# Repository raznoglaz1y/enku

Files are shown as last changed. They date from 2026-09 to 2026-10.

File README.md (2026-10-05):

<p align="center">
  ENKU animated e-paper logo
</p>

<h1 align="center">ENKU</h1>

<p align="center">
  <strong>A pocketable e-reader you can actually own — repairable, local-first, distraction-free.</strong>
</p>

<p align="center">
  A focused, low-power 3.97″ reader with physical controls, local file management, no account or cloud requirement, and a documented, extensible hardware/software stack.
</p>

<p align="center">
  <strong>Project website:</strong> <a href="https://enkureader.com">enkureader.com</a>
</p>

<p align="center">
  <strong>UI languages:</strong> EN · PL · DE · FR · ES · IT · RU
</p>

---

## What is ENKU?

ENKU is a compact e-reader project currently validated around the **Waveshare ESP32-S3-ePaper-3.97** platform with an **800 × 480** e-paper display, while a dedicated portrait-first ENKU mainboard is being developed in parallel. The 3.97″ target is intentional: R0.1 remains a genuinely pocketable reader rather than growing into a small conventional e-reader.

The goal is not to reproduce a full tablet or build a feature-heavy general-purpose device. ENKU is intended to be a **small, calm and purpose-built reader**: fast enough for books, simple to operate, comfortable to use offline, and understandable from both the software and hardware side.

The project is being developed as a complete product system rather than only a firmware demo. It includes:

- firmware and device architecture;
- a complete non-touch UI for physical controls;
- library and reading workflows;
- typography and per-book settings;
- Wi-Fi and local browser-based file management;
- storage and import flows;
- sleep and power-management behavior;
- enclosure development and mechanical iterations;
- reproducible documentation for the hardware, firmware and enclosure;
- a custom ENKU mainboard and costed path toward small-batch community / kit builds.

> **Current status:** firmware architecture and reader runtime are actively implemented, while the custom ENKU R0.1 mainboard is in late routing / pre-production verification. Power routing and the USB-C connector/ESD/CC area have clean native KiCad checkpoints; USB data completion, dock/unrouted closure, final mechanical/electrical audit and the manufacturing package remain before fabrication. Features are only treated as complete when their repository checks or physical validation support that claim.

### Looking for hardware partners and component suppliers

ENKU is currently looking for **hardware partners, distributors and component suppliers** interested in supporting the development of the project.

The most useful forms of support at this stage are:

- Waveshare ESP32-S3-ePaper-3.97 development units;
- Li-Po batteries suitable for a compact e-reader enclosure;
- buttons, switches, fasteners and other enclosure hardware;
- prototype and replacement components for hardware testing;
- project discounts or sample units;
- technical information about supplied components;
- support for future hardware revisions and enclosure prototypes.

Partners can be credited in the project documentation and repository as hardware partners or component suppliers where appropriate.

The goal is to build ENKU around readily available, reproducible parts rather than one-off or inaccessible hardware.

For partnership or supply discussions, please open an issue or contact the project owner through GitHub.

## Custom mainboard and future kits

The reference Waveshare platform is useful for firmware bring-up, but ENKU is also being engineered as its own compact hardware platform.

The custom mainboard roadmap targets:
- ESP32-S3 + 3.97″ e-paper in a portrait-first PCB;
- physical page controls, hard power-off, BMI270 motion/orientation sensing and magnetic-cover support;
- USB-C as the primary charge/data connector;
- optional magnetic pogo/dock charging;
- a warm adjustable frontlight path promoted to production-candidate research after repeated community feedback;
- Pro-ready frontlight and wireless-charging population options;
- one core PCB that can support Base / Cover / Pro variants through DNP/population choices.

After validation, the project may offer small-batch **electronics kits, Base kits, magnetic-cover kits and Pro/frontlight kits**. These are planned possibilities rather than products currently for sale; final contents and pricing depend on tested hardware, sourcing, compliance and fulfillment.

The intent is to keep DIY builds fully documented even if assembled kits become available.

### Product decisions after the first community review

The first broad r/ereader review sharpened the product direction rather than changing the Pocket target. ENKU R0.1 stays at **3.97″**. The strongest recurring feedback was that open source alone is not enough differentiation, so the project is prioritizing the parts that must be better at the hardware/product level: **repairability, physical controls, battery life, screen-to-body ratio, direct USB storage access and a credible warm-frontlight path**.

The firmware roadmap now includes **USB Mass Storage / direct microSD access**, **Markdown reading**, and logical control remapping for left/right-handed use in portrait and landscape. CrossPoint compatibility will be investigated rather than treating community firmware as something ENKU should exclude.

A separate **compact 4.7–5.2″, preferably 4:3** hardware direction is being researched for later; it is not a replacement for the pocket 3.97″ device.

### R0.1 engineering checkpoint — October 2026

The dedicated ENKU mainboard has progressed beyond placement into detailed routing and verification. The current working baseline is intentionally kept **green in native KiCad CI** while remaining USB and dock routing is iterated.

Fabrication is gated on:

- complete USB D+/D− routing through connector-side ESD and series tuning resistors to ESP32-S3;
- dock detect/power closure and an explicit **zero-unrouted-connections** check;
- final power, EPD high-voltage, return-path, antenna keepout, connector-edge and repairability review;
- final footprint/orientation and mechanical-access audit;
- reproducible Gerber, NC drill, BOM and pick-and-place outputs plus a final PCBWay viewer review.

A green DRC alone is not considered a fabrication release: R0.1 must also pass the explicit connectivity and manufacturing gates above.

## Support ENKU

ENKU is developed publicly, while production-sensitive engineering may remain private until it is mature enough to release. You can help the project without spending money:

- **Star the repository** to make the project easier to discover.
- **Test and report issues** when firmware and hardware builds are available.
- **Contribute** code, documentation, translations, UI feedback, hardware notes or enclosure work — see [CONTRIBUTING.md](CONTRIBUTING.md).
- **Share ENKU** with people interested in open hardware, e-paper and compact readers.

GitHub Sponsors is the project's primary funding channel. Sponsorships help cover development hardware, prototype boards, batteries, enclosure iterations and other direct project costs.

**Sponsor ENKU:** https://github.com/sponsors/raznoglaz1y

Project contact and support page: **https://enkureader.com/contact**

## Follow the project

ENKU is entering its first public community-feedback stage. The immediate goal is to validate the reader, the custom R0.1 hardware and the mechanical design with e-reader, maker and repairability communities before any manufacturing commitment is made.

A **small production run / crowdfunding campaign is being considered after hardware validation**, but no campaign, launch date, price or production quantity is being promised yet. Development remains public and technical feedback is welcome now.

- Project site: https://enkureader.com
- GitHub: https://github.com/raznoglaz1y/enku
- Reddit launch draft: [docs/outreach/reddit-r-ereader.md](docs/outreach/reddit-r-ereader.md)
- Hackaday project draft: [docs/outreach/hackaday-project-draft.md](docs/outreach/hackaday-project-draft.md)

## Project goals

ENKU is being designed around a deliberately narrow set of product goals:

- provide a **comfortable, distraction-free reading experience** on a compact e-paper device;
- remain useful **fully offline**;
- use **physical controls** instead of depending on a touchscreen;
- keep book storage, reading progress and settings under the user's control;
- support a clean local workflow for importing and managing books;
- make the firmware, interfaces, hardware assumptions and repair path understandable, with source/design releases tied to product maturity;
- stay small enough to be a practical everyday reader rather than a general-purpose tablet.

## Non-goals

ENKU is **not** intended to become:

- an Android-like general-purpose device;
- a multimedia tablet;
- a cloud-dependent reading service;
- a storefront or DRM ecosystem;
- a notification-heavy connected gadget;
- a platform that hides core reading features behind an account.

The project favors a smaller, coherent feature set over adding functionality that does not improve reading.

## Why ENKU?

### Reading first

The interface is built around one job: **reading**. The reader screen stays visually quiet, controls appear only when needed, and common actions are reachable without navigating through deep menus.

### E-paper from the beginning

ENKU is designed specifically for e-paper constraints rather than adapting a conventional LCD interface afterward. Refresh behavior, focus states, progress updates, sleep screens and interaction density are all treated as part of the product architecture.

### Physical controls, no touchscreen dependency

The UI is designed for buttons and deterministic focus navigation. Focus, selected values and active states are separate concepts, which keeps the interface predictable and accessible without touch.

### Offline by default

Books remain usable without Wi-Fi. Connectivity is an optional management layer, not a requirement for reading.

### Open, understandable and user-owned

The project aims to document not only the final code, but also **why** design and implementation decisions were made. UI rules, navigation behavior and product decisions are documented publicly. Production-sensitive PCB, manufacturing and sourcing work may remain private during active development and be released selectively after the design stabilizes.

### Compact hardware target

A 3.97″ panel keeps the device small enough to carry easily while still providing a practical 800 × 480 reading canvas. Both portrait and landscape orientations are part of the design system.

## Design preview

The interface is being designed in English first and then localized. The boards below are current **EN design previews** from the active UI revision work; they are not yet firmware screenshots.

<table>
<tr>
<td width="50%">ENKU Library grid design preview</td>
<td width="50%">ENKU first-start language design preview</td>
</tr>
<tr>
<td align="center"><strong>Library</strong></td>
<td align="center"><strong>First start / Language</strong></td>
</tr>
<tr>
<td width="50%">ENKU Book details design preview</td>
<td width="50%">ENKU Library list design preview</td>
</tr>
<tr>
<td align="center"><strong>Book details</strong></td>
<td align="center"><strong>Library / List</strong></td>
</tr>
</table>

The production visual source of truth remains the Figma design system and approved review boards.

---

## Target hardware

The current reference platform is:

| Component | Target |
| --- | --- |
| Main board | Waveshare ESP32-S3-ePaper-3.97 |
| MCU | ESP32-S3 |
| Display | 3.97″ e-paper, 800 × 480 |
| Input | Up / Function / Down control + BOOT; PWR handled separately |
| Storage | microSD / local storage workflow |
| Connectivity | Wi-Fi, BLE available at platform level |
| Power | Li-Po battery; final pack and runtime profile to be validated on hardware |
| Enclosure | Custom 3D-printable case, developed after mechanical verification |

The current official Waveshare source maps the active-low navigation inputs to GPIO4 (Up), GPIO5 (Function), GPIO6 (Down) and GPIO0 (BOOT). ENKU keeps raw GPIO details inside the platform layer and maps them to stable logical actions. PWR is treated separately through the PMU. Physical behavior will still be verified on the received board.

### Parts status

| Part | Current status |
| --- | --- |
| Waveshare ESP32-S3-ePaper-3.97 | **Selected / ordered** |
| 3.97″ 800 × 480 e-paper panel | **Part of reference platform** |
| microSD storage | **Platform feature — hardware verification pending** |
| Li-Po battery | **TBD — ~2000 mAh target, final size/connector pending** |
| Physical controls | **Platform controls to be mapped and tested** |
| Power switch / enclosure hardware | **TBD** |
| Fasteners | **TBD after mechanical measurements** |
| 3D-printed enclosure | **Planned after hardware measurement** |

See the detailed [Hardware baseline](docs/hardware.md) and [BOM status](docs/bom.md).

## Planned reader experience

### Library

- grid and list views;
- persistent sort and filter state;
- All / New / Reading / Finished filters;
- Title / Author / Recently opened / Recently added sorting;
- global title/author search independent from the active browse filter;
- bounded/paged result queries for large libraries;
- book details and cover handling;
- reading-state indicators;
- progress persistence;
- empty/error states designed as first-class screens.

### Reading

**Reader v1 formats:** EPUB, FB2 and TXT. PDF is deferred to a later revision.

- distraction-free reading view;
- portrait and landscape;
- semantic position preservation after layout changes;
- table of contents;
- bookmarks;
- in-book search;
- finished-book state;
- restore to the previous reading position.

### Typography

Five built-in presets are planned:

**Spacious · Comfortable · Standard · Compact · Dense**

Each preset controls font size, line spacing and margins. Manual adjustment switches the book to **Custom**. Settings can be global or overridden per book.

The current reading typeface target is **Noto Sans**.

### Local file management

The first management workflow is intentionally local:

- upload one or many books from a browser on the same network;
- drag-and-drop transfer;
- view storage usage and free space;
- inspect and correct metadata;
- replace or remove covers;
- safely delete or replace book files;
- show import progress and errors;
- reset progress or per-book settings.

Reading itself does not depend on this web interface.

### Wi-Fi

Planned Wi-Fi behavior includes:

- saved networks;
- explicit trusted/preferred networks;
- deterministic reconnect behavior;
- password entry using the shared on-device keyboard;
- session-scoped local web management;
- no cloud account requirement.

### Sleep and power

ENKU separates **panel sleep**, **device suspend** and **full PMU power-off**.

- user-facing Sleep means a measured system-level low-power state, not only `EPD_Sleep()`;
- static sleep screens suitable for e-paper;
- optional book-cover sleep screen;
- Wi-Fi off during Sleep;
- no live clock or animation while sleeping;
- auto-sleep suspended during writes/imports;
- full Power Off uses the board PMU shutdown path;
- exact suspend mechanism, wake sources and battery thresholds are validated on real hardware.

---

## Current limitations

ENKU is still in the pre-firmware stage, so several important decisions remain intentionally open:

- there is no production reader firmware yet, but the first framework-neutral TXT parser, forward-pagination, Reader Engine and ReaderSession MVPs are now implemented and host-testable;
- a framework-neutral C++ firmware scaffold now exists under `firmware/`;
- the firmware architecture, Library/storage model, parser abstraction, pagination model and runtime state machine are specified, while hardware integration and reader implementation remain pending;
- Reader v1 is scoped to EPUB, FB2 and TXT; PDF support is deferred and not yet designed;
- the exact CBOR codec library, localization table generator, diagnostics backend and parser/rendering stack are not selected;
- the final system suspend mechanism and wake-source mapping have not yet been measured on the real board;
- partial/region refresh behavior and ghosting thresholds have not yet been measured on the real panel;
- battery model and real-world runtime are not finalized;
- physical button mapping and wake behavior still require hardware testing;
- the enclosure has not been dimensioned from the production board yet;
- current EN design boards are design previews, not screenshots from running firmware.

These are active development items, not hidden assumptions.

## Firmware direction

Firmware has not yet been published as a working reader. The planned implementation is split into clear subsystems so the project can evolve without coupling the UI directly to storage or parser internals.

### Core layers

1. **Hardware abstraction**
   - display driver and refresh policy;
   - buttons and input events;
   - storage;
   - Wi-Fi;
   - battery/power state.

2. **Application state / Library**
   - stable `book_id`-based Library records;
   - bounded Browse/Search query model;
   - library index;
   - current book;
   - reading position;
   - bookmarks;
   - settings;
   - network state.

3. **Reader engine**
   - shared normalized parser/document interfaces;
   - first TXT parser MVP implemented in C++;
   - first forward text-pagination MVP implemented in C++;
   - first concrete DocumentReaderEngine implemented over the paginator;
   - ReaderSession with deterministic visited-page Previous and previous/current/next working-set cache;
   - Reader runtime integration updates AppState/progress and emits PageTurn refresh requests;
   - Open → Reading, Back → Library checkpoint and Finished transitions are now modeled in runtime;
   - concrete TXT book-loader/document-provider owns BookDocument → ReaderEngine → ReaderSession lifetime;
   - EPUB and FB2 parser adapters still pending;
   - normalized metadata/document model;
   - on-demand pagination using a font/text measurement abstraction;
   - typography presets;
   - semantic position mapping;
   - search and table of contents.

4. **Runtime and startup**
   - staged boot with boot-loop detection;
   - Normal / First Start / Recovery boot modes;
   - deterministic book open / page navigation;
   - Reader Menu and Search context;
   - debounced progress persistence;
   - sleep/wake restoration;
   - recoverable error handling.

5. **UI system**
   - reusable status bar, headers, rows, buttons and dialogs;
   - focus navigation;
   - portrait/landscape layout;
   - localization through stable semantic string keys;
   - English fallback with generated compact locale tables;
   - render plans describing only visible changes.

6. **Refresh Manager**
   - Region / Full / Deferred / None update classes;
   - bounded serialized refresh queue;
   - dirty-region coalescing and stale-plan removal;
   - measured ghosting/full-refresh escalation;
   - panel-refresh diagnostics.

7. **Persistence layer**
   - versioned CBOR records;
   - separate Library / settings / per-book state;
   - A/B generation recovery;
   - debounced progress checkpoints;
   - schema migration and integrity validation.

8. **Diagnostics and recovery**
   - stable structured error codes;
   - localized user-facing error mapping;
   - bounded in-memory logs;
   - compact critical/reboot diagnostics;
   - boot-loop detection and Recovery/Safe Mode.

9. **Local management service**
   - upload/import;
   - metadata operations;
   - storage status;
   - safe replace/delete transactions.

A framework-neutral C++ interface scaffold now exists under [firmware/](firmware/). The exact framework, build system, display library and parser stack will be chosen after display bring-up, memory profiling and real-device tests.

---

## Enclosure development

The enclosure is a separate project track, not an afterthought.

The plan is to develop the case in stages:

1. **Mechanical verification**
   - measure the production board;
   - verify display stack height, connectors, controls and battery space;
   - establish safe internal clearances.

2. **Functional prototype**
   - simple printable shell;
   - reliable access to controls and charging;
   - battery retention;
   - serviceable assembly.

3. **Ergonomic iteration**
   - comfortable grip;
   - practical button placement;
   - reduced thickness where mechanically safe;
   - portrait and landscape handling.

4. **Production-ready open model**
   - printable case files;
   - screw/assembly specification;
   - tolerances and print notes;
   - alternative battery/case variants where useful.

No final mechanical dimensions will be published as authoritative until the actual hardware is measured.

---

## Project roadmap

**At a glance:**  
**Design system → Hardware bring-up → Reader MVP → Connectivity → Enclosure → Open release**

### Phase 1 — Product and UI foundation

- [x] Define ENKU product direction
- [x] Select Waveshare ESP32-S3-ePaper-3.97 as reference platform
- [x] Define non-touch interaction model
- [x] Build reusable UI foundations and component rules
- [x] Audit the initial screen set
- [x] Define EN as the canonical UI language
- [ ] Finish canonical EN review boards
- [ ] Complete storage/import and Wi-Fi screen revisions

### Phase 2 — Hardware bring-up

- [ ] Verify board revision and physical controls
- [ ] Bring up the e-paper panel
- [ ] Characterize full/partial refresh behavior and ghosting
- [ ] Verify microSD and persistent storage
- [ ] Measure Active / DisplayIdle / Suspended / PoweredOff current
- [ ] Validate wake/power-off behavior
- [ ] Confirm typography rendering and memory use

### Phase 3 — Reader MVP

- [x] Select Reader v1 formats: EPUB, FB2 and TXT; PDF deferred
- [ ] Implement staged boot coordinator and first-usable-screen checkpoint
- [ ] Implement Refresh Manager queue and render-plan pipeline
- [x] Connect PageNext/PagePrevious runtime events to ReaderSession/AppState
- [x] Implement Reader open/back/finished runtime transitions
- [ ] Connect the firmware scaffold to verified platform drivers
- [x] Add ReaderSession page history/cache and deterministic Previous
- [ ] Expand pagination beyond TXT paragraphs and add real font metrics
- [ ] Implement EPUB/FB2 parsers and complete text layout
- [ ] Implement LibraryService/index and grid/list navigation
- [ ] Implement CBOR persistence and reading-position checkpoints
- [ ] Implement typography presets and Custom mode
- [ ] Add bookmarks and table of contents
- [ ] Add in-book search
- [ ] Add sleep/restore flow

### Phase 4 — Import and connectivity

- [ ] microSD import
- [ ] validation and duplicate handling
- [ ] local Wi-Fi upload
- [ ] browser-based library management
- [ ] metadata and cover editing
- [ ] transactional replace/delete behavior
- [ ] interruption and recovery handling

### Phase 5 — Enclosure

- [ ] Measure final hardware
- [ ] Build first functional case prototype
- [ ] Test battery placement and assembly
- [ ] Refine ergonomics
- [ ] Publish printable enclosure files and assembly notes

### Phase 6 — Release quality

- [ ] Finalize canonical EN string catalog
- [ ] Add RU/PL/DE/FR/ES/IT UI translations
- [ ] Validate missing-key fallback and long translated strings
- [ ] Run portrait/landscape layout validation
- [ ] Test malformed books, missing storage and interrupted transfers
- [ ] Validate reboot and power-loss recovery
- [ ] Validate boot-loop detection, Recovery Mode and diagnostic export
- [ ] Publish reproducible build instructions
- [x] Define software/documentation/hardware licensing model
- [ ] Tag the first public reader release

A more detailed implementation roadmap lives in [ROADMAP.md](ROADMAP.md).

---

## UI and design system

The UI source of truth is being developed in Figma and documented in this repository.

Key rules:

- non-touch interaction;
- focus is not the same as selection;
- both **800 × 480 landscape** and **480 × 800 portrait** are supported;
- 24 px standard screen inset;
- 48 px baseline button/input height;
- safe default focus for destructive dialogs;
- English is the canonical source language;
- e-paper refresh limitations are treated as product constraints.

Useful documents:

- [Project status](docs/status.md)
- [Architecture](docs/architecture.md)
- [Firmware project structure](docs/firmware-structure.md)
- [Input & physical controls](docs/input-model.md)
- [Power, sleep & wake model](docs/power-model.md)
- [Reader runtime & state machine](docs/runtime-state-machine.md)
- [Pagination & rendering model](docs/pagination-model.md)
- [Pagination MVP](docs/pagination-mvp.md)
- [Reader Engine MVP](docs/reader-engine-mvp.md)
- [Reader Session MVP](docs/reader-session-mvp.md)
- [Reader Runtime Integration MVP](docs/reader-runtime-mvp.md)
- [Book Loader / Document Provider MVP](docs/book-loader-mvp.md)
- [Metadata & parser model](docs/parser-model.md)
- [Licensing model](LICENSES.md)
- [Library & storage model](docs/storage-model.md)
- [Library data model & service interface](docs/library-model.md)
- [Persistence backend](docs/persistence-model.md)
- [Localization architecture](docs/localization-model.md)
- [Errors, logging & diagnostics](docs/diagnostics-model.md)
- [Boot & startup architecture](docs/boot-model.md)
- [Refresh Manager & e-paper update policy](docs/refresh-model.md)
- [Hardware baseline](docs/hardware.md)
- [BOM status](docs/bom.md)
- [UI specification](docs/ui-spec.md)
- [UI audit](docs/ui-audit.md)
- [UI revision plan](docs/ui-revision-plan.md)
- [Screen inventory](docs/screens.md)
- [Navigation model](docs/navigation.md)

## Repository structure

```text
assets/
  branding/         ENKU identity assets

design/
  screens/          historical and current UI boards
  renders/          project diagrams and visual references

firmware/
  README.md                firmware scaffold status and entry point
  include/enku/            framework-neutral core/input/reader/service interfaces

docs/
  architecture.md          system architecture
  firmware-structure.md    source layout and module boundaries
  input-model.md            physical controls and logical input mapping
  power-model.md            panel sleep, system suspend and PMU power-off
  runtime-state-machine.md  reader runtime and recovery behavior
  pagination-model.md       text layout and pagination rules
  pagination-mvp.md         first TXT → BookDocument → page implementation
  reader-engine-mvp.md      first BookDocument → Reader PageResult bridge
  reader-session-mvp.md     deterministic Next/Previous session navigation
  reader-runtime-mvp.md     page events → AppState → refresh integration
  book-loader-mvp.md        Library/source → parser → ReaderSession lifecycle
  parser-model.md           metadata normalization and parser abstraction
  storage-model.md          Library identity, state and transactional storage
  library-model.md          book records, browse/search queries and LibraryService
  persistence-model.md      CBOR records, schema versioning and crash recovery
  localization-model.md     string keys, fallback, plurals and locale packaging
  diagnostics-model.md      structured errors, bounded logs and Recovery Mode
  boot-model.md             staged startup, restore and boot-loop handling
  refresh-model.md          render plans, refresh queue and ghosting policy
  hardware.md              verified/planned hardware baseline
  bom.md                   parts/BOM status and sourcing priorities
  status.md                current project status
  UI and interaction specifications

locales/
  README.md          localization source-catalog rules

README.md           project overview
ROADMAP.md          implementation roadmap
NOTICE.md           third-party asset and release notes
```

The `firmware/` directory now contains the framework-neutral interface scaffold. Hardware-specific implementations and build files will be added after verified board bring-up. Hardware and enclosure source directories will be added when those workstreams contain verified material.

## Localization

**English is the canonical/source UI language.**

Planned first localization wave:

- English
- Russian
- Polish
- German
- French
- Spanish
- Italian

The interface language is independent from book content and keyboard input mode.

ENKU uses English as the canonical/fallback string set, stable semantic keys, named placeholders and a lightweight centralized plural system. Human-readable locale sources are intended to be converted into compact runtime lookup tables rather than parsed as JSON on the device.

## Licensing and source-release policy

ENKU uses a scoped multi-license model for material that is published:

- **Firmware/software:** Apache License 2.0
- **Project documentation:** Creative Commons Attribution 4.0 International (CC BY 4.0)
- **Future project-owned hardware/mechanical source:** CERN Open Hardware Licence Version 2 — Permissive (CERN-OHL-P-2.0)

The ENKU name/logo, historical design boards and third-party assets are not automatically covered by those blanket grants. Their scope and release requirements are documented in [LICENSES.md](LICENSES.md) and [NOTICE.md](NOTICE.md).

GitHub language detection is configured through `.gitattributes` so implementation source is represented by its actual code language instead of documentation/design assets dominating repository statistics.

---

<p align="center">
  <strong>ENKU is being built as a real reading device: small, focused, open and understandable.</strong>
</p>

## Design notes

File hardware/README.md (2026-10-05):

# ENKU hardware — public snapshot

**Public hardware development freeze:** October 2026  
**Snapshot head at policy transition:** `6f9cc8b7d036d55ea0e3e6687e241f3453178391`

ENKU has moved to a **delayed-open / selective-open** development model.

The hardware already present in this public repository remains part of the public project history. It is not rewritten or hidden retroactively.

From this point forward, production-sensitive Reader hardware work continues privately until the appropriate release gate.

Private by default:
- active PCB routing / placement;
- production schematic changes;
- Gerbers / drill / pick-and-place;
- factory-ready BOM and sourcing data;
- DFM / assembly optimization;
- test fixtures and production tooling.

This public tree may still receive selected stable hardware documentation and release snapshots later.

See: [Release & openness policy](../docs/release-policy.md).

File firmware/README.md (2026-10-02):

# ENKU Firmware

This directory contains the ENKU firmware architecture scaffold.

**Status:** the framework-neutral core is host-buildable and tested. The first board-specific target now exists under `platform/esp_idf/` for Waveshare ESP32-S3-ePaper-3.97 storage bring-up. It is not yet a complete reader UI firmware.

## Current scaffold

```text
include/enku/
  core/
    types.hpp
    input.hpp
    power.hpp
    persistence.hpp
    localization.hpp
    settings.hpp
    diagnostics.hpp
    boot.hpp
    refresh.hpp
    library.hpp
    events.hpp
    app_state.hpp
  reader/
    document.hpp
    parser.hpp
    txt_parser.hpp
    pagination.hpp
    reader_types.hpp
    reader_engine.hpp
    document_reader_engine.hpp
    reader_session.hpp
    book_loader.hpp
  runtime/
    reader_runtime.hpp
    library_runtime.hpp
    settings_runtime.hpp
    storage_startup.hpp
    boot_restore.hpp
    sleep_wake.hpp
    power_off.hpp
  services/
    services.hpp
  storage/
    state_file_store.hpp
    cbor_reader_checkpoint.hpp
    cbor_library_service.hpp
    cbor_app_context_service.hpp
    cbor_boot_loop_service.hpp
    cbor_settings_service.hpp
    book_import_service.hpp
    staged_book_import_service.hpp
    book_delete_service.hpp
    book_file_store.hpp
    posix_book_file_store.hpp
    stored_book_source_service.hpp
    posix_state_file_store.hpp
```

The first framework-neutral implementations now include the TXT parser, paginator, DocumentReaderEngine, ReaderSession, reader runtime lifecycle (open/page/back/finished), and the first concrete A/B CBOR per-book checkpoint backend with CRC32 recovery, plus a POSIX filesystem adapter and host-side disk integration tests under `tests/`. A first ESP-IDF SDMMC/FAT filesystem adapter now exists under `platform/esp_idf/`, together with a minimal `app_main` storage smoke test. Display/input/power integration remains the next board bring-up work.

Architecture references:

- [System architecture](../docs/architecture.md)
- [Input & physical controls](../docs/input-model.md)
- [Power, sleep & wake model](../docs/power-model.md)
- [Persistence backend](../docs/persistence-model.md)
- [Global settings model](../docs/settings-model.md)
- [Localization architecture](../docs/localization-model.md)
- [Errors, logging & diagnostics](../docs/diagnostics-model.md)
- [Boot & startup architecture](../docs/boot-model.md)
- [Refresh Manager & e-paper update policy](../docs/refresh-model.md)
- [Firmware structure](../docs/firmware-structure.md)
- [Reader runtime](../docs/runtime-state-machine.md)
- [Pagination model](../docs/pagination-model.md)
- [Pagination MVP](../docs/pagination-mvp.md)
- [Reader Engine MVP](../docs/reader-engine-mvp.md)
- [Reader Session MVP](../docs/reader-session-mvp.md)
- [Reader Runtime Integration MVP](../docs/reader-runtime-mvp.md)
- [Book Loader / Document Provider MVP](../docs/book-loader-mvp.md)
- [Parser model](../docs/parser-model.md)
- [Storage model](../docs/storage-model.md)
- [Library data model & service interface](../docs/library-model.md)

The public source language and code/documentation language for firmware is English.

## Host build and tests

The framework-neutral firmware modules can be compiled and tested on a desktop host with CMake:

```bash
cmake -S firmware -B build -DCMAKE_BUILD_TYPE=Release
cmake --build build --parallel
ctest --test-dir build --output-on-failure
```

The host suite currently covers:

- TXT parsing;
- text pagination;
- Reader Engine;
- ReaderSession navigation;
- Book Loader;
- Reader runtime open/page/back/restore lifecycle;
- Library runtime filtering, sorting, search, focus navigation, focused-book open, staged-import flow and transactional delete;
- CBOR A/B checkpoint generation and corruption recovery;
- persistent CBOR Library index, queries, sorting, paging and summary updates;
- A/B global settings persistence with safe-default recovery and cold-boot application;
- TXT import pipeline with format detection, parse validation, content fingerprinting and duplicate rejection;
- transactional staged-file import from `/system/tmp` into canonical `/books/book-<id>.<ext>`;
- storage startup recovery that loads the Library, cleans stale committed tmp artifacts, and preserves ambiguous uploads;
- persisted last-safe app context and automatic cold-boot restore into Reading at the saved semantic checkpoint;
- Sleep checkpointing plus fast context-only Wake restore without repeating the full storage recovery path;
- graceful Power Off persistence before the platform PMU shutdown request;
- persistent boot-loop protection that enters Recovery before a third consecutive incomplete cold boot can auto-restore again;
- rollback of the final book file when Library commit fails;
- transactional book deletion with Library/source/checkpoint/context cleanup and rollback;
- POSIX filesystem persistence for book files and checkpoints.

GitHub Actions runs the same host suite on pushes to `main` and on pull requests.

## ESP-IDF board target

The first Waveshare ESP32-S3-ePaper-3.97 target lives at:

```text
firmware/platform/esp_idf/
```

It currently provides:

- board pin constants for TF, e-paper and navigation controls;
- 4-bit SDMMC FAT32 mount at `/sdcard`;
- creation of ENKU `/books` and `/system/*` directories;
- `EspIdfFileStore` implementing both `StateFileStore` and `BookFileStore`;
- path-traversal rejection;
- a serial storage smoke test in `app_main`;
- a build-verified SSD1677 800×480 monochrome display driver with full, fast and partial refresh modes;
- a PSRAM-backed ENKU display smoke sequence exercising all three refresh paths;
- active-low GPIO button polling with debounce, long-press/repeat generation, screen-aware logical action mapping and runtime dispatch into Library/Reader/power flows;
- AXP2101 power telemetry and shutdown/light-sleep platform service;
- mono framebuffer boundary and concrete e-paper RefreshService with full/fast/partial routing;
- unified ESP-IDF platform composition root owning storage, display, refresh, power and buttons;
- application storage runtime composition for settings, Library, import/delete, checkpoints, boot-loop state and startup recovery;
- FreeType-backed Noto Sans text measurement and monochrome glyph rendering for the Reader pipeline.

See [ESP-IDF platform bring-up](platform/esp_idf/README.md).

The board target is compiled separately in GitHub Actions against ESP-IDF v5.5.5. The first successful platform build covers both SDMMC storage and SSD1677 full-refresh code.

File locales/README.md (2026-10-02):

# ENKU Locales

English is the canonical source language for the ENKU on-device UI.

Planned Reader v1 locale source files:

```text
en.json
pl.json
de.json
fr.json
es.json
it.json
ru.json
```

The actual string catalog will be added once the canonical EN screen copy is finalized.

Rules:

- English defines the complete key set.
- Translation files may not introduce independent UI semantics.
- Named placeholders must match the English source.
- Runtime firmware should consume generated compact lookup data rather than parse these JSON files on every device boot.
- Missing translations fall back to English.

See [Localization Architecture](../docs/localization-model.md).

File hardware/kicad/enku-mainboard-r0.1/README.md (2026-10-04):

# ENKU Mainboard R0.1 — KiCad worktree

This directory contains the CAD worktree for the custom ENKU mainboard.

Current state:
- portrait 54 × 94 mm four-layer PCB;
- mounting-hole baseline;
- ESP32 antenna, Qi, buttons, microSD, USB-C, Dock and hard-power zones;
- first mechanically sensitive component placement has started;
- J_EPD uses the R0.1 dual-contact 24-pin connector baseline;
- J_FL uses the R0.1 dual-contact 6-pin connector baseline;
- EPD 47 µH inductor and boost MOSFET are now represented in the placement;
- Pro frontlight driver zone and remap field are represented;
- no routing yet.

Important:
- schematic capture remains authoritative for nets and final footprint synchronization;
- several footprints in the PCB are marked as R0.1 placement placeholders and must be replaced/verified against manufacturer land patterns before fabrication;
- no KiCad ERC/DRC has been run in the current environment;
- this is **not fabrication-ready**.

Companion:
- [Placement baseline A](PLACEMENT_R01.md)
- `../../../docs/schematic-netlist-r01.md`
- `../../../docs/r01-blocker-closure.md`

Next:
1. capture the complete schematic;
2. assign/verify exact manufacturer footprints;
3. update the PCB from schematic;
4. reconcile the first placement with actual courtyard/keepout data;
5. route;
6. run ERC/DRC in KiCad;
7. generate PCBWay files only from the checked KiCad project.

## Schematic hierarchy

R0.1 now has a real KiCad hierarchical capture baseline:

- `enku-mainboard-r0.1.kicad_sch` — root sheet
- `power.kicad_sch` — USB/Dock arbitration, charger, hard-off 3.3 V path
- `mcu_io.kicad_sch` — ESP32-S3-WROOM-1-N16R8, shared SPI, I2C, buttons, Hall/IMU/ADC assignments
- `epd_hv.kicad_sch` — 24-pin EPD FPC and SSD1677 external-HV interface boundary
- `frontlight.kicad_sch` — TPS923610 path, 6-pin raw FPC and 0R/DNP remap boundary
- `connectors.kicad_sch` — USB-C, dock, debug and DNP Qi interface

These files are schematic-capture baselines, not a fabrication release. The next gate is to expand the remaining block-level circuits into exact discrete symbols, review every footprint, and run KiCad ERC before routing is treated as electrically authoritative.

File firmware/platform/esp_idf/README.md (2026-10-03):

# ENKU ESP-IDF Platform Bring-up

This directory is the first board-specific ENKU target for the Waveshare ESP32-S3-ePaper-3.97.

It now hosts the reference-board composition root used by the persistent ENKU device runtime: SD-backed storage, SSD1677 refresh, physical input, power, Wi-Fi, FreeType rendering and recovery behavior. Hardware-dependent behavior still requires physical validation on the delivered board.

## Verified board assumptions

Current board constants come from the official Waveshare ESP32-S3-ePaper-3.97 documentation/examples.

### TF / SDMMC

```text
CLK  GPIO16
CMD  GPIO17
D0   GPIO15
D1   GPIO7
D2   GPIO8
D3   GPIO18
```

ENKU mounts the FAT filesystem at:

```text
/sdcard
```

and ensures:

```text
/sdcard/books
/sdcard/system
/sdcard/system/state
/sdcard/system/covers
/sdcard/system/tmp
```

### E-paper full-refresh bring-up

```text
BUSY GPIO3
DC   GPIO9
CS   GPIO10
SCLK GPIO11
MOSI GPIO12
RST  GPIO46
```

The current target now drives the SSD1677 panel over SPI3 at 20 MHz using the vendor-confirmed full-refresh sequence.

## Build

Install and activate a current ESP-IDF environment, then:

```bash
cd firmware/platform/esp_idf
idf.py set-target esp32s3
idf.py build
```

## Flash and monitor

```bash
idf.py -p <PORT> flash monitor
```

Exit the monitor with the normal ESP-IDF monitor shortcut.

## Expected first boot

With a FAT32 TF card inserted, serial output should show:

1. ENKU ESP-IDF platform bring-up;
2. free heap at boot;
3. SD/MMC card information;
4. successful mount at `/sdcard`;
5. `Storage smoke test passed`;
6. SSD1677 initialization;
7. `Sending ENKU framebuffer`;
8. `Full refresh complete`;
9. `E-paper smoke test passed`;
10. `ENKU storage + display bring-up complete`.

The storage smoke test creates:

```text
/system/tmp/platform-smoke.txt
```

reads it back, verifies it appears in directory enumeration, and deletes it.

## Platform storage adapter

`EspIdfFileStore` implements both framework-neutral interfaces:

- `StateFileStore`;
- `BookFileStore`.

Logical ENKU paths such as:

```text
/system/settings.a.cbor
/books/book-123.txt
```

are resolved beneath `/sdcard`.

The adapter rejects path traversal containing `..`.

The existing CBOR Library/settings/checkpoint/import code is connected through these filesystem-facing APIs.

## Storage recovery

Removable storage failure is user-visible rather than a silent platform abort.

- display, power, network and controls initialize before the SD mount attempt;
- a mount/init failure shows `SD FAIL / INSERT SD`;
- a mounted volume that cannot create the required ENKU directories is rolled back completely and shows `SD SETUP FAIL / REPAIR SD`;
- recovery retries the SD mount every two seconds;
- once storage becomes usable, the device performs a clean restart and enters the normal boot path.

The reference board does not expose a dedicated card-detect signal to this firmware path, so a failed SDMMC mount is deliberately reported as “not ready” rather than claiming that the card is definitely absent.

## Current limitations

This first target deliberately does not yet:

- instantiate the complete ENKU runtime graph;
- render the e-paper display;
- scan buttons;
- initialize PMU/battery state;
- configure Wi-Fi;
- verify fsync/power-loss durability on the physical TF card.

Those are separate bring-up steps.

## Display smoke screen

The first display test uses a 1-bit 800×480 framebuffer:

```text
48000 bytes
```

Allocation prefers PSRAM and falls back to ordinary 8-bit-capable heap.

The framebuffer is generated by ENKU code and contains:

- a border;
- large `ENKU` text;
- `DISPLAY BRING-UP`;
- `FULL REFRESH`.

The current driver implements:

- SPI3 initialization;
- manual CS/DC control;
- hardware reset;
- BUSY polling with timeout;
- SSD1677 full-mode initialization;
- monochrome RAM write;
- full refresh;
- panel deep sleep.

Fast refresh and partial refresh are deliberately not yet exposed through the ENKU display API. They will be added and tested as separate modes after the baseline full refresh is validated on the physical panel.

## CI

`.github/workflows/esp-idf-build.yml` builds this target independently from the desktop host tests.

Current CI baseline:

```text
ESP-IDF v5.5.5
target: esp32s3
```

This compile check validates the board target and ESP-IDF APIs even before flashing physical hardware.

## Fast and partial refresh smoke path

The SSD1677 adapter now also exposes:

- fast full-screen initialization;
- fast full-screen refresh;
- fast base refresh;
- partial region refresh.

The vendor reference refresh control values are preserved:

```text
full    0x22 = 0xF7
fast    0x22 = 0xD7
partial 0x22 = 0xFF
```

Current bring-up sequence on one boot:

```text
full ENKU screen
→ fast ENKU screen with FAST REFRESH label
→ partial counter 0
→ partial counter 1
→ partial counter 2
→ panel deep sleep
```

The partial test region is 96×96 pixels and byte-aligned. The API validates bounds and region byte count before touching panel RAM.

Physical validation still needs the real board so we can compare actual refresh time, ghosting and whether the vendor partial window behavior matches the panel revision shipped with the unit.

## Input bring-up

The first ESP-IDF input adapter is `EspIdfButtons`.

Board inputs:

```text
Up       GPIO4
Function GPIO5
Down     GPIO6
BOOT     GPIO0
```

They are configured as active-low inputs with pull-ups.

The platform firmware runs a 12-second interactive smoke test after display bring-up. Serial logs show the physical control, generated press type and framework-neutral logical action.

Current timing baseline:

```text
poll      5 ms
debounce 20 ms
long     650 ms
repeat   700 ms initial / 180 ms interval
```

The Power button is intentionally not treated as a normal GPIO button here; it remains part of the PMU/power-control bring-up.

## Power / AXP2101 bring-up

The current board mapping follows the full Waveshare application reference, not the earlier minimal SD example.

```text
SDMMC:
CLK 16
CMD 17
D0  15
D1  7
D2  8
D3  18

I2C:
SDA 41
SCL 42

AXP2101 address: 0x34
```

`EspIdfPowerService` implements the framework-neutral `PowerService` boundary.

Current telemetry:

- battery %;
- battery mV;
- charging;
- external power/VBUS.

Current controls:

- configure PWR-on timing to 1 second;
- configure hardware PWR-off timing to 4 seconds;
- software AXP2101 shutdown;
- ESP32-S3 light sleep with GPIO wake on Up/Function/Down/BOOT.

The bring-up smoke test only reads/logs telemetry. It does not power the board off automatically.

## Platform composition root

`EspIdfPlatform` now owns the board-specific service graph:

```text
EspIdfSdCard
EspIdfFilesystem
EspIdfStateFileStore
EspIdfBookFileStore
EspIdfEpaper
OwnedMonoFramebuffer
EpaperRefreshService
EspIdfPowerService
EspIdfButtons
```

`EspIdfPlatform::begin()` initializes those dependencies in hardware-safe order:

```text
SD mount
→ e-paper transport / RefreshService
→ AXP2101 power service
→ buttons
```

The bring-up `app_main()` now consumes this composition root instead of constructing parallel board drivers itself.

This is intentionally still a **platform** root rather than the final ENKU `DeviceRuntime`: Reader text measurement/rendering and the complete application renderer still need concrete implementations before the full application controller graph can be owned here.

## Application storage layer on ESP-IDF

The ESP-IDF target now links the real ENKU storage/application subset used by `ApplicationStorageRuntime`:

- settings persistence/runtime;
- Library persistence;
- TXT import;
- staged import;
- delete transaction;
- reader checkpoints;
- app restore context;
- boot-loop marker;
- book source;
- storage startup/recovery.

This is the first board build where the same application persistence code tested on desktop is linked against the physical SD-backed adapters.

The remaining application-runtime blocker is no longer persistence. It is the real Reader rendering path: text measurement, font data and screen composition.

## Reader font engine

The ESP-IDF target now depends on Espressif's FreeType component and includes `FreeTypeTextRenderer`.

Default reader font: Noto Sans Regular is embedded directly in the ESP-IDF application image under SIL OFL 1.1.

An optional SD override can still be provided at:

```text
/system/fonts/NotoSans-Regular.ttf
```

If the override is absent or invalid, FreeType falls back to the embedded firmware asset.

The renderer:

- loads the real TTF from FAT;
- measures UTF-8 text with FreeType advances and kerning;
- derives line height from the face metrics;
- rasterizes glyphs in 1-bit monochrome mode;
- writes directly into `OwnedMonoFramebuffer`.

This keeps Reader pagination and physical rendering on the same metric source.

The embedded Noto Sans asset is the deterministic baseline used for pagination and rendering. A broken SD override never blocks boot; an embedded FreeType initialization failure remains a visible recovery condition.

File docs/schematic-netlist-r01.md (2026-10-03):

# ENKU Mainboard R0.1 — schematic net / block specification

Status: **schematic-capture baseline / exact-footprint and ERC review in progress**

Purpose: define the actual electrical structure that the KiCad schematic must implement before placement/routing.

## 1. Power input tree

Named nets:

- `VBUS_USB`
- `VBUS_DOCK`
- `VBUS_EXT`
- `VBAT`
- `VSYS`
- `3V3_SYS`

Flow:

```text
USB-C VBUS -> USB protection -> TPS2121 IN1
Dock +5V   -> Dock protection -> TPS2121 IN2
TPS2121 OUT -> VBUS_EXT -> BQ25185 IN
BQ25185 BAT -> VBAT
BQ25185 SYS -> VSYS
VSYS -> TPS63802 -> 3V3_SYS
```

R0.1 hard power:
- physical switch controls TPS63802 EN;
- charger remains active when 3V3_SYS is off;
- EPD-HV and frontlight must not remain powered when system-off.

## 2. USB-C

References:

- J1 — USB-C receptacle
- U_USB_ESD — USB ESD device
- R_CC1 / R_CC2 — 5.1 kΩ
- optional R_USB_DP / R_USB_DM series footprints

Signals:

- `USB_DP` -> ESP32 GPIO20
- `USB_DM` -> ESP32 GPIO19
- `VBUS_USB`
- `GND`

No USB-PD requirement for R0.1.

## 3. Dock

Board-side exposed contacts:

1. GND
2. +5V
3. DOCK_DETECT
4. GND

Nets:

- `VBUS_DOCK`
- `DOCK_DETECT`
- `GND`

DOCK_DETECT -> GPIO2 through a defined pull/protection network.

Dock power and USB power must not backfeed each other.

## 4. Battery / charge

Reference:
- U_CHG — BQ25185

Nets:
- `VBUS_EXT`
- `VBAT`
- `VSYS`
- `CHG_STAT1`
- `CHG_STAT2`
- `BAT_TS`

Prototype starting point:
- 4.2 V battery regulation;
- 500 mA input-current limit;
- 300 mA initial fast-charge target.

Production battery temperature protection must use the selected battery/NTC solution.

## 5. 3.3 V system regulator

Reference:
- U_3V3 — **TPS63802DLAR**

Nets:
- VIN: `VSYS`
- OUT: `3V3_SYS`
- EN: `SYS_EN`
- L1/L2: `REG_L1` / `REG_L2`
- FB: `REG_FB`
- PG: `REG_PG`

Hard power switch drives `SYS_EN`.

First-spin support network:
- 0.47 µH Murata DFE201612E-R47M=P2;
- 10 µF + 100 nF on input;
- 2 × 22 µF on output;
- 511 kΩ / 91 kΩ feedback;
- 100 kΩ PG pull-up.

The old TPS63031 candidate is intentionally rejected for R0.1 because boost-mode headroom is too small for simultaneous Wi-Fi + microSD + EPD peaks.

## 6. ESP32-S3

Reference:
- U1 — ESP32-S3-WROOM-1-N16R8

Power:
- 3V3_SYS
- GND

Core pin allocation:
- GPIO19 USB D-
- GPIO20 USB D+
- GPIO12 SPI_SCLK
- GPIO11 SPI_MOSI
- GPIO13 SPI_MISO
- GPIO10 SD_CS
- GPIO14 EPD_CS
- GPIO21 EPD_DC
- GPIO47 EPD_RST
- GPIO48 EPD_BUSY
- GPIO4 BTN_PREV
- GPIO5 BTN_NEXT
- GPIO6 BTN_SELECT
- GPIO7 BTN_BACK
- GPIO8 I2C_SDA
- GPIO9 I2C_SCL
- GPIO18 IMU_INT1
- GPIO17 HALL_INT
- GPIO1 BAT_ADC
- GPIO2 DOCK_DETECT
- GPIO15 CHG_STATUS
- GPIO16 QI_STATUS
- GPIO39 FL_WARM_PWM
- GPIO40 FL_COOL_PWM
- GPIO41 FL_ENABLE
- GPIO43 UART_TX
- GPIO44 UART_RX
- GPIO0 BOOT

Do not load strapping pins GPIO0/3/45/46 in a way that changes boot state.

## 7. microSD

Reference:
- J_SD — microSD connector

Mode:
- SPI for R0.1 common-mainboard path.

Signals:
- SPI_SCLK
- SPI_MOSI
- SPI_MISO
- SD_CS

Add:
- local 3V3 decoupling;
- optional series resistor footprints if signal integrity requires tuning;
- card-detect only if the selected connector provides it at acceptable cost.

## 8. EPD logic connector

Reference:
- J_EPD — 24-pin 0.5 mm FPC

Logical nets:
- EPD_CS
- EPD_DC
- EPD_RST
- EPD_BUSY
- SPI_SCLK
- SPI_MOSI
- EPD_GDR
- EPD_RESE
- EPD_VSH1
- EPD_VSH2
- EPD_VGH
- EPD_VGL
- EPD_VSL
- EPD_VCOM
- EPD_VDDIO
- EPD_VCI
- EPD_VDD
- EPD_VPP
- GND

BS1 is intended LOW for 4-wire SPI.

Exact connector pin numbers remain blocked until current GDEY drawings are directly verified.

## 9. EPD-HV block

This block must be drawn as a dedicated schematic sheet.

Named nets:
- EPD_GDR
- EPD_RESE
- EPD_VGH
- EPD_VGL
- EPD_VSH1
- EPD_VSH2
- EPD_VSL
- EPD_VCOM

Required classes of components:
- external N-MOSFET;
- current-sense resistor;
- inductor;
- Schottky network;
- 50 V-class HV capacitors;
- local logic/core decoupling.

Current provisional values may be shown in notes but must carry a `VERIFY-GOOD-DISPLAY` marker.

Preferred R0.1 EPD-HV starting parts:
- Q_HV: SI1308EDL-T1-GE3;
- D_HV1-D_HV3: MBR0530;
- R_RESE: 2.2 Ω / 1% / 0805;
- L_HV: 47 µH, exact production MPN pending;
- C_HV main: 4.7 µF / 25 V / 0805 X5R/X7R;
- C_HV aux: 1 µF / 25 V / 0805 X7R.

No PCBWay order while the current-panel reference has not been checked or while the final inductor/connector orientation remains generic/TBD.

## 10. BMI270

Reference:
- U_IMU — BMI270

Signals:
- I2C_SDA
- I2C_SCL
- IMU_INT1

Power:
- 3V3_SYS

Required:
- VDD/VDDIO decoupling per Bosch reference;
- I²C pull-ups sized for the final bus;
- orientation marker in schematic and PCB notes.

## 11. Hall sensor

Reference:
- U_HALL — DRV5032-family candidate

Signals:
- HALL_INT -> GPIO17

Power:
- select the exact low-power supply configuration after part-variant freeze.

Placement is mechanically tied to Cover magnet geometry.

## 12. Physical controls

References:
- SW_PREV
- SW_NEXT
- SW_SELECT
- SW_BACK
- SW_BOOT
- SW_POWER

Direct GPIO buttons for PREV/NEXT/SELECT/BACK.

No ADC key ladder in R0.1.

SW_POWER controls SYS_EN, not firmware.

## 13. Battery ADC

Net:
- BAT_ADC -> GPIO1

Use a high-value divider sized to minimize standby drain.

Add:
- RC filter;
- ADC protection margin;
- optional switched divider only if power measurements justify the added complexity.

## 14. Pro frontlight

Separate schematic sheet / population option.

References:
- J_FL — 6-pin 0.5 mm FPC
- U_FL_WARM — prototype current driver candidate
- U_FL_COOL — prototype current driver candidate

Signals:
- FL_WARM_PWM
- FL_COOL_PWM
- FL_ENABLE

Power source:
- final choice must avoid bypassing hard-off.

Driver remains prototype candidate until the current FL0426-S01C pin assignment is verified.

## 15. Pro Wireless

Separate DNP population block.

Reference:
- U_QI — BQ51013C-family candidate

Nets:
- `QI_5V`
- `QI_STATUS`

QI_5V must enter the same protected charging architecture rather than charge the cell independently.

Three-source arbitration remains a sub-block to freeze after USB/Dock/Qi interaction is tested.

## 16. Debug / test

Expose:
- UART TX/RX
- BOOT
- EN/reset service access
- GND
- 3V3_SYS
- VSYS
- VBAT
- VBUS_USB
- VBUS_DOCK
- EPD BUSY/RST
- EPD HV rails where safely probeable

Add current-measurement 0 Ω links where useful:
- VSYS -> U_3V3 input
- optional EPD-HV supply input
- optional frontlight supply input

## 17. PCBWay schematic gate

The schematic can move to PCB placement only when:

- every non-DNP component has an exact MPN or an explicitly approved generic passive specification;
- all connector contact orientations are verified;
- EPD-HV exact parts are frozen;
- no unresolved strapping-pin conflict remains;
- ERC passes;
- variant DNP matrix is generated from the schematic/BOM;
- Base, Pro and Pro Wireless can be built from the intended common PCB without bodge wires.

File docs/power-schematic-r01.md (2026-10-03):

# ENKU custom mainboard R0.1 — power sheet candidate

Status: **schematic-level baseline / not fabrication-frozen**

This document turns the current power architecture into a concrete first schematic target.

The goal is not to maximize charging speed. It is to get a predictable, low-risk power path that works for Base / Cover / Pro / Pro Wireless and preserves margin through a common PCB.

## 1. Core architecture

```text
USB-C VBUS ----\
                > input selector / protected OR ---> BQ25185 IN
Dock 5V -------/
Qi 5V ----------> optional Pro Wireless input path

BQ25185 BAT  ---> 1S Li-Po
BQ25185 SYS  ---> TPS63802 VIN
TPS63802 3V3 ---> ESP32-S3 / microSD / logic / control

Hard OFF ---> TPS63802 EN low
```

Important consequence:

The physical hard-off switch no longer needs to interrupt the battery itself.

BQ25185 remains connected to the battery and external power, so charging continues while the system is hard-off.

TPS63802 provides true shutdown / load disconnect, so it is a strong candidate for making the 3.3 V digital rail genuinely off.

EPD-HV and frontlight rails must also be disabled in hard-off. They may not bypass the switched system architecture.

## 2. BQ25185 baseline values

Primary charger:
**BQ25185DLHR**

Official reference:
https://www.ti.com/product/BQ25185

### Battery regulation / input current limit

Initial ENKU target:
- 1-cell Li-Po;
- 4.2 V battery regulation;
- 500 mA external input-current limit.

TI's published design procedure gives:

- **R_ILIM/VSET = 18 kΩ** for 4.2 V regulation and 500 mA input-current limit.

This is the R0.1 starting value.

### Fast-charge current

Prototype target:
- **300 mA initial fast-charge current**

TI's published design example gives:
- **R_ISET = 1 kΩ** for 300 mA fast charge.

Why start at 300 mA:
- lower thermal load on a compact PCB;
- friendly to the current ~2000 mAh battery target;
- safer before the final cell and enclosure thermal path are known.

After the actual battery is selected and temperature is measured, a 500 mA charge profile can be evaluated.

Do not raise charge current just to advertise a faster number.

### Capacitors

Follow the current TI recommendation:
- IN: at least 1 µF after derating;
- SYS: nominal 10 µF, at least 1 µF after derating;
- BAT: at least 1 µF.

R0.1 placement target:
- C_IN: 4.7 µF, X7R/X5R, **25 V**, plus 100 nF;
- C_SYS: 10 µF, X7R/X5R, **25 V**, plus 100 nF;
- C_BAT: 4.7 µF, X7R/X5R, 10 V or higher.

TI specifically recommends considering 25 V-rated ceramic capacitors on IN and SYS because of DC-bias derating.

### CE

/CE is active low.

Baseline:
- default hardware pull-down so charging works without firmware;
- optional GPIO override/test point if later useful.

Charging must not depend on the ESP32 being powered.

### STAT

STAT1 / STAT2 are open-drain outputs.

R0.1:
- expose at least one status signal to an ESP32 GPIO or test pad;
- avoid mandatory always-on LEDs;
- production status LED remains DNP to protect standby power.

### TS / battery temperature

Production target:
- use a real battery NTC / validated thermal network.

Do not ship a production kit with a fixed resistor that defeats battery temperature protection merely to save BOM.

For prototypes, an explicit documented test resistor may be used only while the final battery pack is unresolved.

## 3. 3.3 V rail

First-spin regulator:
**TPS63802DLAR**

Official reference:
https://www.ti.com/product/TPS63802

Why R0.1 moved away from TPS63031:
- TPS63031 has insufficient boost-mode margin for an intentionally simultaneous ESP32-S3 Wi-Fi + microSD + e-paper workload;
- ENKU should not depend on firmware preventing peak loads from overlapping;
- TPS63802 provides materially more transient/current headroom while preserving buck-boost operation from a 1S Li-Po.

R0.1 baseline:
- VIN: `VSYS`;
- VOUT: `3V3_SYS`;
- EN: `SYS_EN`;
- MODE: LOW for power-save mode;
- PG: `REG_PG`, pulled up with 100 kΩ for diagnostics;
- inductor: **Murata DFE201612E-R47M=P2, 0.47 µH**;
- input: 10 µF + local 100 nF;
- output: **2 × 22 µF**, X5R/X7R, with DC-bias derating checked;
- feedback: **511 kΩ / 91 kΩ** for the 3.3 V target.

Layout rule:
- input/output capacitors sit directly at the converter pins;
- L1/L2-to-inductor loop is extremely short;
- FB divider stays on the quiet side of the converter and away from L1/L2/SW copper;
- power ground and control ground join locally at the IC, not through a long shared return.

### EN / hard power

Preferred architecture:
- hard switch drives TPS63802 EN;
- EN OFF = `3V3_SYS` physically disabled;
- BQ25185 remains alive so battery charging still works.

Add:
- deterministic EN pull state;
- service/test pad on `SYS_EN`;
- test point on `REG_PG`;
- no firmware dependency for true hard-off.

### Current-margin gate

Before production freeze, stress the rail with:
- ESP32-S3 Wi-Fi transmit burst;
- microSD write;
- e-paper refresh;
- Pro frontlight control activity where applicable;
- battery near the low end of the allowed operating range.

Pass criteria are based on measured 3.3 V droop, reset margin and regulator temperature, not merely on nominal current sums.

## 4. USB-C and Dock source selector

Quality-baseline candidate:
**TPS2121**

Official reference:
https://www.ti.com/product/TPS2121

R0.1 intent:
- USB-C VBUS on IN1;
- Dock 5 V on IN2;
- OUT feeds BQ25185 IN;
- source selection configured so reverse current between USB and Dock is blocked;
- current limit chosen above ENKU's normal charging/system demand but below connector/trace safety limits.

Exact PR1 / CP2 / ILM component values are not frozen until the final source-priority behavior is selected.

### Cost-down checkpoint

Before production:
- compare TPS2121 against qualified discrete ideal-diode / MOSFET OR-ing.

Keep TPS2121 unless the discrete solution:
- saves a meaningful amount at 50–100 units;
- preserves reverse-current blocking;
- is safe with simultaneous USB + Dock;
- does not add more placement/test/support cost than it saves.

## 5. USB-C input

USB-C remains USB 2.0 device + charging input.

Keep:
- 5.1 kΩ Rd on CC1;
- 5.1 kΩ Rd on CC2;
- USB ESD protection;
- D+/D- series damping only if required by ESP32-S3 reference design/layout.

VBUS must go into the source-selection / charger path, not directly onto the system rail.

## 6. Dock interface

Four exposed contacts remain the target.

R0.1 electrical allocation:

1. GND
2. +5 V
3. DOCK_DETECT
4. GND

Reason for two ground contacts in R0.1:
- robust first-make / last-break behavior is easier to design mechanically;
- lower contact resistance;
- no need to invent a data bus before the accessory protocol exists.

Future revisions may reuse contact 4 for accessory ID only after mechanical validation.

DOCK_DETECT:
- resistor-coded / dedicated detection;
- input protection;
- GPIO with defined pull state;
- must distinguish Dock Mode from normal USB charging.

## 7. Pro Wireless Qi path

Preferred system architecture:

```text
Qi receiver -> regulated ~5 V -> common external-source path -> BQ25185
```

Candidate receiver:
**BQ51013C family**

Do not use a second independent battery charger unless there is a demonstrated reason.

### Three-source issue

TPS2121 has two inputs.

For Pro Wireless the architecture therefore needs one of:

A. USB + Dock through TPS2121, then ideal-diode OR with Qi before BQ25185;

B. USB + Dock passive/ideal-diode combination, with TPS2121 selecting wired vs Qi;

C. a different 3-input architecture if it proves cheaper/smaller.

This decision is intentionally not frozen yet.

## 8. Pro frontlight electrical envelope

Display:
**GDEY0426T82-FL01C**

R0.1 frontlight baseline:
- **TPS923610DRLR** boost LED driver;
- **TDK VLS252012HBX-100M-1, 10 µH**;
- **15 Ω / 1%** current-sense baseline;
- **4.7 µF / 50 V** output capacitor;
- BSS138-family warm/cool return selectors;
- master `FL_ENABLE` plus independent `FL_WARM_PWM` / `FL_COOL_PWM`;
- 6-pin dual-contact **FH34SRJ-6S-0.5SH(50)** connector;
- 18-position DNP 0 Ω remap matrix so first-article FPC continuity can be corrected without a PCB respin.

The exact warm/cool FPC mapping stays a first-article population decision until the delivered panel is continuity-checked.

## 9. E-paper HV status

The SSD1677 external HV topology is now captured in the R0.1 schematic.

Current 3.97-inch application-circuit baseline:
- `L_EPD`: **TYS5040100M-10, 10 µH**;
- `Q_EPD`: IRLML6346TRPBF;
- D1/D2/D3: MBR0530;
- `R_RESE`: 2.2 Ω / 1%;
- `R_GDR_PD`: 1 MΩ;
- local 4.7 µF booster input capacitor;
- rail capacitors on VGH/VGL/VSH1/VSH2/VSL/VCOM.

The older 47 µH TYS5040470M-10 is no longer the default. It remains a laboratory alternate only because it shares the TYS5040 land pattern.

Production still requires scope validation of VGH/VGL/VSH/VSL/VCOM on first hardware.

## 10. Power BOM freeze gates

Power sheet becomes production-frozen only after:

- final battery part selected;
- BQ25185 thermal charge test;
- USB + Dock simultaneous-source test;
- hard-OFF charging test;
- TPS63802 simultaneous peak-load / droop / thermal test;
- sleep leakage measurement;
- Hall wake/sleep validation;
- Pro frontlight dimming / thermal / optical test;
- Pro Wireless Qi thermal / alignment / interoperability test;
- EPD-HV first-article rail validation.

Until then, this document is the **preferred engineering baseline**, not a fabrication authorization.

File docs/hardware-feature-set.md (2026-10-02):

# ENKU hardware feature set and product variants

Status: **design target / not yet fabrication-frozen**

This document captures the hardware and enclosure decisions that should be supported by the ENKU custom mainboard and firmware.

## Core product principles

ENKU is a portrait-first, read-first e-reader with physical controls. The base mechanical orientation is portrait; landscape remains a software-supported secondary orientation.

The custom mainboard should be designed once and reused across several enclosure/product variants wherever practical. Optional features should therefore use DNP/population options rather than forcing separate PCBs.

## Common R0.1 / R0.x hardware targets

- ESP32-S3-WROOM-1-N16R8
- 3.97-inch 800x480 e-paper display
- microSD
- native USB-C at the **bottom center**
- reserved low-profile magnetic/pogo charging-dock input as an optional secondary 5 V source
- wireless charging support reserved for a future Pro/accessory implementation rather than mandatory Base hardware
- 1S Li-Po
- physical **hard power-off switch at the top-left**
- right-side physical reading controls
- BMI270 6-axis IMU
- Hall sensor footprint for magnetic cover wake/sleep
- reserved frontlight driver + PWM/EN signals for future illuminated variant
- battery voltage measurement
- debug/test pads
- 4-layer PCB
- ESP32 antenna keepout at PCB edge
- EPD HV/analog block based only on validated panel reference design

## Controls and ergonomics

### Right-side reading controls

Preferred physical layout:

1. Previous page
2. Next page
3. Select / Menu
4. Back

Previous/Next are intended to be implemented as a large two-way rocker or two large tact switches under one rocker cap.

Design goals:
- Next should sit closest to the natural resting position of the thumb.
- Select and Back should be smaller and tactually distinct.
- Page-button mapping must be user-remappable.
- Holding Previous/Next may provide accelerated list scrolling.
- Controls remain usable without looking at the device.

### Orientation and handedness

BMI270 enables:
- automatic portrait/landscape detection
- 180-degree portrait flip
- automatic left-hand/right-hand operation
- remembering the last orientation
- optional motion wake
- optional gesture page turning

The UI should support:
- Auto
- Portrait lock
- Landscape lock
- Remember last orientation

When the reader is rotated 180 degrees, logical Next/Previous behavior should follow the new hand position rather than the original physical top/bottom mapping.

## Motion controls

Motion page turn is optional and disabled by default.

Settings target:
- Gesture page turn: Off / On
- Gesture sensitivity: Low / Medium / High
- Wake on pick-up: Off / On
- Auto rotation: Off / On

Initial gesture concept:
- short deliberate left/right flick
- accelerometer wake trigger
- temporary gyro confirmation window
- direction/rebound validation
- cooldown to prevent double page turns
- reject movements associated with ordinary grip adjustment

Physical page controls always remain available; motion control never replaces them.

## Custom mainboard and kit roadmap

The Waveshare board remains the reference platform for early firmware and electrical validation, but ENKU is now also developing a dedicated portrait-first custom mainboard.

Goals for the custom board:
- lower per-unit cost at small production quantities;
- better enclosure fit than a general-purpose development board;
- native placement of the page rocker, hard power switch, BMI270, Hall sensor and future frontlight circuitry;
- a reproducible BOM suitable for community builds and possible assembled kits;
- one PCB with population options for Base / Cover / Pro rather than separate electronics for every enclosure.

Possible future product formats, only after hardware validation:
- **Electronics kit** — assembled mainboard + display + controls/hardware;
- **Base kit** — electronics + battery + printable/finished enclosure hardware;
- **Cover kit** — Base kit plus magnetic folio;
- **Pro kit** — frontlight-populated electronics and matching optical/mechanical parts.

These are a development and commercialization roadmap, not a statement that kits are currently for sale. Final kit contents, pricing, safety/compliance work and fulfillment model must follow prototype validation.

## Charging interfaces

USB-C remains the primary and universal charging/data connector.

The board should also reserve a secondary charging input so the enclosure family can support a dock without redesigning the whole PCB.

Preferred secondary interface:
- **4-contact magnetic pogo/dock connector** on the lower rear or lower edge;
- two contacts may be paralleled for +5 V / GND or the extra contacts can be used for dock detect / accessory ID;
- connector should be keyed/asymmetric so reverse placement cannot swap polarity;
- secondary 5 V input must be isolated/ORed with USB-C VBUS before the charger/power-path stage.

Wireless charging is a **Pro / optional population target**, not a Base requirement:
- reserve coil area and receiver/charger pads or a small receiver-module interface;
- validate coil, ferrite shield, heat and magnet interaction in the final enclosure;
- avoid placing the Qi coil in the ESP32 antenna keepout or directly under sensitive e-paper circuitry;
- do not promise Qi certification until a complete receiver implementation is tested.

Cost rule: Base ENKU should not carry the full BOM/assembly cost of wireless charging. Pogo charging may be a low-cost accessory option; Qi should be DNP or implemented in Pro.

## Hard power architecture

The top-left switch provides a real hardware system-off state.

Target behavior:
- ESP32, microSD and e-paper system rails are disconnected in OFF.
- USB-C charging remains available while the reader is switched OFF.
- Daily operation uses sleep/wake.
- Hard OFF is intended for storage, travel, service and complete shutdown.

## Magnetic cover support

The mainboard should include a low-power Hall sensor footprint and suitable interrupt routing.

Target UX:
- opening magnetic cover wakes ENKU
- closing cover puts ENKU to sleep
- feature may be disabled in Settings
- hard power switch remains independent

The cover magnet location must be defined jointly with the enclosure after Hall sensor placement is frozen.

## Frontlight-ready architecture

The base PCB should reserve:
- frontlight driver footprint
- PWM signal
- EN signal
- LED power rail connection
- connector/test pads for the light guide / LED assembly

Base ENKU ships with these parts DNP.

The illuminated variant may populate them without requiring a fundamentally different mainboard.

Frontlight settings target:
- Brightness
- Quick-menu brightness control
- Auto-off with sleep
- Optional low-brightness night preset

Color-temperature mixing is explicitly out of scope for the first frontlight revision unless testing proves that the extra LEDs, driver channels and optical stack are worthwhile.

## Enclosure/product variants

### 1. ENKU Slim

Purpose: simplest, lightest and cheapest build.

- portrait-first
- no cover attached
- no frontlight
- hard power top-left
- USB-C bottom-center
- right-side page rocker + Select + Back
- BMI270 motion/orientation support
- Hall sensor may remain populated or DNP depending final cost
- thin 3D-printable shell

This is the reference open-source enclosure.

### 2. ENKU Grip

Purpose: maximum one-hand comfort.

- same electronics as Slim
- slightly wider grip area on the control side
- sculpted / chamfered rear grip
- larger rocker cap
- center of mass biased toward the lower-middle part of the device
- reversible 180-degree operation for left-hand use

This enclosure prioritizes reading comfort over visual symmetry.

### 3. ENKU Cover

Purpose: everyday carry and screen protection.

- magnetic folio cover
- Hall-sensor wake/sleep
- magnetic closure
- cover magnet positioned away from IMU and sensitive power/display circuitry
- case geometry protects page controls from accidental presses
- USB-C remains accessible with cover installed
- optional stand/fold geometry may be explored later

The cover should be removable/replaceable and should not require a different PCB.

### 4. ENKU Pro

Purpose: premium reading variant while preserving the same software/platform.

Includes:
- frontlight optical stack
- populated frontlight driver
- brightness controls
- Hall sensor as standard
- Cover compatibility as standard
- BMI270 motion/orientation controls
- same physical page-button philosophy

The main engineering difference from base ENKU is the display/frontlight stack and populated lighting circuit, not the compute platform.

## Mechanical priorities shared by all variants

- portrait is the primary orientation
- screen centered visually rather than forcing chassis symmetry
- right-side control/grip area may be wider than left bezel
- battery placement should keep center of mass near the lower-middle area
- bottom USB-C must not interfere with little-finger support
- hard power switch must be difficult to trigger accidentally
- page controls should be quiet, low-travel and easy to identify by touch
- enclosure should allow display replacement without destroying the PCB
- antenna area must remain free of metal, magnets and dense copper

## PCB population strategy

A single board should ideally support:

| Feature | Base | Cover | Pro |
| --- | --- | --- | --- |
| BMI270 | populated | populated | populated |
| Hall sensor | optional/populated | populated | populated |
| Frontlight driver | DNP | DNP | populated |
| Frontlight connector | populated/test pads | populated/test pads | populated |
| Hard power | populated | populated | populated |
| Right-side buttons | populated | populated | populated |

This keeps the open-source platform coherent and avoids maintaining separate firmware/hardware branches for every case.

## Next hardware steps

1. Rotate the board concept to portrait-first mechanical orientation.
2. Re-place USB-C to bottom center and hard power to top-left.
3. Place page controls on the right-side edge for thumb reach.
4. Place BMI270 close to the mechanically stable center region.
5. Add Hall sensor candidate location and keep magnet keepout in enclosure CAD.
6. Reserve the frontlight driver/connector area as DNP.
7. Keep EPD HV/analog block reserved until the panel reference design is validated.
8. Add a costed 4-pin pogo/dock charging footprint and input-protection/OR-ing reservation.
9. Reserve Pro-only wireless charging coil/receiver geometry without burdening Base BOM.
10. Produce a new portrait-first Gerber placement preview and keep a per-variant BOM/cost model.

## ENKU Dock and Dock Mode

A separate optional ENKU Dock is now part of the hardware roadmap.

The mainboard should reserve a protected 4-contact pogo interface on the lower rear of the reader. Dock presence should be detected explicitly so firmware can distinguish a desk dock from ordinary USB charging.

While docked, ENKU may enter a configurable low-refresh dashboard mode with options such as:
- clock / date / battery;
- current book and reading progress;
- reading-goal dashboard;
- cached weather or local status cards;
- user-defined static text/dashboard presets.

The first dock should stay passive: pogo contacts, alignment magnets/mechanics and USB-C power input. No dock MCU is required.

See [Dock and Dock Mode](dock-mode.md) for the electrical, firmware and validation plan.

## Display family strategy

### Base / Electronics / Cover

Primary display candidate: **Good Display GDEY0397T81P**

- 3.97-inch
- 800 × 480
- approximately 235 ppi
- SSD1677
- no frontlight
- 24-pin 0.5 mm FPC

Source:
https://www.good-display.com/product/613.html

### Pro / Pro Wireless

Primary display candidate: **Good Display GDEY0426T82-FL01C**

- 4.26-inch
- 800 × 480
- approximately 218 ppi
- SSD1677
- bonded warm/cool frontlight
- 24-pin EPD FPC + separate frontlight FPC

Source:
https://www.good-display.com/product/880.html

The older GDEQ0426T82-FL01C is treated as legacy/EOL and should not be the new design target.

Replacement reference:
https://www.good-display.com/product/1208.html

The design goal is to keep one core mainboard for both display families where the verified FPC pinout, HV requirements and mechanics allow it.

## Variant BOM ceilings

Internal design stop-limits:

| Variant | Landed BOM ceiling |
| --- | ---: |
| Electronics Kit | PLN 155 |
| Base | PLN 180 |
| Cover | PLN 200 |
| Pro | PLN 230 |
| Pro Wireless | PLN 260 |
| Dock | PLN 40 |

These values are not announced retail prices. They are engineering constraints used before final routing.

See:
- [Competitive analysis](competitive-analysis-2026-10.md)
- [Multi-variant BOM architecture](bom-architecture.md)

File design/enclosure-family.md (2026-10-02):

# ENKU enclosure family

Status: concept specification for future CAD work.

The enclosure family is intentionally based on one main PCB wherever possible.

## Common physical language

All variants share:
- portrait-first layout
- bottom-center USB-C
- top-left hardware power switch
- right-side page controls
- 3.97-inch display
- compact rounded enclosure
- replaceable rear shell
- printable prototype geometry

## Variant A — Slim

Reference open-source shell.

Target character:
- minimal
- light
- inexpensive
- easy to print
- easy to disassemble

Suggested construction:
- front bezel/frame
- PCB/display carrier
- rear shell
- four M2 fasteners or snap-fit + limited fasteners

No permanent cover or frontlight.

## Variant B — Grip

Ergonomic one-hand shell.

Changes from Slim:
- wider right-hand grip zone
- gentle rear bulge or wedge around the palm
- larger page rocker cap
- slightly deeper local cavity around buttons
- battery positioned to avoid top-heavy balance

The device can be rotated 180 degrees for left-hand operation.

## Variant C — Cover

Slim/Grip-compatible magnetic folio.

Elements:
- replaceable magnetic front flap
- Hall wake/sleep magnet
- magnetic closure point
- protective lip around display
- relief around hardware power switch
- button guard geometry to reduce presses in a bag

The magnet must be tested for interference and its final position must follow Hall-sensor placement.

## Variant D — Pro

Illuminated version.

Changes:
- frontlight light guide / diffuser stack
- LEDs and light-management geometry
- potentially slightly thicker front bezel
- populated frontlight electronics
- Hall sensor and cover support standard

A Pro Cover may share the same external attachment strategy as Cover if thickness permits.

## CAD deliverables planned

For each variant:
- STEP
- STL
- exploded assembly render
- dimension drawing
- printable prototype profile
- button-cap/rocker part
- battery pocket definition
- PCB mounting points

Cover-specific:
- folio front
- hinge
- magnet pockets
- Hall alignment drawing

Pro-specific:
- frontlight stack cross-section
- LED/light-guide carrier
- thermal/optical clearance model

## Design rule

Case concepts must follow the PCB and display stack. Do not distort the board solely to make a render look cleaner; mechanical and electrical constraints stay authoritative.

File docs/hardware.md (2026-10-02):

# ENKU Hardware Baseline

This document tracks the current hardware target and separates **verified facts** from **planned or unverified choices**.

## Reference platform

| Area | Current target | Status |
| --- | --- | --- |
| Main board | Waveshare ESP32-S3-ePaper-3.97 | Selected / ordered |
| MCU | ESP32-S3 | Platform-defined |
| Display | 3.97″ e-paper, 800 × 480 | Platform-defined |
| Input | Physical controls, non-touch UI | GPIO mapping implemented; physical feel to verify |
| Storage | microSD / local file workflow | SDMMC/FAT platform adapter implemented; hardware timing to verify |
| Connectivity | Wi-Fi / BLE capability | Wi-Fi STA lifecycle implemented; BLE deferred |
| Battery | ~2000 mAh Li-Po target | Final pack TBD |
| Charging | Board-integrated behavior | To verify |
| Enclosure | Custom 3D-printable case | Starts after measurement |

## What will be verified on arrival

### Board and controls

- exact production revision;
- onboard control type and mapping;
- GPIO behavior where relevant;
- wake-capable inputs;
- connector placement.

### Display

- actual usable refresh modes;
- full-refresh time;
- partial-refresh support and limits;
- ghosting behavior;
- contrast in real reading layouts;
- effect of repeated UI updates.

### Storage

- microSD wiring and interface;
- filesystem support;
- file size / performance limits;
- safe-write behavior during power loss.

### Power

- charging behavior;
- active current;
- reading/idle current;
- sleep current;
- wake behavior;
- practical battery runtime;
- battery voltage/percentage mapping.

## Battery target

The working target is a **single-cell 3.7 V Li-Po around 2000 mAh**, thin enough for a compact reader enclosure.

A previously considered mechanical envelope is approximately **5 × 50 × 60 mm**, but this is not yet a final specification.

Final selection depends on:

- real internal space after board measurement;
- connector type and polarity;
- board charging limits;
- protection circuit;
- thermal/mechanical clearance;
- enclosure thickness target.

No battery model should be treated as final until physically validated.

## Mechanical verification

Before starting the final enclosure, record:

- PCB outline;
- display active area and glass outline;
- total display stack thickness;
- board/display offsets;
- connector protrusions;
- control travel and access;
- screw/mounting features;
- battery keep-out area;
- cable bend radii;
- safe bezel overlap.

The enclosure will be based on these measurements rather than catalog assumptions.

## Planned enclosure variants

The first goal is **one reliable baseline case**.

Only after that is stable, possible variants may include:

- different battery thickness/capacity;
- alternative back shell;
- stand/cover attachment;
- revised button geometry.

The project will avoid fragmenting into many mechanical variants before the baseline design is proven.

## Vendor-confirmed controls

Current official Waveshare source identifies the onboard navigation inputs as active-low GPIOs with pull-ups:

| Control | GPIO | Current vendor naming |
| --- | ---: | --- |
| Up | GPIO4 | Button_Up |
| Function / press | GPIO5 | Button_Function |
| Down | GPIO6 | Button_Down |
| BOOT | GPIO0 | Boot |

The official ESP-IDF example polls these controls with a 5 ms timer and a software button state machine rather than GPIO interrupts.

The PWR key is handled through the AXP2101 PMU path. The current vendor example configures a 1 s power-on press and a 4 s hardware power-off press.

ENKU's logical mappings are documented in [Input & Physical Controls](input-model.md). These source-derived mappings will still be physically verified on the production board when it arrives.

## Vendor-confirmed power behavior

The current official Waveshare application distinguishes panel sleep from full PMU shutdown:

- `EPD_Sleep()` sends the e-paper controller into deep sleep, but the ESP32 application continues running;
- the current full vendor application does not use ESP32 deep sleep as its normal product sleep flow;
- full software power-off calls the AXP2101 shutdown path;
- the vendor PMU setup uses approximately 1 s PWR hold for power-on and 4 s for hardware power-off.

ENKU therefore treats **DisplayIdle**, **Suspended** and **PoweredOff** as separate product states.

The final suspend mechanism and wake sources remain pending real-board measurements. See [Power, Sleep & Wake Model](power-model.md).

## First ESP-IDF bring-up target

ENKU now has an isolated board target under `firmware/platform/esp_idf`.

The board-specific target now covers storage, display, input, PMU, Wi-Fi and the first application runtime.

The current board mapping follows Waveshare's **complete board application reference** rather than the earlier minimal e-paper example.

### TF / SDMMC

| Signal | GPIO |
| --- | ---: |
| CLK | 16 |
| CMD | 17 |
| D0 | 15 |
| D1 | 7 |
| D2 | 8 |
| D3 | 18 |

The target uses 4-bit SDMMC and mounts FAT at `/sdcard`.

The earlier minimal Waveshare example used GPIO39–44 for SDMMC; ENKU does **not** use that mapping because the complete board reference reserves GPIO41/42 for I²C/AXP2101.

### E-paper pins

| Signal | GPIO |
| --- | ---: |
| BUSY | 3 |
| DC | 9 |
| CS | 10 |
| SCLK | 11 |
| MOSI | 12 |
| RST | 46 |

These display pins are now used by the first ENKU SSD1677 driver. The current milestone implements vendor-aligned SPI3 full-refresh initialization, monochrome framebuffer transfer, BUSY timeout handling and panel deep sleep.

The storage adapter implements the same `StateFileStore` and `BookFileStore` contracts used by the host-tested persistence/runtime code. The current ESP-IDF target now links that application persistence layer directly against the physical SD-backed adapters.

## SSD1677 full-refresh baseline

The first ENKU panel driver now follows the Waveshare reference full-refresh path:

```text
reset
→ BUSY ready
→ SWRESET
→ SSD1677 full-mode registers
→ 800×480 RAM window
→ write 1-bit framebuffer
→ display update
→ BUSY ready
→ deep sleep
```

The ESP-IDF target uses SPI3 mode 0 at 20 MHz with manual CS, matching the current official Waveshare example.

The driver is compile-verified in GitHub Actions against ESP-IDF v5.5.5. Physical refresh quality, orientation, timing and ghosting still require validation on the delivered board.

## Fast and partial refresh baseline

The platform driver now includes the Waveshare reference refresh modes in addition to full refresh.

Fast mode uses the vendor fast initialization sequence and update control `0xD7`.

Partial mode programs a byte-aligned RAM window, writes only the region buffer, and triggers update control `0xFF`.

The current smoke firmware deliberately exercises all three modes in one boot so physical bring-up can verify:

- full-refresh orientation and mapping;
- fast-refresh latency and ghosting;
- partial-window coordinates;
- repeated partial update artifacts.

## Corrected full-board SD / I2C mapping

The complete official Waveshare firmware for this board uses a different SDMMC pin map from the early/basic e-paper example.

For ENKU board integration we now follow the full board reference:

### SDMMC

| Signal | GPIO |
| --- | ---: |
| CLK | 16 |
| CMD | 17 |
| D0 | 15 |
| D1 | 7 |
| D2 | 8 |
| D3 | 18 |

### Shared board I2C

| Signal | GPIO |
| --- | ---: |
| SDA | 41 |
| SCL | 42 |

The AXP2101 PMU address is `0x34`.

This resolves the apparent GPIO41/42 conflict: it came from mixing the minimal e-paper example's SD map with the complete board firmware's I2C map.

## AXP2101 power baseline

The first ENKU ESP-IDF power service now talks directly to AXP2101 through the native ESP-IDF I2C master driver.

Current capabilities:

- battery percentage;
- battery voltage;
- charging state;
- external/VBUS power presence;
- vendor-aligned PWR on/off timing setup;
- software PMU shutdown;
- light-sleep request with GPIO wake on navigation controls.

The firmware smoke test reads and logs power telemetry but deliberately does **not** call software shutdown automatically.

## RefreshService integration

The SSD1677 driver is now wrapped by `EpaperRefreshService`, which implements the framework-neutral `RefreshService` contract.

This is the first point where application runtime refresh requests are translated into physical panel behavior.

The renderer/display boundary uses a 1-bit `MonoFramebufferSource`; the current owned implementation stores the full 800×480 frame and can extract byte-aligned dirty regions for partial updates.

## Current integrated device runtime

The ESP-IDF board target now composes:

```text
SDMMC/FAT
→ state + book stores
→ CBOR settings/library/checkpoints/context
→ storage startup/recovery
→ Noto Sans / FreeType measurement + rendering
→ Library + Reader runtime
→ 1-bit framebuffer
→ EpaperRefreshService
→ SSD1677
```

Physical controls are polled every 5 ms and flow through:

```text
GPIO
→ PhysicalInputEvent
→ LogicalAction
→ InputDispatcher
→ Library / Reader / Sleep-Wake / Power-Off
```

The application path is persistent rather than a finite smoke script. With the Reader font provisioned on the TF card, firmware renders the initial Library and then remains in the device input loop.

Hardware smoke tests remain available behind `CONFIG_ENKU_BRINGUP_SMOKE_TESTS` while the first physical unit is being validated.

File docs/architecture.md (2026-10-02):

# ENKU Architecture

This document describes the intended high-level architecture of ENKU before the firmware implementation is locked down.

The goal is to keep the reader understandable, testable and modular: display/input/storage code should not leak into book parsing, and reader logic should not depend directly on the web-management layer.

## Architectural decisions

The following decisions are now part of the ENKU firmware baseline:

1. **Event-driven UI**  
   ENKU does not use a continuous frame/redraw loop. Button presses, navigation, page turns, setting changes, Wi-Fi events, import events and power events produce application events. Rendering happens only when visible state actually changes.

2. **Single application state model**  
   Logical product state is centralized rather than duplicated inside screens. This includes current screen, current book, semantic reading position, orientation, focus, Library view/filter/sort, global settings, per-book settings, Wi-Fi state and power state.

3. **Reader Engine is independent from UI**  
   The UI requests laid-out reading content from the Reader Engine. Parser/layout/pagination internals remain separate from screen code.

4. **Semantic reading position instead of page number**  
   Reading progress is anchored to book structure/text position rather than a rendered page index. Page numbers are unstable because typography, margins and orientation can change pagination.

5. **Dedicated Refresh Manager**  
   UI code describes what became dirty; a separate refresh layer decides whether to use a regional/partial update, a full update, combine updates, or defer them.

6. **No invisible redraws**  
   If application state changes but nothing visible on the current screen changes, the e-paper panel is not refreshed. For example, saving reading progress or a hidden Wi-Fi state change must not redraw the reading page.

## System overview

```mermaid
flowchart TD
    INPUT[Physical controls / system events]
    EVENTS[Event queue]
    STATE[Application state]
    READER[Reader engine]
    UI[UI composition]
    PLAN[Render plan / dirty regions]
    REFRESH[Refresh manager]
    HW[Display driver / hardware]
    DATA[Persistent data]

    INPUT --> EVENTS
    EVENTS --> STATE
    STATE --> UI
    STATE --> READER
    READER --> UI
    UI --> PLAN
    PLAN --> REFRESH
    REFRESH --> HW
    STATE --> DATA
    READER --> DATA
```

## 1. Event model

ENKU firmware should react to discrete events instead of continuously repainting UI state.

Examples:

- ButtonPressed
- ButtonReleased / ButtonHeld
- PageNext
- PagePrevious
- ScreenOpened
- SettingChanged
- OrientationChanged
- BookOpened
- BookPositionChanged
- ImportProgressChanged
- ImportCompleted
- WiFiConnected
- WiFiDisconnected
- BatteryStateChanged
- SleepRequested
- WakeRequested

Events update application state first. Rendering is a consequence of state changes, not the primary control flow.

This is important for e-paper because it reduces unnecessary refreshes, ghosting and power use.

## 2. Application state

A single logical state model should own product-level state such as:

- current screen / overlay;
- current book;
- semantic reading position;
- current focus target;
- orientation;
- UI language;
- Library view mode;
- Library filter and sort;
- focused/visible Library item;
- global reading settings;
- per-book reading overrides;
- bookmarks;
- saved/trusted networks;
- Wi-Fi state;
- battery/power state;
- active import/transfer state.

Screens should not own long-lived product state that must survive navigation, orientation change, sleep or reboot.

## 3. Reader engine

The Reader Engine is responsible for turning structured book content into renderable reading pages.

A conceptual request from the UI looks like:

```text
layoutPage(
    book,
    semanticPosition,
    typography,
    viewport
)
```

The engine returns:

- renderable page content;
- semantic position represented by the page;
- previous semantic position;
- next semantic position;
- reading-progress information;
- optional structural context such as chapter/section.

The UI does not need to know how EPUB, FB2 or TXT content is internally parsed.

The format adapter and metadata normalization rules are defined in [Metadata & Parser Model](parser-model.md).

The text layout, pagination and rendering rules are defined in [Pagination & Rendering Model](pagination-model.md).

The first concrete bridge from an opened normalized document to Reader-level page results is defined in [Reader Engine MVP](reader-engine-mvp.md).

Runtime transitions for opening, reading, search, sleep/wake and recovery are defined in [Reader Runtime & State Machine](runtime-state-machine.md).

The initial source/module layout and framework-neutral interfaces are defined in [Firmware Project Structure](firmware-structure.md).

The hardware-grounded button mapping and logical input actions are defined in [Input & Physical Controls](input-model.md).

The separation between display sleep, system suspend and PMU power-off is defined in [Power, Sleep & Wake Model](power-model.md).

The canonical string-key, fallback and pluralization strategy is defined in [Localization Architecture](localization-model.md).

Structured errors, bounded logging and Recovery/Safe Mode are defined in [Errors, Logging & Diagnostics](diagnostics-model.md).

The staged startup sequence, boot-loop handling and context restore rules are defined in [Boot & Startup Architecture](boot-model.md).

### Reader v1 format scope

The first ENKU reader release targets three reflowable/text-oriented formats:

- **EPUB**
- **FB2**
- **TXT**

**PDF is explicitly deferred to a later revision.** It is not part of the Reader v1 scope because fixed-layout PDF rendering, zoom/pan navigation, rasterization and memory requirements would add substantial complexity and do not align well with the initial 3.97″ reading experience.

PDF support may be revisited after the core reflowable reader, storage model and rendering pipeline are stable.

## 4. Semantic reading position

ENKU must not use rendered page number as the authoritative reading position.

Rendered pages are unstable because changing any of the following can repaginate the book:

- font size;
- line spacing;
- margins;
- font metrics;
- portrait/landscape orientation;
- viewport size;
- parser/layout fixes.

The stored reading position should instead identify a stable logical point in the book.

The exact representation will be selected per format, but conceptually it should resemble:

```text
book_id
+ structural location (spine/chapter/section)
+ text/character offset or equivalent stable anchor
```

When layout changes, the Reader Engine repaginates around this anchor and restores the nearest valid logical position.

## 5. Render plan

UI composition produces a render plan rather than writing directly to the panel.

The render plan describes:

- what region changed;
- whether content is new or only state decoration changed;
- whether a full page changed;
- whether an overlay opened/closed;
- whether the update may safely wait;
- whether multiple dirty regions can be merged.

Examples:

- page turn → whole reading viewport dirty;
- focused row changed → old/new focus regions dirty;
- hidden Wi-Fi state changed → no visible dirty region;
- transfer progress changed → progress region dirty, throttled;
- orientation changed → full screen dirty.

## 6. Refresh Manager

The Refresh Manager owns e-paper update policy.

Responsibilities:

- choose full vs region/deferred/no-update behavior;
- coalesce multiple UI updates;
- throttle rapidly changing states;
- discard obsolete queued work;
- force broader/full refresh after measured ghosting thresholds;
- avoid refreshing invisible state;
- serialize display access;
- expose measured driver limitations to higher layers without leaking driver details into UI code.

The detailed render-plan, queueing, escalation and diagnostic rules are defined in [Refresh Manager & E-Paper Update Policy](refresh-model.md).

Exact hardware thresholds and waveform choices remain unfrozen until the real Waveshare panel is characterized.

## 7. Hardware layer

Reference platform:

- Waveshare ESP32-S3-ePaper-3.97;
- 800 × 480 e-paper panel;
- physical controls;
- microSD/local storage;
- Wi-Fi;
- Li-Po power system.

Responsibilities:

- display initialization and refresh;
- button/input events;
- storage access;
- battery/power state;
- Wi-Fi transport;
- wake/sleep primitives.

Hardware behavior remains provisional until tested on the real board.

## 8. Hardware abstraction

The rest of the application should not need to know raw GPIO numbers or panel-driver details.

Planned interfaces include:

- display surface / refresh scheduler;
- logical input events;
- storage filesystem access;
- power-state service;
- network service;
- clock/time service where needed.

This layer is also where board-revision differences should be isolated.

## 9. Persistent data

Book files and reader state are logically separate.

The detailed Library/storage model is defined in [Library & Storage Model](storage-model.md).

The in-memory book records, browse/search queries and Library service boundary are defined in [Library Data Model & Service Interface](library-model.md).

The physical persistence strategy is defined in [Persistence Backend](persistence-model.md): versioned CBOR records with generation-based recovery, separated by write frequency.

Core decisions:

- maintain a persistent Library index;
- never use filename alone as book identity;
- assign a stable internal `book_id` backed by a content-derived fingerprint;
- keep raw book files separate from metadata, progress, bookmarks and per-book settings;
- store progress/bookmarks as semantic positions rather than rendered page numbers;
- cache normalized cover assets;
- use transactional import and replacement;
- keep incomplete imports outside the valid Library.

Safe import/replace operations must never turn a previously valid Library item into a broken one.

## 10. Local web management

The local browser interface is a management companion, not the main reader UI.

Initial scope:

- upload one or many books;
- drag-and-drop;
- storage/free-space status;
- metadata correction;
- cover management;
- safe delete/replace;
- import status and errors;
- mark read/unread;
- reset progress;
- clear per-book overrides.

It should remain local and session-scoped by default. Reading must not require a cloud account or an active connection.

## 11. E-paper refresh model

The exact driver strategy will be chosen after hardware characterization.

Expected rules:

- redraw only changed regions where reliable;
- avoid animation-like update loops;
- throttle progress/status updates;
- use periodic full refresh when real ghosting measurements justify it;
- expose user-facing refresh settings only if they have a clear product meaning.

## 12. Open decisions

The following are intentionally not frozen yet:

- exact firmware framework;
- concrete parser libraries/stack;

- partial refresh thresholds;
- battery model and percentage calibration;
- hard power-off implementation;
- final enclosure geometry.

These decisions will be resolved from measurement and prototyping rather than guessed in advance.

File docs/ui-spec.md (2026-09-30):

# ENKU UI specification v1.0

This document is the canonical implementation baseline for the ENKU interface.

English (EN) is the source/reference language. All other languages are translations of the EN string set.

## 1. Interaction model

- ENKU is a non-touch interface.
- Navigation moves **focus**.
- Confirmation activates or changes the focused control.
- Back returns to the previous level or closes the current overlay/dialog.
- Focus, selected value, active tab and persistent state are different concepts and must never be represented by the same visual treatment.
- Returning from a child screen restores the parent's logical focus and scroll position.
- Orientation changes preserve logical focus and semantic content position, not raw pixel coordinates.

## 2. Core dimensions

Baseline values from the approved component boards:

- Primary button / input field height: **48 px**
- Corner radius: **4 px**
- Normal border: **1 px**
- Focus border: **2 px**
- Typical screen title: **20 px bold**
- Primary body text: **16 px**
- Supporting / metadata text: **12 px**
- Header back icon: **20 px**
- Header icon → title gap: **12 px**
- Row icon: **24 px**
- Dialog icon: **24 px**
- Dialog icon → text gap: **8 px**

These are design baselines, not immutable firmware constants. Any change must be validated in both 800×480 and 480×800 layouts.

## 3. Focus and selection states

### Focus
A focused row/control receives a **2 px outline**.

Focus means: this is the element that will respond to Confirm.

### Selected / applied value
A selected persistent value uses a check/radio/value indicator independent from focus.

A selected row can be unfocused.
A focused row can be unselected.

### Primary action in focus
A focused primary action uses black fill with white text.

### Active tab
The active tab uses black fill with white text.
If another tab has focus, that tab additionally receives the focus outline while the active tab remains visually active.

### Destructive and reset dialogs
Default focus is always the safe action:
- Cancel
- Continue
- Keep current

Never default focus to Delete / Replace / Reset / Power Off.

## 4. Headers

### Root header
Used for top-level sections such as Library.

Contains:
- section title;
- optional status bar above;
- optional trailing actions.

### Back header
Contains:
- back arrow;
- current screen title;
- optional trailing action/menu.

### Reading
Reading content is chrome-free by default.
Status/header controls appear only when the reading overlay/menu is invoked.

## 5. Lists and rows

- Entire row is focusable unless the row contains explicitly separate controls.
- Primary label may use up to **2 lines**.
- Supporting metadata uses **1 line** and ellipsis.
- Long content never reduces the font size to fit.
- Trailing icon/action is vertically centered against the whole row block.
- List state and current focus must remain distinguishable.
- Scroll restores the focused/visible item when returning or changing orientation.

## 6. Buttons

- Minimum baseline height: 48 px.
- Button text is optically centered.
- Standard horizontal screen/content inset: **24 px** on both sides.
- On single-column screens with one primary call-to-action, the primary CTA spans the **full content width between the 24 px insets** in both portrait and landscape.
- Examples: Continue, Finish setup, Connect, Save, Add books, Refresh, Done.
- The same full-width rule is used consistently across orientations; do not size a primary CTA to its label.
- One primary action per compact state/dialog where possible.
- Secondary actions use outline style.
- Multi-action dialogs, segmented controls, toolbars and genuine multi-column layouts follow their local grid instead of forcing each action full-width.

## 6.1 Icons

- ENKU uses the **approved Phosphor icon library** supplied in the original `icons(1).zip` asset set.
- Use the original SVG asset geometry directly. **Do not redraw, reinterpret, normalize or create replacement versions of existing icons.**
- Do **not** use Unicode characters, emoji, text glyphs or font symbols as production icon substitutes.
- Core icon size: **24 px**; header/back icon: **20 px**, unless a specific approved component defines otherwise.
- Scale the source SVG uniformly from its native `256 × 256` viewBox. Do not alter internal geometry to make icons appear artificially centered.
- Optical placement is handled by the surrounding component/layout, not by editing the source icon.
- Focus belongs to the control/container and never changes the underlying icon asset.
- If a required icon already exists in the approved Phosphor asset set, that exact file must be used.
- A new icon asset is added only when the approved set genuinely lacks the required concept; it must be reviewed before use.
- Existing approved/reference boards remain the visual source of truth for icon sizing and spacing.

## 7. Input fields and keyboard

- Input field height baseline: 48 px.
- Text-entry keyboard is a shared subsystem used by:
  - Wi-Fi password;
  - Library search;
  - in-book search;
  - future metadata editing where needed.
- Keyboard layout/input mode is independent from UI language.
- Initial supported text input modes: Latin, Cyrillic, numeric/symbol.
- Shift behavior:
  - one activation → next character uppercase;
  - second activation → Caps Lock;
  - third activation → lowercase.
- Password fields mask text by default and may expose an explicit Show password option.
- Credentials are persisted only after successful Wi-Fi connection.

## 8. Dialogs and overlays

- Modal/overlay height follows content.
- Background content remains visually present where practical, but does not receive focus.
- Back closes the overlay and restores parent focus.
- Dialog actions follow safe-default rules.
- Overlays must not silently change reading position.

## 9. Portrait / landscape rules

Same data model and same actions in both orientations.

Orientation changes layout, not functionality.

- Portrait generally uses one column.
- Landscape may use two columns where traversal is deterministic.
- Never hide important secondary information solely because orientation changes.
- Long lists remain scrollable.
- Current focus/selected item is preserved logically.

## 10. Long text and localization

English is canonical.

Initial translation set:
- EN
- RU
- PL
- DE
- FR
- ES
- IT

Rules:
- titles: up to two lines, then ellipsis;
- supporting metadata: one line, then ellipsis;
- do not shrink typography to fit translations;
- long SSIDs/book titles/chapter titles use the same truncation rules;
- every revised EN board must be stress-tested with long DE/FR/PL strings before being considered final.

## 11. Library

- Grid and List are both first-class views.
- Persist:
  - view mode;
  - filter;
  - sort;
  - focused/visible book.
- Search is global across title + author and is not constrained by the active Library filter.
- Empty Library, Empty Filter and No Search Results are distinct states.
- Book Details exposes the same semantic data in both orientations.

## 12. Reading

- Content-first reading view; chrome hidden by default.
- Five canonical presets:
  - Spacious
  - Comfortable
  - Standard
  - Compact
  - Dense
- Manual typography changes switch to **Custom**.
- Settings may be global or per-book.
- Typography/orientation changes preserve semantic text position before repagination.
- Contents and Bookmarks share one overlay.
- In-book search preserves the original reading position until the user opens a result.
- Search highlight must remain visible on monochrome/limited e-paper output.

## 13. Storage and import

- microSD/local files are part of MVP.
- Import validates before committing a Library record.
- Raw book file is logically separate from reading progress/bookmarks/per-book settings.
- Replacement is transactional.
- Incomplete imports use temporary files and are cleaned up on failure/cancel.
- No auto-format.
- No automatic deletion of books to make space.
- USB transfer is not committed until transport architecture is chosen.

## 14. Wi-Fi and local web management

Wi-Fi is optional for reading.

- Saved network: credentials are known.
- Trusted/preferred network: eligible for deterministic auto-connect priority.
- Avoid the ambiguous “Home network” concept.
- Local web management is session-scoped by default.
- Web UI scope includes:
  - multi-file upload / drag & drop;
  - book/file list;
  - safe delete and replace;
  - storage/free-space view;
  - import status/errors;
  - metadata inspection/correction;
  - cover preview/replacement/restoration;
  - mark read/unread;
  - reset progress;
  - clear per-book overrides.
- Full typography tuning stays on-device in the first version.

## 15. Sleep and power

- Sleep screens are static.
- No live clock, animations or periodic refresh.
- Book-cover sleep screen preserves source aspect ratio.
- Fall back to simple sleep screen when cover is missing/unreadable.
- Auto-sleep is suspended during imports/transfers/writes.
- Power-off semantics and wake behavior are not final until verified on real Waveshare hardware.
- Battery thresholds/percentage are not final until characterized with the actual LP505060 pack.

## 16. E-paper refresh principles

User-facing refresh options are not final until measured on the real panel.

General rules:
- avoid animation-style continuous updates;
- throttle transfer progress redraws;
- prefer partial refresh only where reliable;
- periodically use full refresh as required by real-panel ghosting measurements;
- never expose a “technical” setting that cannot be explained in user terms.

## 17. Canonical reference boards

System/reference material:
- `ENKU_ui_kit_core_v1`
- `ENKU_focus_states_v1`
- `ENKU_navigation_status_v2`
- `ENKU_portrait_orientation_v2`
- `ENKU_long_text_check_v1`

These are not production screens. They define reusable layout/interaction rules.

## 18. Design board format

- Canonical UI review boards are **PNG images**, matching the original RU design workflow.
- Each canonical board presents both **800 × 480 landscape** and **480 × 800 portrait** variants where applicable.
- SVG icon files in `design/icons/` remain the approved icon source/reference library.
- Screen behavior, dimensions, focus rules and implementation constraints live in this document and related docs; the PNG board is the visual reference.
- Generated EN SVG screen boards created during the remediation phase are considered **draft/intermediate artifacts**, not final canonical design boards.
- As each EN screen is visually finalized, replace its draft SVG reference with a PNG board and update the screen index / revision plan.
- Do not rely on GitHub SVG composition, external SVG references or hand-authored inline icon geometry for final review boards.

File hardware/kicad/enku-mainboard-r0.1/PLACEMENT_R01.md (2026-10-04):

# ENKU Mainboard R0.1 — placement baseline B

Status: **active R0.1 routing / native KiCad ERC+DRC in CI / power + EPD routing in progress / not fabrication-ready**

Board envelope remains 54 × 94 mm, portrait, four layers.

This pass moves the project beyond the empty board shell and fixes the first mechanically-sensitive component regions.

## Placement priorities

1. Keep the ESP32 antenna at the board edge with a full RF keepout.
2. Put the 24-pin e-paper FPC and its HV booster in the shortest practical cluster.
3. Keep the Pro frontlight connector beside the display interface, but electrically separated from the EPD HV switching loop.
4. Keep microSD card insertion accessible from the left enclosure edge.
5. Keep USB-C centered on the bottom edge.
6. Keep Dock pogo contacts on the rear/lower region.
7. Keep the right-side reading controls aligned with the enclosure thumb rail.
8. Preserve a central rear keepout for the optional Qi coil.
9. Do not route switching nodes through the Qi, RF, button or display-flex mechanical zones.

## First fixed placement group — display interface

### J_EPD
**Hirose FH34SRJ-24S-0.5SH(50)**

Reason:
- 24 positions;
- 0.5 mm pitch;
- dual top/bottom contact;
- removes FPC contact-side uncertainty from R0.1.

Placement:
- upper-right / top display-interface zone;
- horizontal insertion toward the display-flex path.

### L_EPD
**Laird TYS5040100M-10**
- 10 µH;
- 5 × 5 mm class.

Placement:
- immediately adjacent to Q_EPD and the charge-pump capacitors;
- keep the high-di/dt loop compact;
- do not place under display-flex bend radius.

### Q_EPD
**IRLML6346TRPBF**
- SOT-23.

Placement:
- adjacent to L_EPD / RESE resistor;
- short GDR trace;
- short source/sense path.

### D_EPD1..3
40 V / 1 A Schottky class.

Placement:
- inside the same HV island;
- minimize loop area;
- keep HV nodes away from ESP32 antenna and user-accessible edges.

## Pro frontlight group

### J_FL
**Hirose FH34SRJ-6S-0.5SH(50)**

Placed near J_EPD so the Pro panel's two flex tails can enter the board in the same mechanical region.

### FL remap
Six raw connector nets enter a small 0 Ω remap field before reaching:
- FL_LED_PLUS;
- FL_WARM_RETURN;
- FL_COOL_RETURN.

This field remains accessible enough for prototype rework.

### U_FL
**TPS923610DRLR**

Place near:
- 10 µH inductor;
- output capacitor;
- 15 Ω current-sense resistor;
- warm/cool selector FETs.

Do not put the frontlight switching loop inside the Qi-coil keepout.

## Lower-edge I/O

### J_USB
Bottom-center.

### J_SD
Lower-left with card insertion through the left enclosure edge.

### Dock pads
Rear/lower center, mechanically separated from USB-C.

## Main compute

ESP32-S3-WROOM-1-N16R8 stays along the left upper/middle side with its antenna toward the board edge.

No copper, planes, battery, flex cable or enclosure metal should violate the module antenna keepout.

## Controls

Right edge:
- PREV;
- NEXT;
- SELECT;
- BACK.

The current PCB coordinates are only electrical-placement targets. Exact switch body positions will be reconciled with the rocker/button mechanical CAD before footprint freeze.

## Power

BQ25185 / TPS2121 / TPS63802 should form a compact lower power island between:
- USB/Dock inputs;
- battery connector;
- system rail.

Keep the buck-boost switching loop away from:
- ESP32 antenna;
- EPD BUSY/SPI;
- ADC battery sense;
- IMU.

## Prototype measurement access

Do not bury:
- VBAT;
- VSYS;
- 3V3_SYS;
- VBUS_USB;
- VBUS_DOCK;
- EPD VGH/VGL/VSH/VSL;
- frontlight output/current sense.

First-board debugability has priority over shaving the last millimetre of PCB area.

## Current KiCad status

The PCB now carries the main R0.1 mechanical placement, not just the display island.

### Placement baseline B coordinates

| Ref / group | PCB target |
| --- | --- |
| U1 ESP32-S3-WROOM-1-N16R8 | x=32.75, y=45.0, rotated 90°, antenna keepout toward left edge |
| U_IMU BMI270 | x=28.0, y=80.0, outside the central Qi keepout |
| U_HALL DRV5032FBDBZR | x=71.0, y=44.5, above the button rail |
| J_EPD | x=58.0, y=28.0 |
| J_FL | x=67.0, y=34.0 |
| J_SD | x=28.7, y=103.2, lower-left edge |
| J_USB | x=47.0, y=110.0, bottom-center |
| J_DOCK | x=47.0, y=99.0, rear copper side |
| U_SRC / U_CHG / U_3V3 | x=43.5 / 48.5 / 54.0, y=91.0 |
| J_BAT | x=66.0, y=93.5 |
| SW_POWER | x=30.5, y=29.0 |
| PREV / NEXT / SELECT / BACK | x=71.2, y=53 / 61 / 69 / 77 |

The EPD HV and frontlight discretes are now also represented inside the upper display power island:
- D1/D2/D3;
- R_RESE;
- VGH/VGL capacitors;
- L_FL;
- C_FL_OUT;
- R_FL_SET;
- Q_FL_WARM / Q_FL_COOL.

The first collision review found and corrected:
- U1 edge overlap with D2/C2 in the EPD island;
- Hall sensor overlap with the frontlight cluster;
- L_EPD clearances around D1/D2.

### Routing state — 03 Oct 2026

The PCB is no longer a placement-only shell. The current `main` board has passed the native first-spin critical geometry gate: **ERC 0 errors / 0 warnings**, with no gated short, crossing, copper-clearance, hole-clearance or board-edge violations. The remaining routing baseline is **251 unconnected items**; schematic↔PCB parity and silkscreen/library warnings remain cleanup work rather than fabrication claims.

Completed or materially routed areas now include:
- USB-C VBUS entry and Dock input toward the TPS2121 source selector;
- a substantial part of the lower power island;
- EPD VSH2 path from the display connector into the local HV island;
- EPD VGH moved onto the existing In1.Cu via-to-via corridor to remove the VGH/VDD crossing without adding another dense HV through-via;
- controlled layer transitions already present in the active layout.

Still open before routing freeze:
- finish EPD GDR / RESE and remaining HV rails;
- complete frontlight switching/current-return routing;
- finish 3V3 distribution and remaining peripheral/control nets;
- review ground-return continuity after final zone refill;
- resolve every remaining native KiCad DRC item and every unrouted connection.

The routing source of truth is the `.kicad_pcb` file plus native KiCad CI. Historical prose below describes how the board reached this state and must not be interpreted as saying that routing has not started.

### Automatic placement gate

`check_pcb_placement.py` now verifies:
- 54 × 94 mm board outline;
- all critical R0.1 placement references;
- key mechanical regions;
- ESP32 orientation;
- right-side button rail;
- no component origins in the central Qi keepout;
- balanced KiCad PCB S-expression.

The GitHub hardware workflow runs this together with the schematic structural gate.

### Next gate

The active engineering gate is now **routing closure and manufacturing review**:

1. finish the EPD HV island and frontlight routing;
2. close lower power distribution and remaining control/peripheral nets;
3. refill copper zones and run native KiCad ERC/DRC;
4. reach zero unexplained DRC errors and zero unrouted connections;
5. audit footprint orientation, polarity and assembly access;
6. generate and visually review Gerber, NC drill, BOM and CPL/PnP outputs.

The board is therefore an **actively routed engineering PCB**, but it is not yet a fabrication release.

## TPS63802 power-island revision

R0.1 no longer uses TPS63031 as the intended population.

Current lower power island:
- U_3V3: TPS63802DLAR exact DLA0010A land pattern;
- L_3V3: Murata DFE201612E-R47M=P2, 0.47 µH, rotated to keep L1/L2 loop short;
- input: 10 µF + 100 nF local bypass;
- output: 2 × 22 µF;
- feedback: 511 kΩ / 91 kΩ on the quiet side of U_3V3;
- PG: 100 kΩ pull-up and diagnostic net.

The placement gate rejects reintroduction of TPS63031 or loss of the support network.

### TPS63802 routing note — 04 Oct 2026

The regulator enable escape now leaves the dense U4 power island on an internal copper layer before reaching the outer service rail. This deliberately avoids the B.Cu 3V3 power corridor and keeps the quiet feedback side free of a long diagnostic branch. The local input/output capacitor rails are being closed before the remaining system-level 3V3/VSYS distribution.

TP7 remains a bring-up requirement, but its final connection is taken from the service-side SYS_EN trunk rather than forcing a probe branch through the feedback/switching cluster.

## Verified core footprint pass

The first-spin core no longer uses placement-only footprints for:
- U_SRC — TPS2121 RUX0012A, 12 pads;
- U_CHG — BQ25185 DLH0010A, 10 pins + exposed pad 11;
- U_IMU — BMI270 Bosch LGA-14;
- U_FL — TPS923610 DRL0006A;
- J_EPD — FH34SRJ-24S-0.5SH(50), including S1/S2 retention tabs;
- J_FL — FH34SRJ-6S-0.5SH(50), including S1/S2 retention tabs.

Both Hirose retention tabs are grounded and represented in the schematic so a future schematic-to-PCB sync cannot silently remove their net assignment.

A project-local `ENKU.pretty` library plus `fp-lib-table` makes the verified footprints reproducible without depending on the user's globally installed KiCad library version.

Remaining mechanical footprint gates are intentionally separate:
- final side-button MPN/actuator geometry;
- final battery connector/polarity/NTC strategy;
- final dock pogo mating geometry.
These are enclosure-dependent and must be frozen together with the mechanical stack, not guessed in isolation.

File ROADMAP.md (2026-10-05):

# ENKU Roadmap

This roadmap tracks the path from the current product/UI definition to a reproducible, repairable reader release with staged public source/design releases.

ENKU is in active firmware implementation and custom-hardware development. The Waveshare ESP32-S3-ePaper-3.97 remains the reference bring-up platform, while the dedicated ENKU R0.1 mainboard is in late routing / pre-production verification. Hardware-dependent claims remain provisional until physically validated.

## 1. Product foundation

- [x] Define ENKU as a focused, repairable, local-first e-reader project
- [x] Select Waveshare ESP32-S3-ePaper-3.97 as the reference platform
- [x] Define portrait and landscape as first-class orientations
- [x] Keep 3.97″ as the R0.1 pocket-reader target; larger formats are a separate future branch, not a replacement
- [x] Define a non-touch, physical-control interaction model
- [x] Define English as the canonical UI/source language
- [x] Define first localization wave: EN/RU/PL/DE/FR/ES/IT
- [x] Select Noto Sans as the current reading typography target
- [x] Define five reading presets: Spacious, Comfortable, Standard, Compact, Dense
- [x] Define offline-first behavior and optional Wi-Fi management
- [x] Define the local browser-based library-management scope

## 2. UI / UX system

- [x] Audit the initial 58-screen RU design baseline
- [x] Document focus vs selected vs active behavior
- [x] Define core dimensions, spacing, headers, rows and buttons
- [x] Define e-paper-aware interaction principles
- [x] Define Library state persistence
- [x] Define Reading Menu, Quick Aa, typography and search behavior
- [x] Define Storage/Import behavior
- [x] Define Wi-Fi and local management behavior
- [x] Define Sleep and Power principles
- [x] Build reusable Figma foundations and shared components
- [ ] Finish canonical EN review boards
- [ ] Finish Storage/Import board revisions
- [ ] Finish Wi-Fi board revisions
- [ ] Stress-test revised EN boards with long PL/DE/FR strings
- [ ] Validate localization placeholders, plural variants and missing-key fallback
- [ ] Replace temporary EN SVG boards with approved PNG review boards
- [ ] Synchronize screen index and documentation with the approved Figma baseline

## 3. Hardware bring-up

- [ ] Receive and identify the exact production board revision
- [ ] Measure the board and display stack
- [x] Verify control mapping against current official Waveshare source
- [ ] Physically verify onboard controls and GPIO behavior on the received board
- [ ] Verify microSD behavior and usable filesystem options
- [ ] Bring up the e-paper panel from a minimal firmware project
- [ ] Measure full-refresh timing
- [ ] Test available partial-refresh behavior
- [ ] Characterize ghosting across realistic reader screens
- [ ] Measure region/full refresh escalation thresholds using Refresh Manager diagnostics
- [ ] Validate Noto Sans rendering and memory footprint
- [x] Define product-level power states: Active, DisplayIdle, Suspended, PoweredOff
- [ ] Measure active, panel-idle, candidate-suspend and powered-off current
- [ ] Verify battery charging behavior
- [ ] Select and validate the final battery pack
- [x] Verify current vendor PMU shutdown and panel-sleep behavior from official source
- [ ] Verify actual suspend/wake sources and hard power-off semantics on hardware
- [ ] Document the verified hardware baseline

## 4. Firmware foundation

- [x] Create the framework-neutral firmware project structure
- [ ] Add reproducible build instructions
- [x] Define initial core/service interface boundaries
- [ ] Implement hardware abstraction for display, input, storage and power
- [x] Define reader runtime/state-machine behavior
- [x] Define staged boot/startup and restore architecture
- [ ] Implement boot coordinator / stage state machine
- [ ] Instrument startup stage timings
- [x] Integrate PageNext/PagePrevious events with ReaderSession and AppState
- [x] Integrate OpenBook/Back/Finished transitions
- [x] Implement concrete TXT book-loader/document-provider service
- [ ] Wire book-loader completion directly into runtime event dispatch
- [ ] Implement application state model
- [x] Define persistence backend and crash-recovery model
- [ ] Implement CBOR persistence codec and generation recovery
- [ ] Implement persistent settings storage
- [ ] Implement reusable UI component layer
- [x] Define physical-to-logical input mapping and press semantics
- [x] Define ambidextrous control requirement: Portrait RH / Portrait LH / Landscape RH / Landscape LH with logical remapping
- [ ] Implement deterministic focus navigation
- [ ] Implement portrait/landscape layout switching
- [x] Define localization key/fallback/plural architecture
- [ ] Add canonical English string catalog
- [ ] Add PL/DE/FR/ES/IT/RU translation catalogs
- [ ] Implement generated runtime localization tables
- [x] Define Refresh Manager, coalescing and ghosting-measurement architecture
- [ ] Implement render-plan generation
- [ ] Implement bounded Refresh Manager queue/coalescing
- [ ] Implement e-paper redraw scheduling / refresh policy
- [x] Define structured error/logging/recovery architecture
- [ ] Implement bounded structured log ring
- [ ] Implement persistent critical-error/reboot summary
- [ ] Implement boot-loop detection and Recovery Mode
- [ ] Add diagnostic export/support bundle
- [ ] Add structured logging and debug diagnostics

## 5. Library and storage

- [x] Define the initial supported book format set: EPUB, FB2 and TXT; PDF deferred
- [ ] Add Markdown as a lightweight supported reading format
- [x] Define Library/storage data model and transactional import semantics
- [x] Define Library records, browse/search query model and service boundary
- [ ] Implement LibraryService and index loading
- [ ] Implement library indexing
- [x] Define metadata normalization and fallback rules
- [x] Define shared parser abstraction for EPUB, FB2 and TXT
- [ ] Implement metadata extraction
- [ ] Implement cover extraction and fallback handling
- [x] Define bounded Library query paging and focus-by-book-id behavior
- [ ] Implement Grid view
- [ ] Implement List view
- [ ] Implement filter and sort
- [ ] Implement title/author search
- [ ] Persist Library focus, view, filter and sort state
- [ ] Implement safe delete
- [x] Define transactional replace behavior
- [ ] Implement transactional replace
- [x] Define duplicate detection stronger than filename matching
- [ ] Implement duplicate detection
- [x] Define temporary-file cleanup/recovery behavior
- [ ] Implement temporary-file cleanup after failed imports

## 6. Reader engine

- [x] Define format-independent normalized document model
- [ ] Implement EPUB parser
- [ ] Implement FB2 parser
- [x] Add framework-neutral TXT parser MVP (UTF-8 validation, normalization, paragraph blocks)
- [ ] Integrate TXT parser with storage/Reader Engine and expand encoding support
- [x] Define semantic reading-position representation
- [x] Define pagination, wrapping and rendering model
- [x] Add first host-testable forward text-pagination MVP
- [ ] Add real font metrics and production text shaping/measurement
- [ ] Implement paragraph spacing, block styles and deterministic previous-page reconstruction
- [x] Implement first DocumentReaderEngine over TextPaginator
- [x] Add ReaderSession page history/cache and deterministic Previous
- [ ] Add bounded long-session checkpoint/history compaction
- [ ] Implement text layout and pagination
- [x] Define portrait/landscape repagination behavior
- [ ] Implement portrait/landscape repagination while preserving position
- [x] Define debounced per-book progress persistence layout
- [ ] Implement reading progress persistence
- [ ] Implement five typography presets
- [ ] Implement Custom typography
- [ ] Implement global and per-book settings
- [ ] Implement bookmarks
- [ ] Implement table of contents
- [ ] Implement in-book search
- [ ] Implement search match navigation/highlighting
- [ ] Implement finished-book state
- [x] Define sleep/wake and recovery state behavior
- [ ] Restore exact logical reading position after reboot/sleep
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

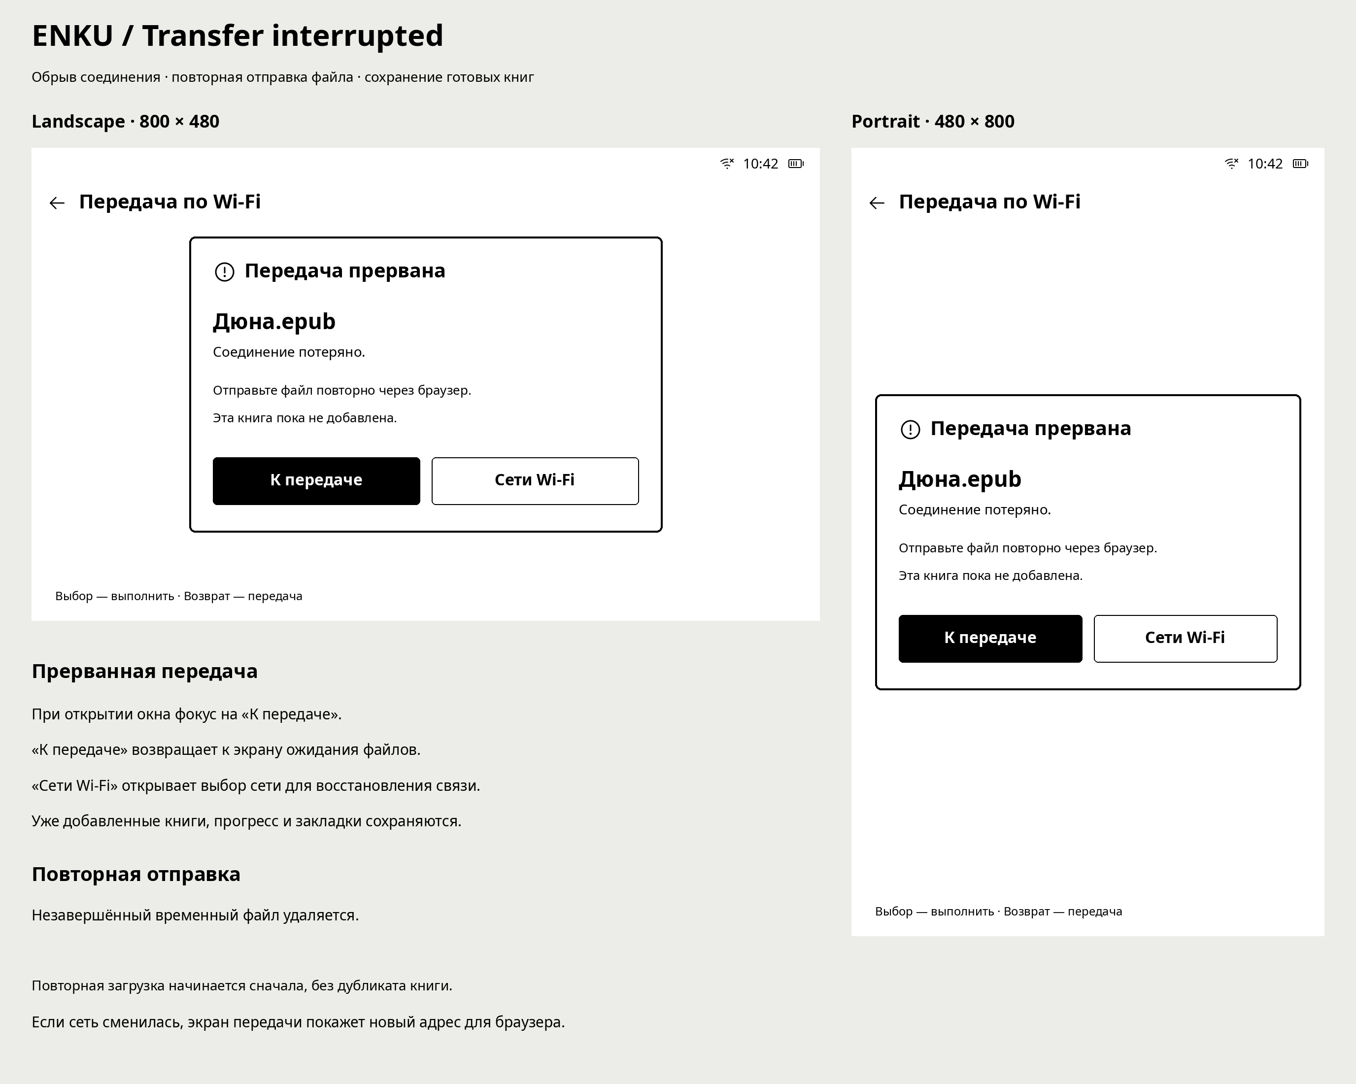
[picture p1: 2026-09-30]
design/screens/ru/ENKU_transfer_interrupted_v1.png

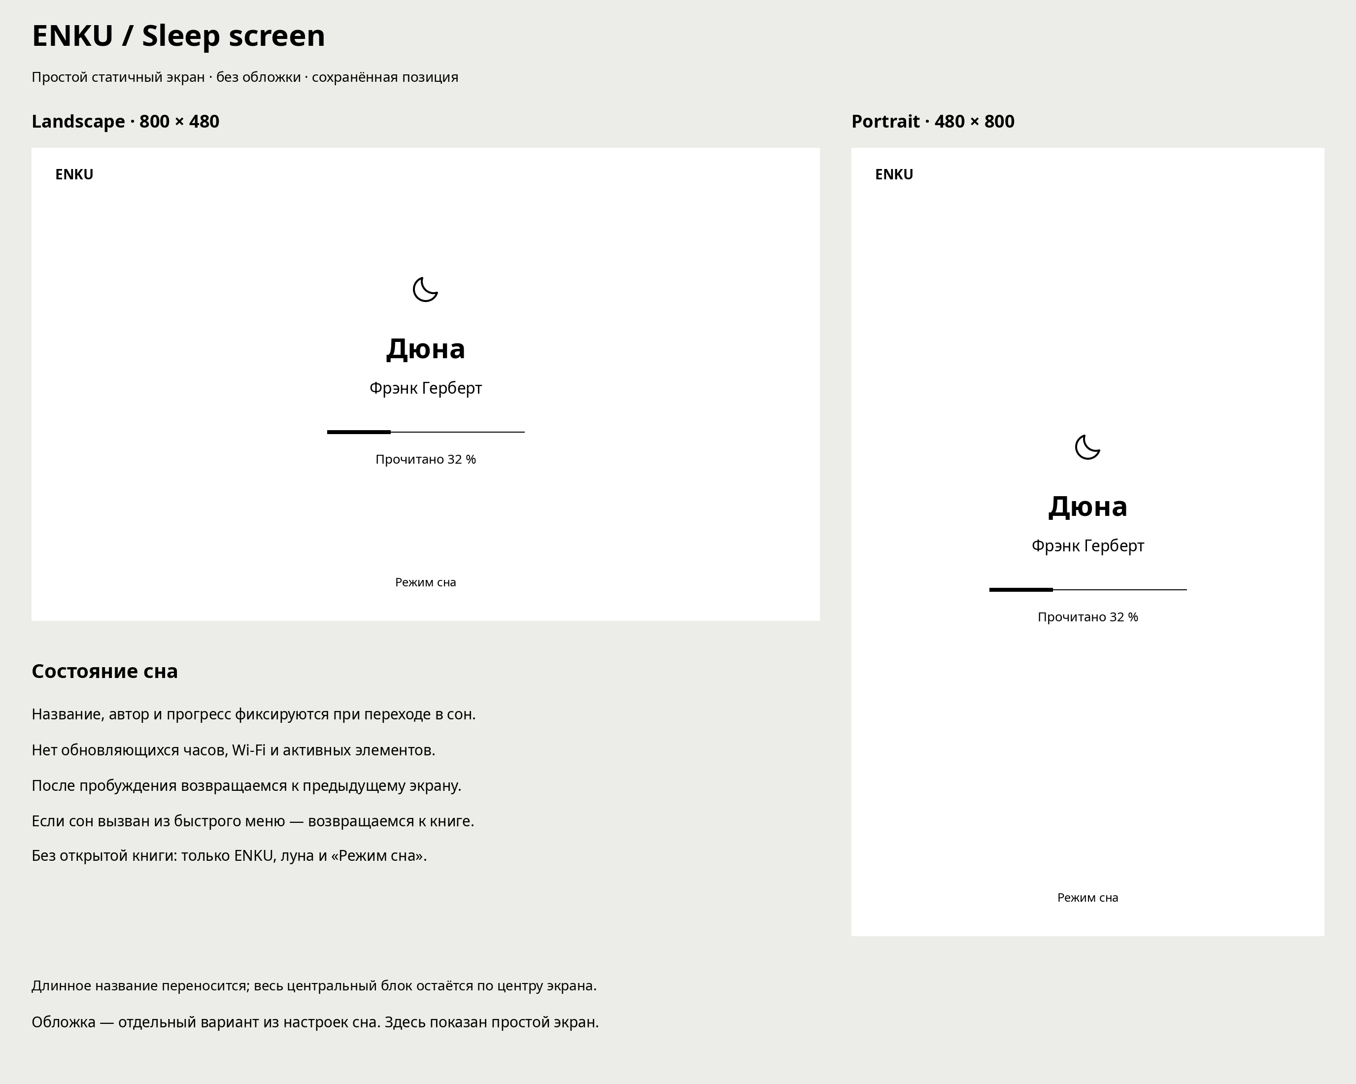
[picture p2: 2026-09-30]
design/screens/ru/ENKU_sleep_screen_v1.png

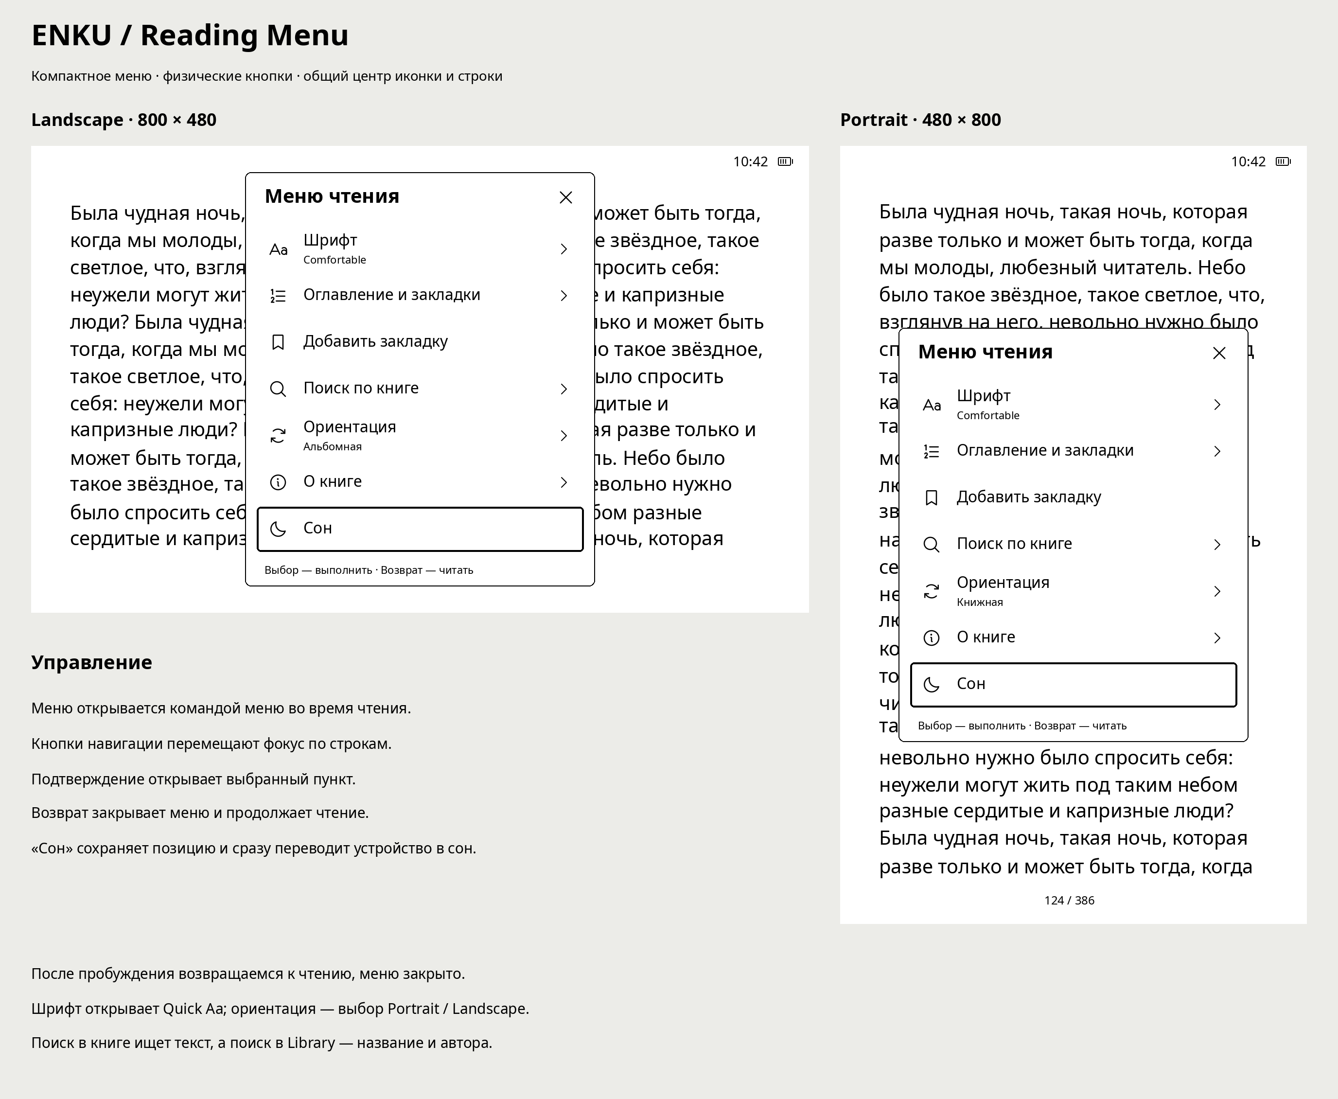
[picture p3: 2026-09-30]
design/screens/ru/ENKU_reading_menu_v2.png

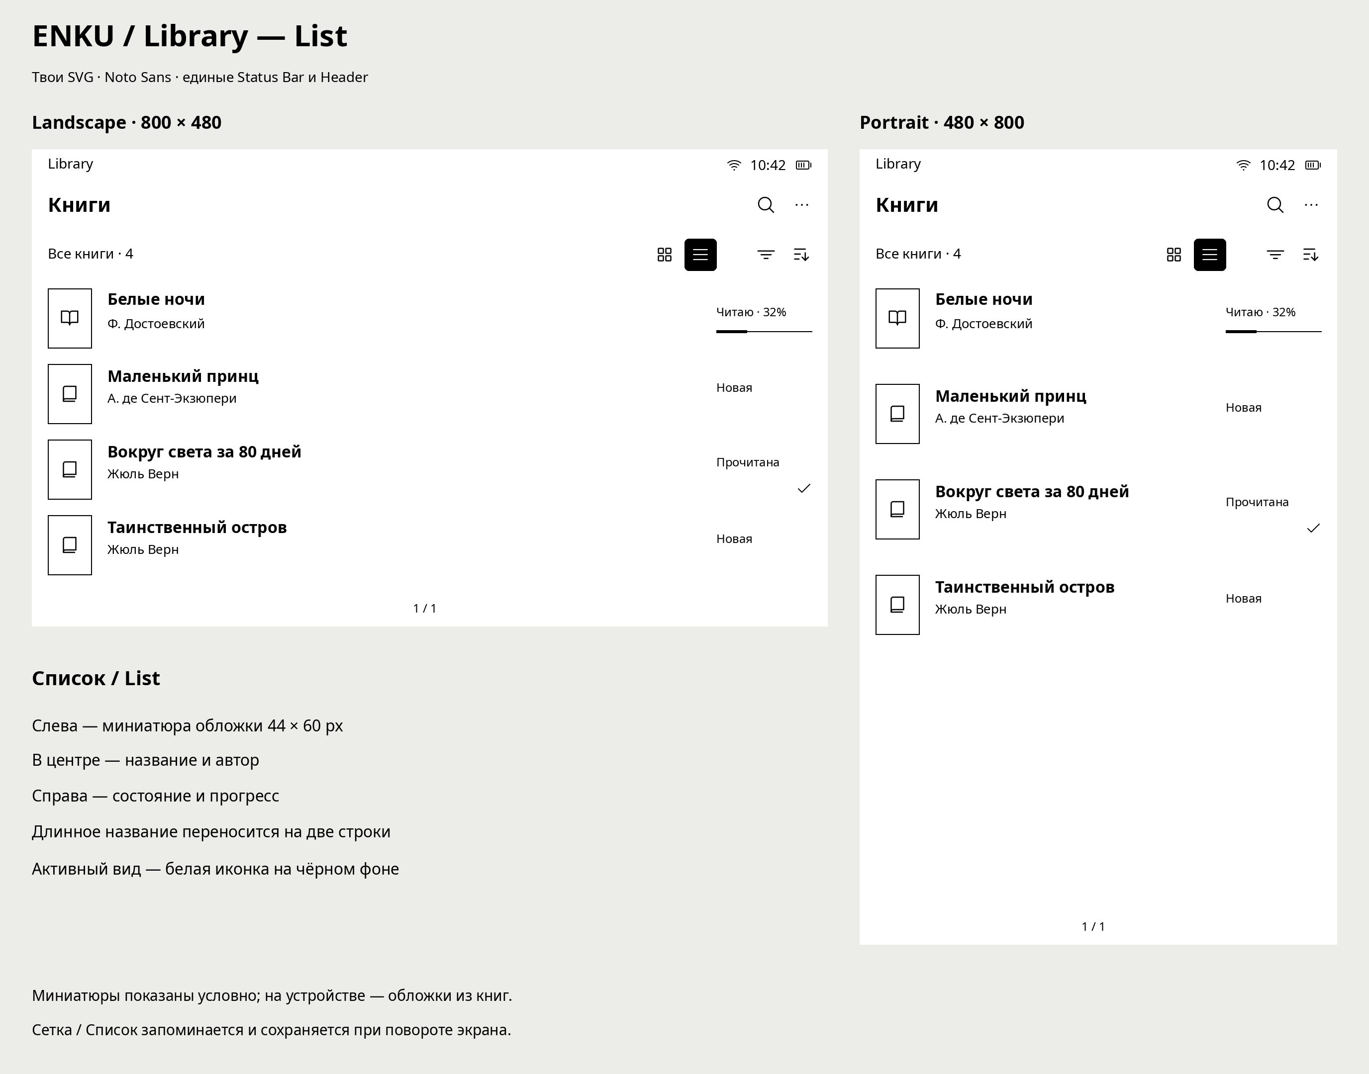
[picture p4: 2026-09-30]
design/screens/ru/ENKU_library_list_v1.png

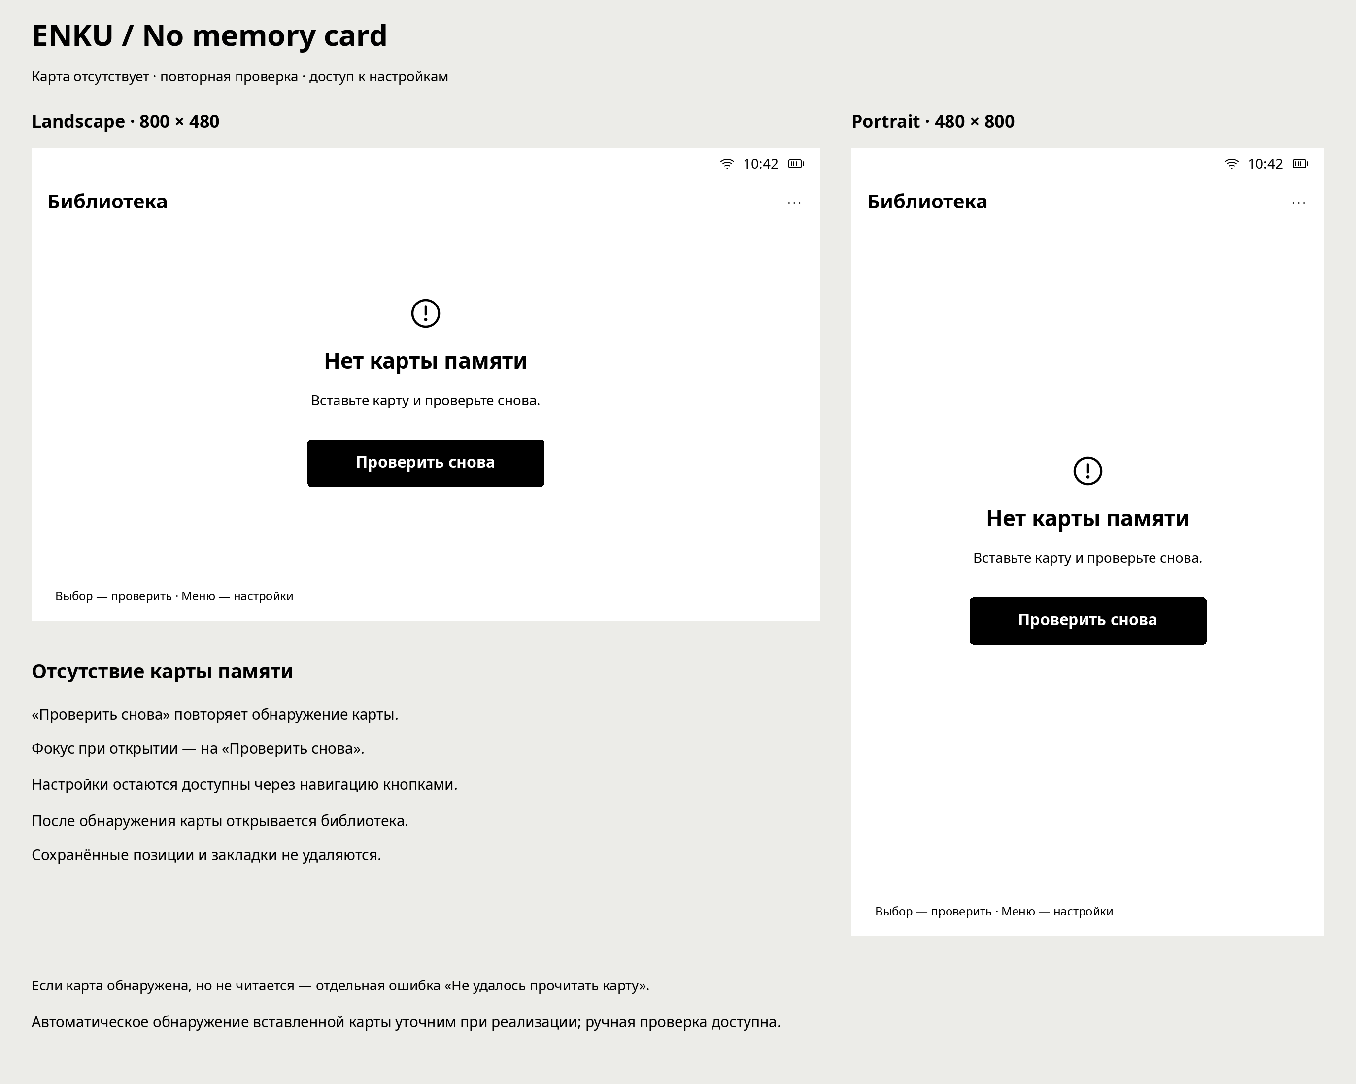
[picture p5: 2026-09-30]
design/screens/ru/ENKU_no_memory_card_v1.png

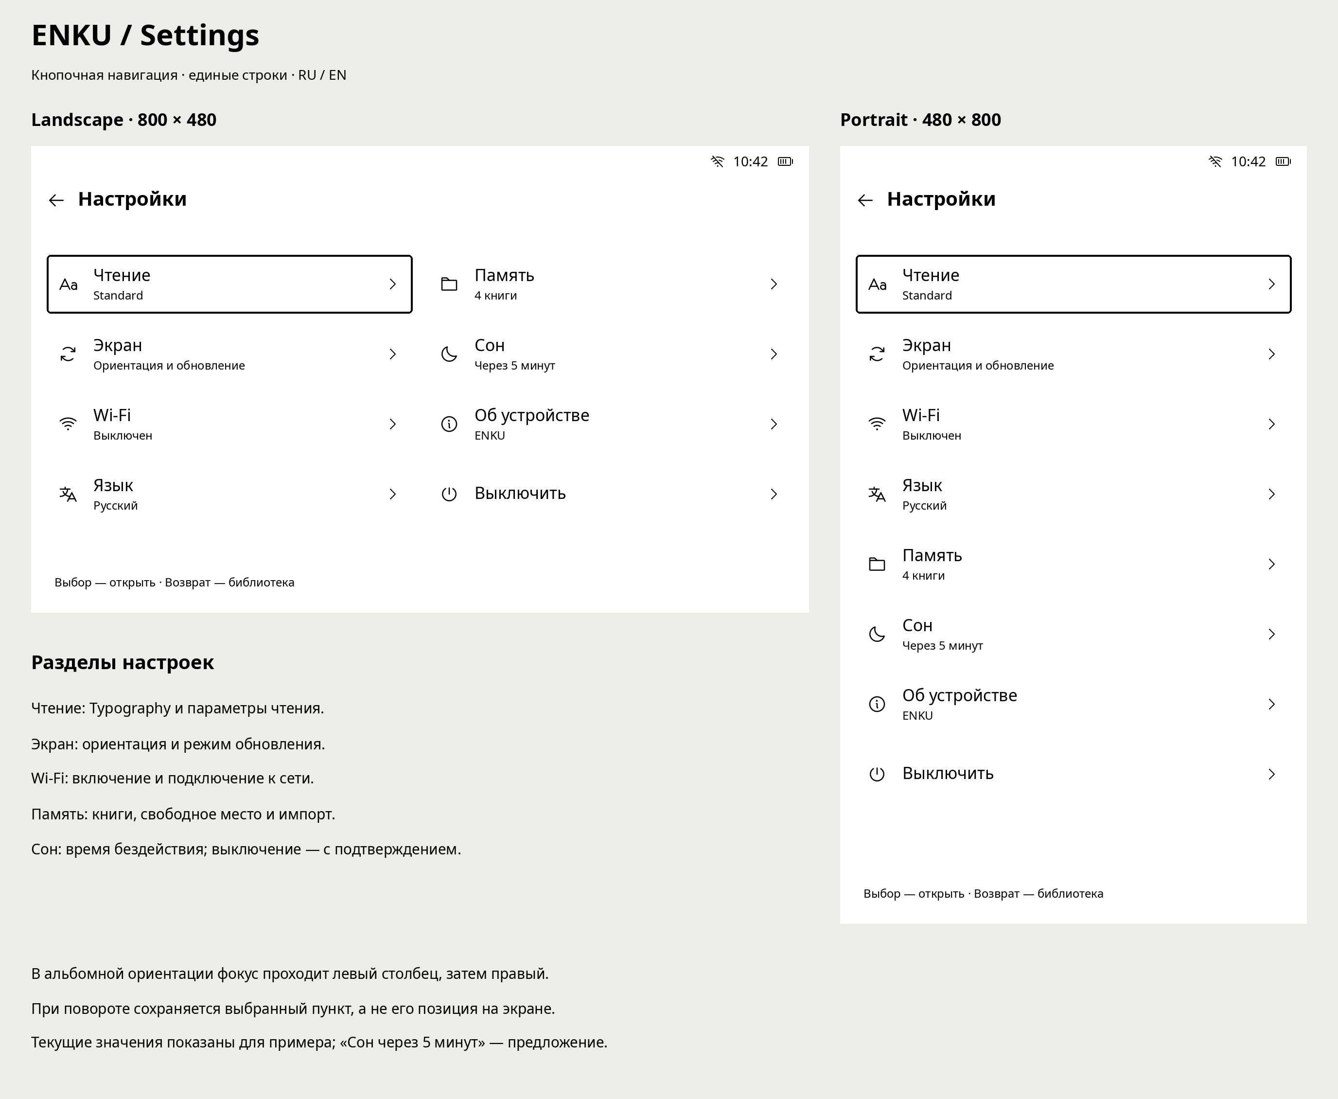
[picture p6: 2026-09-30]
design/screens/ru/ENKU_settings_v1.png

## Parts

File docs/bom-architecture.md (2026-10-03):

# ENKU multi-variant BOM architecture

Status: **pre-schematic cost architecture**

This document defines what should be shared across ENKU variants before individual manufacturer part numbers are frozen.

## Design objective

Use one core mainboard wherever practical.

Different products should be created mainly by:
- display choice;
- component population / DNP;
- enclosure;
- cover;
- wireless coil;
- frontlight optical stack.

Avoid maintaining independent Base and Pro compute boards unless panel integration proves it unavoidable.

## Shared core — all reader variants

Target blocks:

- ESP32-S3-WROOM-1-N16R8;
- native USB-C;
- protected charge / system-power path;
- 1S Li-Po connector;
- hard hardware power-off control;
- microSD connector accessible from enclosure edge;
- e-paper logic interface;
- EPD HV/analog power section based on validated Good Display reference;
- Previous / Next rocker electrical switches;
- Select / Menu;
- Back;
- BMI270;
- low-power Hall sensor footprint;
- battery measurement;
- Dock pogo pads;
- protected dock-input OR / power mux;
- DOCK_DETECT / accessory ID;
- debug / factory pads;
- frontlight control / connector footprint reserved where routing allows;
- Qi interface / keepout reserved where it does not compromise RF, EPD or mechanical design.

## Variant population matrix

| Block | Electronics | Base | Cover | Pro | Pro Wireless |
| --- | --- | --- | --- | --- | --- |
| ESP32-S3 core | yes | yes | yes | yes | yes |
| microSD | yes | yes | yes | yes | yes |
| BMI270 | yes | yes | yes | yes | yes |
| USB-C | yes | yes | yes | yes | yes |
| Dock pogo | yes | yes | yes | yes | yes |
| Dock detect / mux | yes | yes | yes | yes | yes |
| Hall sensor | optional | optional / preferred | yes | yes | yes |
| Frontlight driver | DNP | DNP | DNP | yes | yes |
| Frontlight connector | reserve | reserve | reserve | yes | yes |
| Qi receiver / matching | DNP | DNP | DNP | DNP | yes |
| Qi coil | no | no | no | no | yes |
| Magnetic cover | no | no | yes | optional | optional / yes |
| Display | Base | Base | Base | Pro FL | Pro FL |

## Display mapping

### Base family

GDEY0397T81P

Used by:
- Electronics Kit;
- Base;
- Cover.

### Pro family

GDEY0426T82-FL01C

Used by:
- Pro;
- Pro Wireless.

The custom board should aim to support both SSD1677-based panels through the same logical display interface, but final FPC pinout and HV requirements must be verified before this is treated as electrically interchangeable.

## Cost envelopes

Landed BOM ceilings:

- Electronics Kit: PLN 155
- Base: PLN 180
- Cover: PLN 200
- Pro: PLN 230
- Pro Wireless: PLN 260
- Dock: PLN 40

These include the intent to leave room for:
- assembly losses / rework;
- packaging-level small parts;
- small-batch sourcing inefficiency.

They are not final accounting COGS.

## Cost priority by block

### Protect aggressively

These blocks must be cost-optimized early:
- display;
- ESP32 module;
- PCB + assembly;
- battery;
- microSD connector;
- EPD HV section;
- enclosure.

### Spend where UX justifies it

Do not cost-cut below acceptable user experience on:
- page switches / rocker tactile quality;
- USB-C mechanical robustness;
- power-path safety;
- battery protection;
- frontlight optical quality;
- Dock contact reliability.

### Keep optional

Cost-heavy or mechanically risky features:
- frontlight;
- Qi;
- premium cover;
- optional encoder footprint;
- higher-end battery gauge.

## BOM decision gates before final routing

### Gate 1 — Displays

Need:
- Good Display pinout/reference circuit;
- quantity pricing 10 / 25 / 50 / 100;
- long-term availability;
- mechanical drawing;
- frontlight electrical requirements for Pro.

### Gate 2 — Power

Resolve:
- system regulator current margin;
- charger versus charger + true power-path;
- USB and Dock simultaneous-input behavior;
- hard-OFF charging;
- Qi interaction with wired charger.

### Gate 3 — EPD HV

No fabrication until:
- official reference circuit is integrated;
- component ratings and land patterns are verified.

### Gate 4 — Input mechanics

Choose actual tact switches after:
- actuation force comparison;
- noise comparison;
- enclosure rocker geometry;
- cycle life and sourcing review.

### Gate 5 — microSD

Choose connector only after:
- side-entry geometry is frozen;
- push-push versus push-pull cost is compared;
- card accessibility is verified with enclosure wall thickness.

### Gate 6 — Dock

Choose:
- pogo pitch/contact geometry;
- alignment strategy;
- input OR/mux IC;
- accessory ID scheme.

### Gate 7 — Pro frontlight

Verify:
- frontlight driver topology;
- warm/cool channel current;
- PWM behavior;
- minimum usable night brightness;
- thermal rise.

### Gate 8 — Qi

Only for Pro Wireless:
- receiver IC / module decision;
- coil size;
- ferrite;
- keepout;
- thermal test;
- Qi interoperability/certification strategy.

## BOM freeze rule

The schematic may progress before exact supplier pricing is final.

The PCB **must not** be declared production-ready until:
- each MUST component has an exact MPN;
- each variant has a complete populated/DNP BOM;
- supplier or assembly pricing demonstrates that the cost ceilings are realistic;
- no BLOCKER item remains in the EPD/power path.

## R0.1 power candidate

The first power-path candidate is now **TI BQ25185**.

Reason:
- real power-path management is now required by USB-C + Dock + hard-OFF charging;
- low battery-only quiescent current;
- up to 1 A charging;
- system-load support while charging;
- wider input tolerance than the earlier simple charger placeholder.

The earlier MCP73831 should no longer be treated as the preferred production architecture.

USB-C and Dock inputs will be combined through protected OR-ing / source selection before the charger. Pro Wireless should preferably use a Qi receiver that supplies the same common charger path rather than introducing an independent second battery charger.

Detailed rationale:
[Custom mainboard power R0.1](custom-mainboard-power-r01.md)

## Power quality / cost shortlist

Current R0.1 shortlist:

| Block | Candidate | Status |
| --- | --- | --- |
| Charger + power path | TI BQ25185 | Primary |
| USB / Dock input mux | TI TPS2121 | Quality baseline; compare against qualified discrete OR-ing |
| 3.3 V regulator | TI TPS63802DLAR | R0.1 first-spin baseline; 2 A-class headroom, true shutdown |
| 3.3 V evaluated alternative | TI TPS63031 / TPS63070 | Not default population; TPS63031 rejected for first-spin peak margin |
| Hall cover sensor | TI DRV5032 family | Keep where feature is populated |
| Qi receiver | TI BQ51013C | Pro Wireless only |

Cost policy:
- do not remove a safety/reliability part for a trivial PLN saving;
- prefer integrated solutions where they reduce failure modes, test burden or support cost;
- cost-down first through sourcing, DNP population, common PCB, qualified connector substitutions and volume purchasing;
- Base BOM must not carry Pro/Qi cost.

See:
- [Power architecture R0.1](custom-mainboard-power-r01.md)
- [Power cost pass R0.1](power-cost-pass-r01.md)
- [Open-source commercialization](open-source-commercialization.md)

## Schematic-level power baseline

Current preferred R0.1 implementation:

- BQ25185 charger / PowerPath;
- initial 4.2 V / 500 mA input-limit configuration;
- initial 300 mA fast-charge target for prototype thermal validation;
- TPS2121 as the USB/Dock quality-baseline source mux;
- TPS63031 fixed 3.3 V buck-boost as the first system-regulator candidate;
- physical hard OFF drives the switched system rail off while leaving charging available;
- BQ51013C-family Qi receiver only for Pro Wireless;
- Pro frontlight prototype reserves two independent boost LED channels, with TPS61165 as the quality-baseline reference candidate.

Detailed implementation:
- [Power schematic R0.1](power-schematic-r01.md)
- [Pro frontlight R0.1](frontlight-r01.md)
- [Power cost pass](power-cost-pass-r01.md)

EPD-HV remains a BLOCKER until the official panel reference circuit is verified.

## EPD / pin-map baseline

New schematic inputs:
- [EPD integration R0.1](epd-integration-r01.md)
- [ESP32-S3 pin map R0.1](pin-map-r01.md)

Current direction:
- one shared SPI bus for EPD + microSD with separate chip selects;
- current 24-pin SSD1677 family pinout used as the schematic baseline;
- current Good Display panel PDFs still must be checked directly before connector orientation / HV values are frozen;
- GPIO35–37 are reserved for the N16R8 memory topology;
- native USB remains on GPIO19/20;
- four direct page/navigation buttons remain separate GPIOs.

## Sponsored prototype vs production COGS

PCBWay is the preferred R0.1 fabrication / assembly path.

If prototype sponsorship is approved, maintain two independent cost columns:

1. **prototype cash cost** — actual project spend after sponsorship credit;
2. **normalized unsponsored COGS** — what the same hardware would cost without sponsorship.

Only normalized unsponsored COGS may be used for:
- Kickstarter margin;
- website kit pricing;
- BOM ceiling decisions;
- Base / Pro feature allocation.

Sponsored fabrication is an engineering accelerator, not a permanent unit-cost assumption.

Manufacturing plan:
[PCBWay prototype plan](pcbway-prototype-plan.md)

## Schematic capture baseline

The R0.1 schematic should now be captured from the named-net/block specification rather than directly from the early layout WIP:

[Schematic net/block baseline R0.1](schematic-netlist-r01.md)

Current display mechanical/electrical freeze state:
[Display freeze matrix R0.1](display-freeze-r01.md)

## EPD-HV sourcing baseline

The R0.1 SSD1677 reference circuit now has a concrete sourcing baseline:

- Q1: Vishay SI1308EDL-T1-GE3 preferred for prototype;
- D1-D3: MBR0530;
- R_RESE: 2.2 Ω / 1% / 0805;
- L1: 47 µH, exact production MPN still open;
- HV capacitors: 4.7 µF / 25 V / 0805 X5R/X7R and 1 µF / 25 V X7R according to the SSD1677 reference design.

Cost-down alternatives may only replace these after the first real EPD rail measurements.

See:
[EPD-HV components R0.1](epd-hv-components-r01.md)

## Pro frontlight production direction

The Pro frontlight architecture now prefers **one TPS923610 synchronous boost LED driver** with warm/cool return selection rather than two independent boost drivers.

Reason:
- substantially lower component/assembly count;
- active TI part;
- 24.5 V output headroom for the <=15 V Good Display strings;
- 200 mV current regulation;
- analog PWM dimming down to 0.1%;
- only a few PLN of IC cost.

The exact 6-pin frontlight mapping remains blocked on the current Good Display FL0426-S01C drawing.

See:
[Pro frontlight R0.1](frontlight-r01.md)

## Pro frontlight component baseline

R0.1 prototype parts now have a concrete baseline:
- TPS923610DRLR boost driver;
- 10 µH boost inductor, TDK VLS252012HBX-100M-1 as prototype candidate;
- 15 Ω / 1% current-set resistor (~13.3 mA nominal);
- BSS138-family low-side warm/cool selectors;
- 4.7 µF / 50 V output capacitor;
- 6-pin / 0.5 mm FPC connector class.

The exact frontlight connector pin map remains blocked on direct verification of the current Good Display FL0426-S01C drawing.

See:
[Frontlight components R0.1](frontlight-components-r01.md)

## R0.1 blocker-closure parts

The PCB-stage baseline now includes:
- EPD inductor: Laird TYS5040470M-10, 47 µH, 1 A rated / 1.1 A Isat;
- EPD boost switch: IRLML6346TRPBF preferred for prototype;
- EPD rectifiers: 40 V / 1 A Schottky class;
- EPD HV capacitors: 50 V class for R0.1 prototype margin;
- EPD connector: Hirose FH34SRJ-24S-0.5SH(50);
- Pro frontlight connector: Hirose FH34SRJ-6S-0.5SH(50) with a temporary remap matrix.

These choices prioritize first-board debugability and margin; production cost-down comes only after measured rail validation.

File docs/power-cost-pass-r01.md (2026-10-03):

# ENKU R0.1 power cost / quality pass

Status: **component shortlist / October 2026**

Goal: choose power components using two simultaneous filters:

1. technical quality and safety;
2. realistic small-batch cost / future margin.

Prices below are snapshot distributor references, not production quotations.

## Decision summary

### Charger / power-path: TI BQ25185 — KEEP as primary candidate

Current LCSC snapshot:
- 1+: ~USD 1.75
- 10+: ~USD 1.48
- 30+: ~USD 1.34
- 100+: ~USD 1.17

At ~3.90 PLN/USD, the IC itself is roughly:
- ~5.8 PLN at 10 units;
- ~5.2 PLN around 30 units;
- ~4.6 PLN at 100 units.

Why keep it:
- up to 1 A charging;
- true power-path;
- 4 µA battery-only quiescent current;
- battery temperature support;
- 3–18 V input.

Source:
https://www.lcsc.com/pl/product-detail/battery-management_texas-instruments-bq25185dlhr_C19725033.html

Conclusion:
The cost premium over MCP73831 is justified by eliminating a fundamental architectural weakness. Do not cost-cut back to MCP73831 for production.

### USB / Dock input selector: TPS2121 — technically excellent, cost acceptable but optional

Current LCSC snapshot:
- 10+: ~USD 0.92
- 30+: ~USD 0.79
- 100+: ~USD 0.70

Approx:
- ~3.6 PLN at 10 units;
- ~3.1 PLN around 30 units;
- ~2.7 PLN at 100 units.

Capabilities:
- dual input;
- automatic priority/source switching;
- reverse-current blocking;
- integrated FETs;
- 56 mΩ typical RDS(on);
- current limiting.

Source:
https://www.lcsc.com/product-detail/Battery-Management-ICs_Texas-Instruments-TPS2121RUXR_C485916.html

Decision:
Keep TPS2121 as the **quality baseline** for prototypes and early kits.

Before production freeze, compare it against a discrete MOSFET / ideal-diode design. Replace it only if:
- saving is meaningful across the whole board;
- reverse-current behavior stays safe;
- simultaneous USB + Dock use remains benign;
- assembly/test complexity does not erase the saving.

A ~3 PLN IC is not worth removing if the alternative adds field-failure risk.

### 3.3 V regulator: TPS63802 — SELECT for first spin

**TPS63802DLAR** replaces TPS63031 as the R0.1 baseline.

Reason:
- ENKU's realistic peak case can overlap ESP32-S3 Wi-Fi TX, microSD write and e-paper activity;
- TPS63031's boost-mode output margin is too close to that load envelope for a first-spin board;
- avoiding brownout redesign is worth more than the small BOM delta.

R0.1 support network:
- Murata DFE201612E-R47M=P2, 0.47 µH;
- 10 µF input + 100 nF local bypass;
- 2 × 22 µF output;
- 511 kΩ / 91 kΩ feedback;
- 100 kΩ PG pull-up.

TPS63031 remains documented as an evaluated candidate, not an approved production substitution.

TPS63070 remains only a secondary architectural alternative if TPS63802 sourcing changes; it is not the default R0.1 population.

### Hall sensor: DRV5032 — KEEP

Low-power versions cost approximately:
- ~USD 0.14–0.22 around 50 units depending exact variant.

Source examples:
https://www.lcsc.com/pl/product-detail/Hall-Switches_Texas-Instruments-DRV5032ZEDBZR_C266118.html
https://www.lcsc.com/pl/product-detail/C140921.html

Conclusion:
At well below 1 PLN in volume, Hall wake/sleep is not worth deleting from Cover / Pro variants.

Base may retain DNP optionality if every fraction of cost matters.

### Qi receiver: BQ51013C — Pro Wireless only

Current Mouser snapshot:
- 10+: ~USD 2.49 / around EUR 2.14 in EU listing;
- 25+: ~USD 2.28 / around EUR 1.96;
- 100+: ~USD 2.05 / around EUR 1.76.

Capabilities:
- Qi / WPC receiver;
- 5 V output;
- up to 5 W class;
- up to 1.5 A output-device rating.

Sources:
https://www.mouser.com/ProductDetail/Texas-Instruments/BQ51013CRHLR
https://www.mouser.it/c/semiconductors/power-management-ics/?series=BQ51013C

Decision:
The IC itself is not the expensive part.

The real Qi budget must include:
- coil;
- ferrite;
- tuning components;
- mechanical thickness;
- thermal validation;
- Qi interoperability / compliance work;
- yield / assembly risk.

Therefore Qi stays **Pro Wireless only**.

Do not advertise the Qi adder based solely on the receiver-IC cost.

## Recommended R0.1 power stack

```text
USB-C 5V -----\
               Dock 5V --------> TPS2121 or qualified OR-ing --> BQ25185 --> VSYS
                                                     |
Qi 5V ----------/  (Pro Wireless only)               +--> LiPo
                                                     |
                                                     +--> 3.3V buck-boost
                                                           |
                                                           +--> ESP32-S3
                                                           +--> microSD
                                                           +--> logic
```

Hard OFF disables the downstream system rails while preserving battery charging.

## Cost discipline

At 50–100 units, the premium power ICs under review are individually only a few PLN.

The correct question is not:
> "Can we remove this 3 PLN chip?"

It is:
> "Does removing it create more than 3 PLN of support, failure, assembly or redesign risk?"

For safety- or reliability-critical power blocks, ENKU should generally prefer the integrated, validated solution unless the discrete alternative saves a material percentage of total landed BOM.

## Working power-budget target per reader

Before final supplier quotes, reserve approximately:

- charger / power-path + passives: 8–12 PLN;
- external source mux / OR-ing: 3–5 PLN;
- 3.3 V buck-boost + inductor/passives: 5–8 PLN;
- USB protection / CC / filtering: 2–4 PLN;
- battery measurement / Hall / minor power control: 1–3 PLN;
- Qi receiver + coil/ferrite/tuning: additional 15–30 PLN for Pro Wireless pending actual sourcing.

Target total low-voltage power block:
- Base / Cover: ~19–32 PLN;
- Pro: ~20–34 PLN plus frontlight power;
- Pro Wireless: ~35–64 PLN including Qi allowance.

These are engineering budget envelopes, not quotes.

## Freeze criteria

Power BOM is not frozen until:
- actual battery is selected;
- charge current is thermally validated;
- TPS63802 3.3 V rail survives simultaneous Wi-Fi TX + SD write + EPD refresh with measured transient margin;
- USB + Dock simultaneous connection is tested;
- hard-OFF charging is verified;
- sleep leakage is measured;
- Pro frontlight current is measured;
- Qi coil/ferrite are tested in the real enclosure.

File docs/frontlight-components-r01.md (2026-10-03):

# ENKU Pro R0.1 — frontlight component freeze pass

Status: **prototype electrical values selected / remap network removes 6-pin mapping as a PCB-respin blocker**

## Goal

Turn the chosen single-boost frontlight architecture into a concrete prototype BOM without overfitting to an unverified third-party FPC mapping.

## Core driver

**U_FL — TI TPS923610DRLR**

Selected because it provides:
- synchronous boost;
- 2.5–5.5 V input;
- up to 24.5 V output;
- 200 mV feedback reference;
- analog current dimming through ADIM;
- very low shutdown current;
- compact SOT-563-6 package.

TI:
https://www.ti.com/product/TPS923610

## Boost inductor

Prototype baseline:

**L_FL — TDK VLS252012HBX-100M-1**
- 10 µH;
- 2.5 × 2.0 mm class;
- ~850 mA saturation/current class;
- 1.2 mm height.

Why:
- compact enough for the ENKU Pro stack;
- already used successfully in a separately reviewed open-hardware design around the same TPS923610 driver class;
- sufficient current margin for a ~13 mA, ~15 V LED load from a 1-cell system rail.

LCSC:
https://www.lcsc.com/product-detail/C88532.html

This is a prototype baseline, not a permanent single-source requirement.

## LED current set

**R_FL_SET — 15 Ω / 1% / 0603**

TPS923610 regulates near 200 mV at FB.

Nominal current:
```text
I_LED ≈ 0.2 V / 15 Ω ≈ 13.3 mA
```

This deliberately stays below Good Display's <=15 mA panel limit.

Preferred value class:
- 15 Ω;
- 1%;
- 0603;
- >=0.1 W.

The current limit must be rechecked on the actual panel lot.

## Warm / cool low-side selectors

Prototype baseline:
**Q_FL_WARM / Q_FL_COOL — BSS138-family N-MOSFET**

Requirements:
- >=30 V VDS preferred; 50 V class is comfortable;
- low gate threshold at 3.3 V;
- SOT-23;
- LED branch current is only ~13 mA, so conduction loss is negligible.

Reference quality candidate:
**onsemi BSS138LT1G**

Cost-down equivalents may be qualified later.

## Output capacitor

Prototype baseline:

**C_FL_OUT — 4.7 µF / 50 V / 0805 / X5R or X7R**

Reason:
- enough voltage margin for the 15 V-class frontlight rail;
- aligns with TI's 1–4.7 µF recommended output-capacitance window;
- preserves useful effective capacitance under DC bias better than a nominal 1 µF 0805.

Candidate class:
- Samsung CL21A475KBQNNNE
- or equivalent qualified 4.7 µF / 50 V 0805 X5R/X7R.

Do not substitute a lower-voltage MLCC.

## Input capacitor

Use a local input capacitor close to TPS923610:
- 4.7 µF;
- 10–16 V;
- X5R/X7R;
- plus 100 nF local ceramic.

Final source rail depends on the exact power-tree sheet.

## Brightness input

`FL_ADIM` / `FL_PWM` drives ADIM.

Firmware requirements:
- explicit startup pulse >40 µs before normal dimming;
- hold ADIM low long enough to enter shutdown;
- do not rely on tiny PWM pulses to wake the driver.

## Colour selection architecture

Two options remain footprint-compatible:

### Option A — two independent GPIO controls

Populate:
- Q_FL_WARM
- Q_FL_COOL

Firmware guarantees mutually exclusive selection.

Pros:
- easiest bring-up;
- supports both-off;
- easiest scope/debug.

### Option B — one GPIO + inverter

Add:
**74LVC1G04**-class inverter

Steady-state behavior makes exactly one branch active.

Pros:
- one GPIO;
- protects against steady-state double-on.

Cons:
- colour-transition overlap/both-off must still be scoped.

For R0.1, keep two control footprints and allow the inverter as DNP/alternate unless pin pressure makes it necessary.

## Frontlight connector

Connector class:
- 6-pin;
- 0.5 mm pitch;
- horizontal ZIF/FPC.

Candidate family:
**Hirose FH34SRJ-6S-0.5SH(50)**

Use the dual-contact **Hirose FH34SRJ-6S-0.5SH(50)** so FPC contact side is no longer a PCB-layout blocker.

R0.1 keeps the connector pins as raw nets:
- FL_RAW1
- FL_RAW2
- FL_RAW3
- FL_RAW4
- FL_RAW5
- FL_RAW6

A small 0 Ω remap network connects the raw pins to:
- FL_LED_PLUS
- FL_WARM_RETURN
- FL_COOL_RETURN
- unused/DNP positions.

This lets the first board adapt to the delivered panel pin order without a PCB respin. The production revision should collapse the remap network once the actual panel lot is verified.

## Protection

Recommended prototype protections:
- output TVS only if it does not add unnecessary capacitance/size and is justified by enclosure/accessibility;
- ESD protection on externally exposed FPC paths is optional because the panel FPC is internal;
- output over-voltage primarily relies on TPS923610 OVP.

Do not copy external-accessory protection from unrelated dev boards unless the same exposure exists in ENKU.

## Cost direction

The complete frontlight electronics should remain a small fraction of the Pro premium.

Expected high-level cost contributors:
- TPS923610: a few PLN;
- 10 µH inductor: sub-PLN to low-PLN;
- 2 × small MOSFETs: sub-PLN;
- passives/connector: a few PLN.

The **bonded Pro panel and enclosure mechanics**, not the driver circuit, should dominate the Pro BOM delta.

## Prototype freeze state

| Item | State |
| --- | --- |
| TPS923610 | selected |
| 10 µH inductor value | selected |
| VLS252012HBX-100M-1 | prototype candidate |
| 15 Ω current-set | selected |
| BSS138 branch FETs | prototype candidate |
| 4.7 µF / 50 V output cap | selected |
| 6-pin connector class | selected |
| exact FL pin map | first-article validation; remap network prevents PCB respin |
| continuous warm/cool blending | test item |
| exact production alternates | post-prototype cost-down |

## PCBWay gate

The common PCB may proceed with the dual-contact connector and remap network.

Before locking the **production** Pro population, verify:
- delivered panel pin mapping;
- LED polarity;
- current direction;
- warm/cool channel identity.

For R0.1, populate the remap resistors only after continuity-checking the first panel sample.

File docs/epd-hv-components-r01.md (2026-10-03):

# ENKU R0.1 — EPD-HV component freeze pass

Status: **reference design translated into current sourcing candidates / panel-specific confirmation still required**

## Reference topology

The SSD1677 application circuit explicitly specifies the following external parts:

- C0–C1: 1 µF, 0603, X5R/X7R, 6 V;
- C2–C7: 4.7 µF, 0805, X5R/X7R, 25 V;
- C8: 1 µF, 0805, X7R, 25 V;
- R1: 2.2 Ω, 0805, 1%;
- D1–D3: MBR0530;
- Q1: Si1304BDL;
- L1: 47 µH, CDRH2D18/LDNP-470NC;
- U1: 24-pin 0.5 mm ZIF socket.

The SSD1677 datasheet notes that component values may need adjustment for panel loading.

Reference:
https://files.waveshare.com/upload/2/2a/SSD1677_1.0.pdf

## Production-minded component decisions

### Q1 — replace obsolete Si1304BDL reference with IRLML6346TRPBF

The original Vishay Si1304BDL reference part is obsolete.

Preferred R0.1 quality-baseline replacement:

**Infineon IRLML6346TRPBF**
- 30 V logic-level N-channel MOSFET;
- SOT-23;
- ample prototype current margin;
- broad sourcing and easier first-board probing/rework.

This is also listed as a direct/similar substitute for the obsolete Si1304BDL by distributors.

Why this is preferable to a no-name Si1304 clone:
- exact manufacturer datasheet;
- active sourcing;
- very low RDS(on) compared with the old reference requirement;
- same compact package class;
- small absolute BOM impact.

Current sourcing example:
https://www.lcsc.com/product-detail/C67276.html

Cost-down fallback:
- qualify a lower-cost 30 V logic-level MOSFET only after EPD rail testing;
- do not substitute by footprint/name alone.

### D1–D3 — MBR0530

Keep the SSD1677 reference diode type.

Preferred sourcing baseline:

**YANGJIE MBR0530**
- 30 V;
- 500 mA;
- SOD-123.

Current source:
https://www.lcsc.com/product-detail/schottky-diodes_yangzhou-yangjie-elec-tech-mbr0530_C699108.html

Cost-down alternate:
**CBI MBR0530**
- same nominal 30 V / 500 mA class;
- materially cheaper in volume.

Current source:
https://www.lcsc.com/pl/product-detail/C21714234.html

Rule:
the three EPD-HV diodes must remain an approved common part within one build. Do not mix vendors casually during prototype characterization.

### L1 — 47 µH

R0.1 exact prototype choice:

**Laird TYS5040470M-10**
- 47 µH;
- 1 A rated current;
- 1.1 A saturation current;
- 272 mΩ max DCR;
- 5.0 × 5.0 mm class;
- 4.2 mm max height.

Why:
- significantly more current margin than the original compact SSD1677 reference inductor;
- still fits the current EPD-HV placement zone;
- low enough DCR for a conservative first prototype.

The manufacturer land pattern must be used directly in KiCad.

Production cost-down may qualify a smaller/lower-cost 47 µH part only after VGH/VGL waveform and thermal measurements.

### R_RESE — 2.2 Ω, 1%, 0805

Freeze electrical specification:

- 2.2 Ω;
- 1%;
- 0805;
- ≥0.125 W preferred for margin.

This value comes directly from the SSD1677 reference application circuit.

Manufacturer may remain a qualified passive alternate rather than single-source.

### C2–C7 — 4.7 µF / 25 V / 0805 / X5R or X7R

Reference exact electrical requirement:
- 4.7 µF;
- 0805;
- X5R/X7R;
- 25 V.

Current cost-conscious candidate:
**Walsin 0805X475K250**
- 4.7 µF;
- 25 V;
- X5R;
- ±10%;
- 0805.

Source:
https://www.lcsc.com/product-detail/_4-7uF-475-10-25V_C168908.html

Quality alternate:
**Kyocera AVX 08053D475KAT2A**
- same electrical class.

Source:
https://www.lcsc.com/pl/product-detail/C165207.html

Important:
before production, check vendor DC-bias curves. Nominal 4.7 µF at 25 V is not the same as effective capacitance on a high-voltage EPD rail.

### C8 — 1 µF / 25 V / 0805 / X7R

Candidate:
**FH 0805B105K250AT**
- 1 µF;
- 25 V;
- X7R;
- ±10%;
- 0805.

Source:
https://www.lcsc.com/pl/product-detail/C111769.html

Quality alternate:
**Kyocera AVX 08053C105KAZ2A**
- 1 µF;
- 25 V;
- X7R;
- 0805.

Source:
https://www.lcsc.com/product-detail/C2168801.html

### C0–C1 — 1 µF logic/core decoupling

SSD1677 reference only requires 6 V class for C0–C1.

ENKU should still standardize on:
- 1 µF;
- X7R/X5R;
- 10 V or 16 V;
- 0603;

if the price difference is negligible, reducing passive SKU diversity.

## Cost philosophy

The EPD-HV block is not a good place for aggressive first-pass cost cutting.

The absolute component cost is small relative to:
- the display;
- PCB assembly;
- battery;
- enclosure.

A failed boost rail can:
- damage a display;
- cause ghosting;
- create intermittent refresh failures;
- generate support and warranty costs much larger than a few PLN saved.

Therefore:

1. use the SSD1677 reference electrical values first;
2. use reputable Q1 / L1 parts for R0.1 characterization;
3. verify actual rail waveforms and temperatures;
4. only then qualify cheaper alternates.

## R0.1 exactness state

| Ref | R0.1 state |
| --- | --- |
| R_RESE 2.2 Ω | electrically frozen |
| D1–D3 MBR0530 | type frozen; vendor alternate allowed |
| Q1 IRLML6346TRPBF | preferred prototype MPN |
| L1 TYS5040470M-10 | R0.1 prototype MPN frozen |
| C2–C7 4.7 µF/25 V | electrical spec frozen |
| C8 1 µF/25 V | electrical spec frozen |
| C0–C1 1 µF | electrical spec frozen |
| 24-pin FPC | connector class frozen; contact side still blocked |

## Final blockers before PCBWay upload

- direct verification of current GDEY0397T81P FPC pin numbering/contact orientation;
- direct verification of current GDEY0426T82-FL01C FPC pin numbering/contact orientation;
- direct verification of FL0426-S01C 6-pin assignment;
- confirm actual panel-loading reference values do not override generic SSD1677 values;
- verify effective capacitance under DC bias;
- scope generated rails on first R0.1 board.

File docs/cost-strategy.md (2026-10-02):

# ENKU cost strategy and kit economics

Status: **planning model — not supplier quotes**

The custom PCB should be designed for manufacturability and kit economics from the start. Cost is a product requirement, not a later optimization.

## Cost rules

1. Prefer one PCB across Base / Cover / Pro variants.
2. Use DNP population options for Hall/frontlight/experimental features where practical.
3. Avoid expensive connectors and sensors unless they materially improve UX.
4. Keep assembly single-sided where practical; move to two-sided only when density forces it.
5. Use common LCSC/JLC/PCBWay-available passives and packages.
6. Maintain at least two sourcing candidates for high-risk parts.
7. Separate open-source reproducibility from premium enclosure/cover options.
8. Customer shipping is modeled separately from reward price.

## Current planning targets

At approximately 50 units, the working cost model currently targets:

- ENKU Base full kit: about **194 PLN/unit**
- ENKU Cover kit: about **213 PLN/unit**
- ENKU Pro kit: about **242 PLN/unit**

These figures include an 8% contingency/yield reserve and currently assume the display, assembled mainboard, BMI270, Hall sensor, battery, enclosure, controls and simple packaging. Pro additionally includes a placeholder frontlight optical/electrical delta.

They are not purchase quotes and will be replaced with actual PCBWay/Good Display/enclosure supplier pricing.

## Campaign price placeholders

For Kickstarter planning only:

- Electronics Kit: **299 PLN**
- Base Kit: **349 PLN**
- Cover Kit: **399 PLN**
- Pro Kit: **449 PLN**

The spreadsheet model reserves Kickstarter/platform processing fees and a configurable VAT buffer. Outbound shipping, campaign advertising, certification, returns and tooling are excluded and must be modeled separately before launch.

## Cost-down opportunities

Priority order:

1. direct panel/project pricing
2. PCB assembly quote at 50/100/250 units
3. replace premium microSD/FPC connectors with qualified lower-cost equivalents
4. source ESP32-S3 module through high-volume distributor/assembler channel
5. volume-price BMI270
6. standardize battery and cable
7. injection-molded or batch-printed enclosure only after demand is proven
8. optimize frontlight optics separately for Pro

## Variant philosophy

### Base
The campaign anchor: lowest-cost complete reader while retaining BMI270 and physical reading controls.

### Cover
Adds folio/magnets/Hall-driven wake-sleep with no core PCB redesign.

### Pro
Adds the frontlight optical stack and populated frontlight electronics while keeping the same compute platform.

## Manufacturing gates before Kickstarter

Do not publish a fixed reward price until:

- Good Display panel quote is received
- PCBWay or equivalent turnkey quote is received
- R0.1 is electrically validated
- enclosure print time/material cost is measured
- battery source is locked
- packaging is tested
- certification/compliance path is understood
- fulfillment shipping prices are known
- at least 10–15% total production risk reserve remains after all fees/tax assumptions

The working spreadsheet is `ENKU_Mainboard_R0.1_Cost_and_Kickstarter_Model.xlsx`.

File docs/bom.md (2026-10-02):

# ENKU BOM / Parts Status

This document tracks the current component plan for ENKU and makes a clear distinction between selected hardware, parts awaiting validation, and components that still need sourcing.

The BOM will remain intentionally conservative until the real hardware has been measured and tested.

## Current parts

| Category | Part / target | Status | Notes |
| --- | --- | --- | --- |
| Main board | Waveshare ESP32-S3-ePaper-3.97 | **Selected / ordered** | Reference hardware platform |
| MCU | ESP32-S3 | **Fixed by platform** | Firmware target |
| Display | 3.97″ e-paper, 800 × 480 | **Fixed by platform** | Portrait + landscape UI |
| Storage | microSD / local storage | **To verify** | Platform capability; firmware/filesystem behavior to test |
| Connectivity | Wi-Fi | **Planned** | Optional for reading; used for local management |
| Connectivity | BLE | **Available on platform** | No committed ENKU feature yet |
| Battery | Single-cell 3.7 V Li-Po, around 2000 mAh | **TBD** | Final dimensions, connector and runtime pending |
| Power switch | Compact hard power switch | **TBD** | Mechanical and electrical implementation pending |
| Controls | Physical buttons / onboard controls | **To verify** | Exact mapping and wake behavior pending |
| Fasteners | M2-class or similar | **TBD** | Final choice after mechanical measurement |
| Enclosure | 3D-printable custom case | **Planned** | Starts after board/display measurement |

## Battery sourcing target

The current working target is:

- single-cell Li-Po;
- 3.7 V nominal;
- around 2000 mAh;
- protected pack preferred;
- thin rectangular format suitable for a compact enclosure;
- connector compatible with the final board/power architecture.

A mechanical envelope around **5 × 50 × 60 mm** has been considered, but this is **not final**.

Before locking the battery, ENKU will verify:

- actual free volume inside the enclosure;
- connector type;
- connector polarity;
- board charge-current limits;
- protection circuit;
- cable routing;
- thermal clearance;
- effect on final device thickness.

## Supplier priorities

ENKU is currently interested in suppliers that can provide one or more of the following:

### Reference hardware

- Waveshare ESP32-S3-ePaper-3.97 development boards;
- replacement units for testing;
- access to accurate technical documentation;
- project/sample pricing.

### Power

- suitable 3.7 V Li-Po packs;
- documented connector/polarity;
- dimensional drawings;
- protection-circuit information;
- repeatable availability.

### Mechanical components

- compact power switches;
- tactile buttons where needed;
- small screws and fasteners;
- enclosure hardware;
- prototype quantities without large MOQ requirements.

## Sourcing principles

Parts selected for ENKU should ideally be:

- realistically available in Europe;
- purchasable in small quantities;
- documented;
- replaceable by future builders;
- not tied to one temporary marketplace listing;
- consistent enough for repeatable enclosure and firmware work.

The project will prefer reproducibility over selecting a rare component solely because it is slightly smaller or cheaper.

## Partner recognition

Where appropriate, companies supporting ENKU with evaluation hardware, sample components, project pricing or technical support can be listed in project documentation as:

- **Hardware Partner**
- **Component Supplier**
- **Development Hardware Supplier**

This recognition does not imply technical endorsement of untested parts. Components are still validated before they become part of the reference BOM.

## What is intentionally not fixed yet

The following should remain open until hardware testing:

- exact battery model;
- exact battery connector;
- final power switch;
- final fastener dimensions;
- final enclosure hardware;
- final case dimensions;
- alternate board revisions.

See [Hardware baseline](hardware.md) for the validation plan.

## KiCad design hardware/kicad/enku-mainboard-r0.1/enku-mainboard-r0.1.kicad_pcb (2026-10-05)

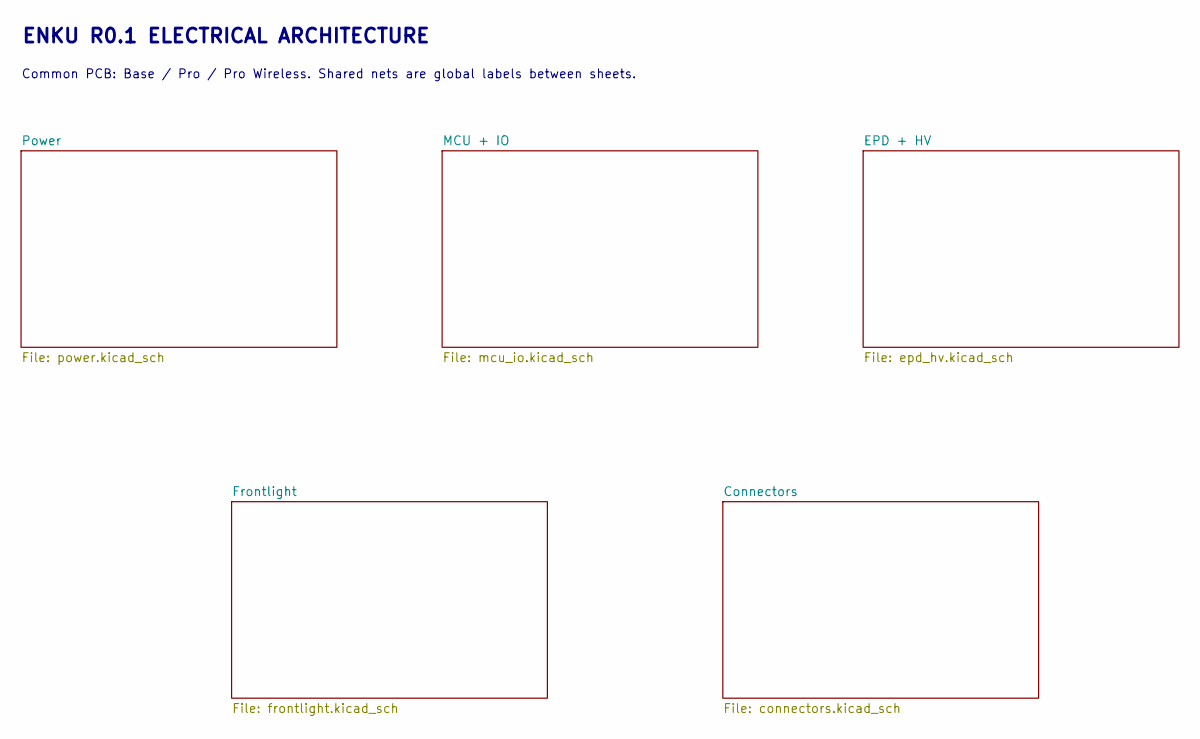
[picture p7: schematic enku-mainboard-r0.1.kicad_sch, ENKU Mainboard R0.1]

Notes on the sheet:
ENKU R0.1 ELECTRICAL ARCHITECTURE
Common PCB: Base / Pro / Pro Wireless. Shared nets are global labels between sheets.

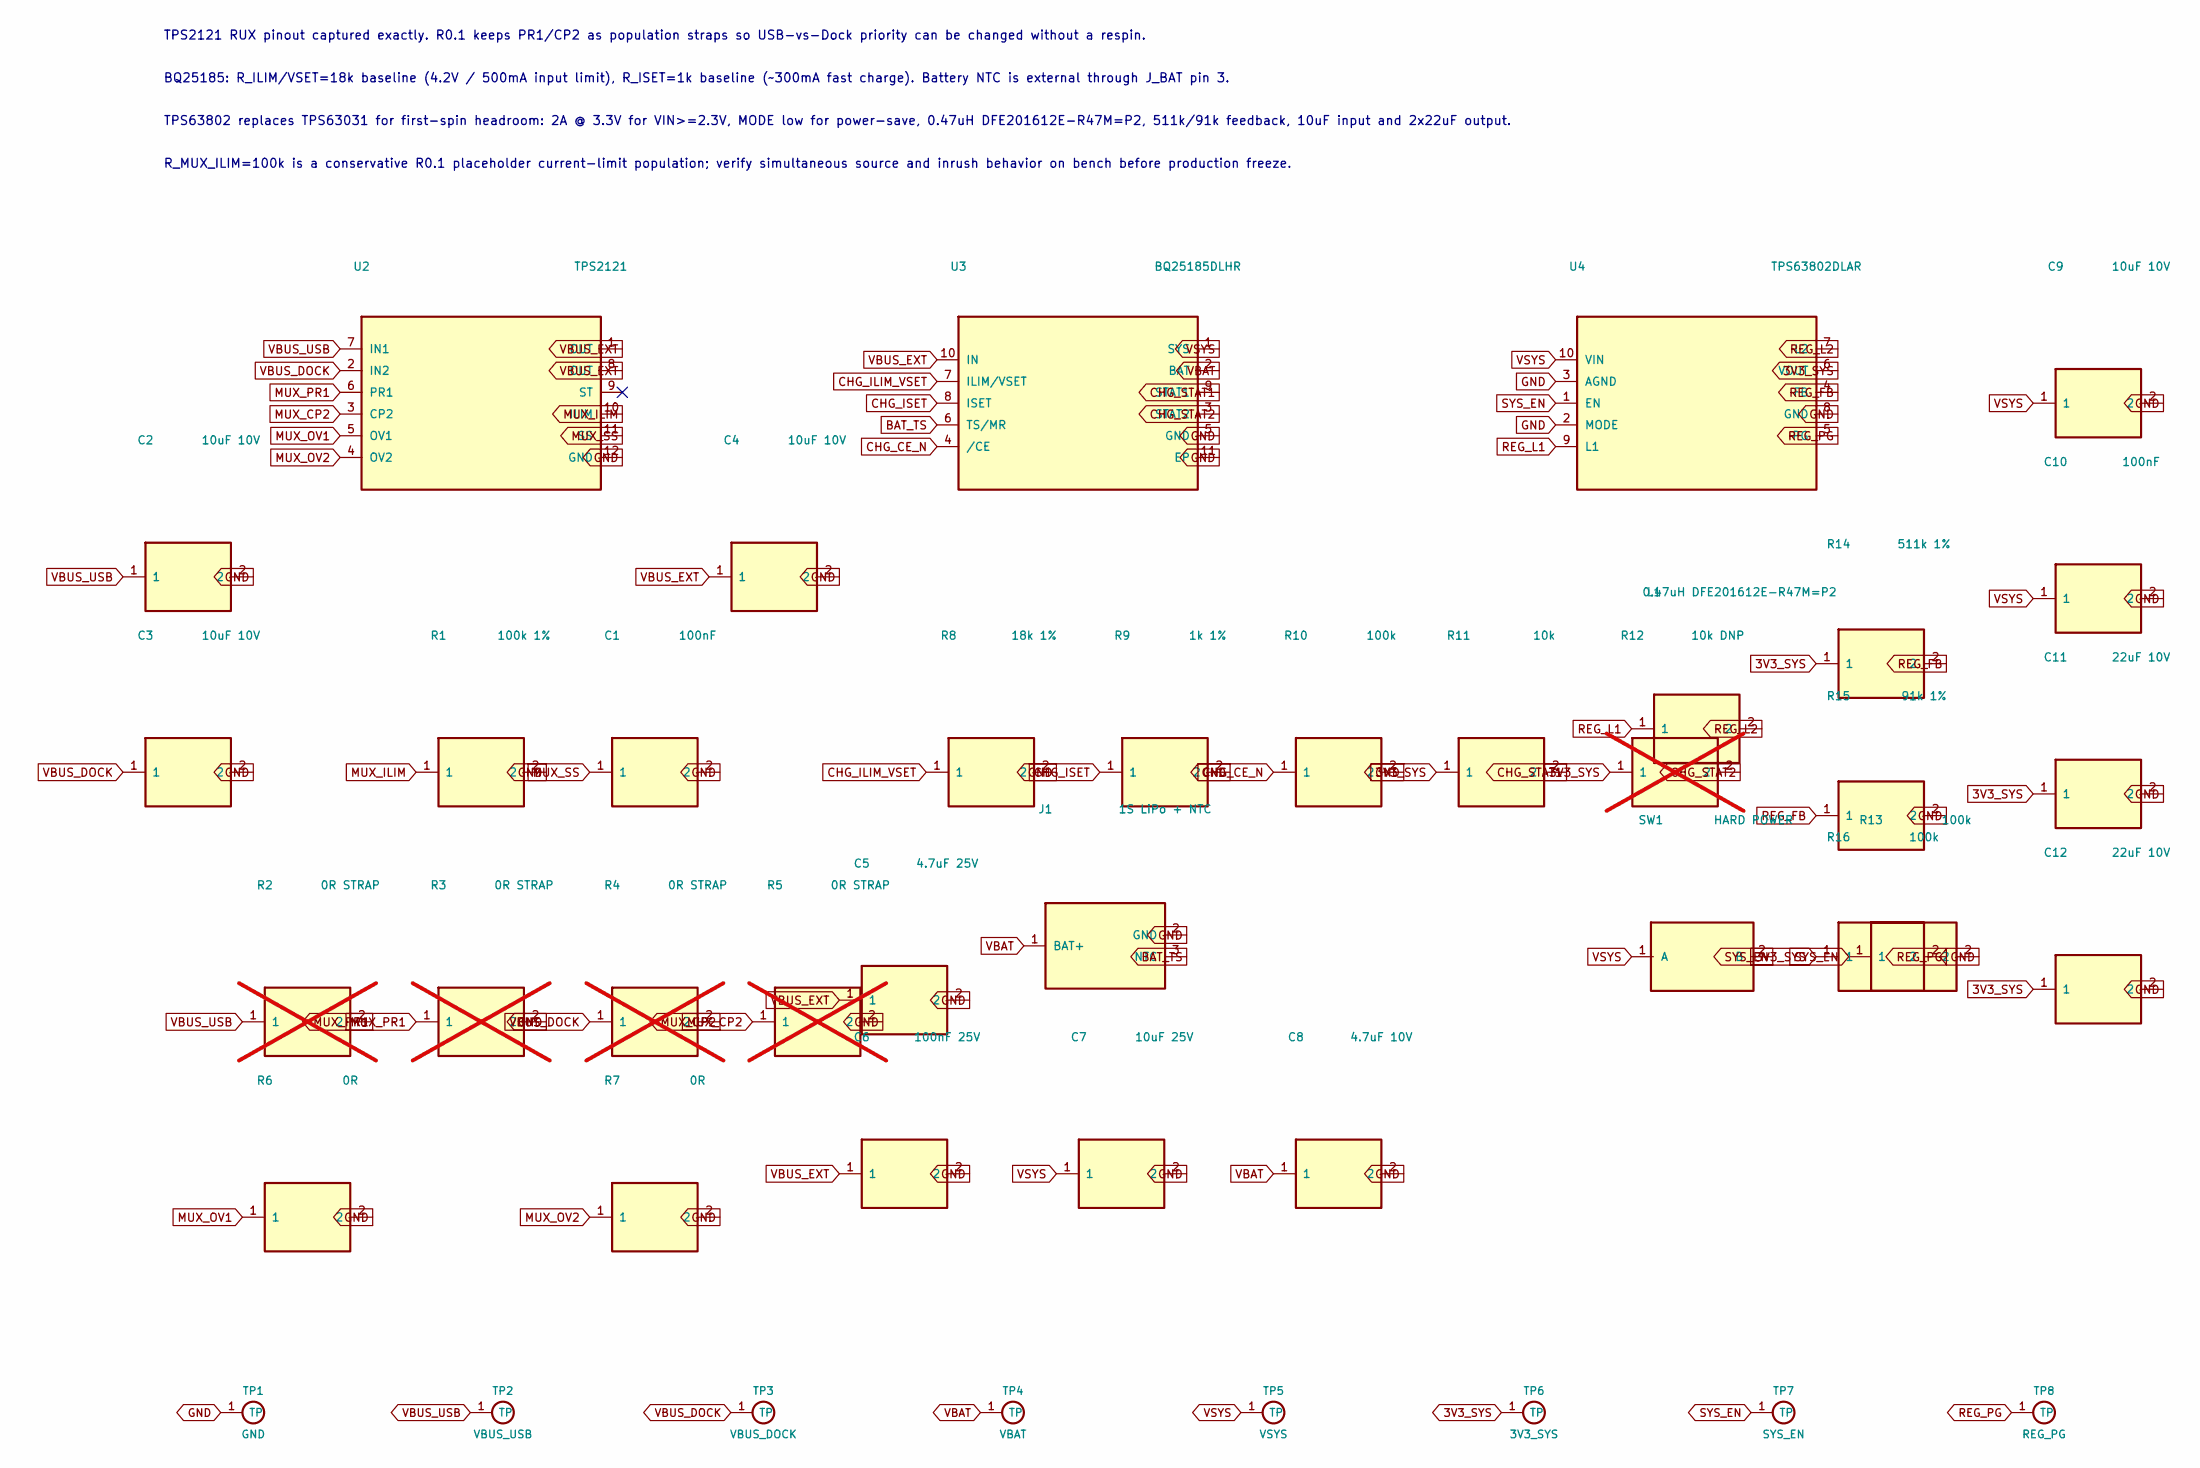
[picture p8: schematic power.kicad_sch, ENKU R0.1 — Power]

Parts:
C1, C10: 100nF; C_0603_1608Metric
C2, C3, C4, C9: 10uF 10V; C_0805_2012Metric
C5: 4.7uF 25V; C_0805_2012Metric
C6: 100nF 25V; C_0603_1608Metric
C7: 10uF 25V; C_0805_2012Metric
C8: 4.7uF 10V; C_0805_2012Metric
C11, C12: 22uF 10V; C_0805_2012Metric
J1: 1S LiPo + NTC; JST_PH_3_PLACEMENT
L1: 0.47uH DFE201612E-R47M=P2; Murata_DFE201612E
R1: 100k 1%; R_0603_1608Metric
R2, R3, R4, R5: 0R STRAP; R_0603_1608Metric; not fitted
R6, R7: 0R; R_0603_1608Metric
R8: 18k 1%; R_0603_1608Metric
R9: 1k 1%; R_0603_1608Metric
R10, R13, R16: 100k; R_0603_1608Metric
R11: 10k; R_0603_1608Metric
R12: 10k DNP; R_0603_1608Metric; not fitted
R14: 511k 1%; R_0603_1608Metric
R15: 91k 1%; R_0603_1608Metric
SW1: HARD POWER; HARD_POWER_SWITCH_PLACEMENT
TP1: GND; TestPoint_Pad_D1.5mm
TP2: VBUS_USB; TestPoint_Pad_D1.5mm
TP3: VBUS_DOCK; TestPoint_Pad_D1.5mm
TP4: VBAT; TestPoint_Pad_D1.5mm
TP5: VSYS; TestPoint_Pad_D1.5mm
TP6: 3V3_SYS; TestPoint_Pad_D1.5mm
TP7: SYS_EN; TestPoint_Pad_D1.5mm
TP8: REG_PG; TestPoint_Pad_D1.5mm
U2: TPS2121; TPS2121_RUX0012A
U3: BQ25185DLHR; BQ25185_DLH0010A
U4: TPS63802DLAR; TPS63802_DLA0010A

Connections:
3V3_SYS: C11.1, C12.1, R11.1, R12.1, R14.1, R16.1, TP6.1, U4.6 (VOUT); also elsewhere on the board
BAT_TS: J1.3 (NTC), U3.6 (TS/MR)
CHG_CE_N: R10.1, U3.4 (/CE)
CHG_ILIM_VSET: R8.1, U3.7 (ILIM/VSET)
CHG_ISET: R9.1, U3.8 (ISET)
CHG_STAT1: R11.2, U3.9 (STAT1); also elsewhere on the board
CHG_STAT2: R12.2, U3.3 (STAT2)
GND: C1.2, C2.2, C3.2, C4.2, C5.2, C6.2, C7.2, C8.2, C9.2, C10.2, C11.2, C12.2, J1.2 (GND), R1.2, R3.2, R5.2, R6.2, R7.2, R8.2, R9.2, R10.2, R13.2, R15.2, TP1.1, U2.12 (GND), U3.5 (GND), U3.11 (EP), U4.2 (MODE), U4.3 (AGND), U4.8 (GND); also elsewhere on the board
MUX_CP2: R4.2, R5.1, U2.3 (CP2)
MUX_ILIM: R1.1, U2.10 (ILIM)
MUX_OV1: R6.1, U2.5 (OV1)
MUX_OV2: R7.1, U2.4 (OV2)
MUX_PR1: R2.2, R3.1, U2.6 (PR1)
MUX_SS: C1.1, U2.11 (SS)
REG_FB: R14.2, R15.1, U4.4 (FB)
REG_L1: L1.1, U4.9 (L1)
REG_L2: L1.2, U4.7 (L2)
REG_PG: R16.2, TP8.1, U4.5 (PG)
SYS_EN: R13.1, SW1.2 (B), TP7.1, U4.1 (EN)
VBAT: C8.1, J1.1 (BAT+), TP4.1, U3.2 (BAT); also elsewhere on the board
VBUS_DOCK: C3.1, R4.1, TP3.1, U2.2 (IN2); also elsewhere on the board
VBUS_EXT: C4.1, C5.1, C6.1, U2.1 (OUT), U2.8 (OUT), U3.10 (IN)
VBUS_USB: C2.1, R2.1, TP2.1, U2.7 (IN1); also elsewhere on the board
VSYS: C7.1, C9.1, C10.1, SW1.1 (A), TP5.1, U3.1 (SYS), U4.10 (VIN); also elsewhere on the board

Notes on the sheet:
TPS2121 RUX pinout captured exactly. R0.1 keeps PR1/CP2 as population straps so USB-vs-Dock priority can be changed without a respin.
BQ25185: R_ILIM/VSET=18k baseline (4.2V / 500mA input limit), R_ISET=1k baseline (~300mA fast charge). Battery NTC is external through J_BAT pin 3.
TPS63802 replaces TPS63031 for first-spin headroom: 2A @ 3.3V for VIN>=2.3V, MODE low for power-save, 0.47uH DFE201612E-R47M=P2, 511k/91k feedback, 10uF input and 2x22uF output.
R_MUX_ILIM=100k is a conservative R0.1 placeholder current-limit population; verify simultaneous source and inrush behavior on bench before production freeze.

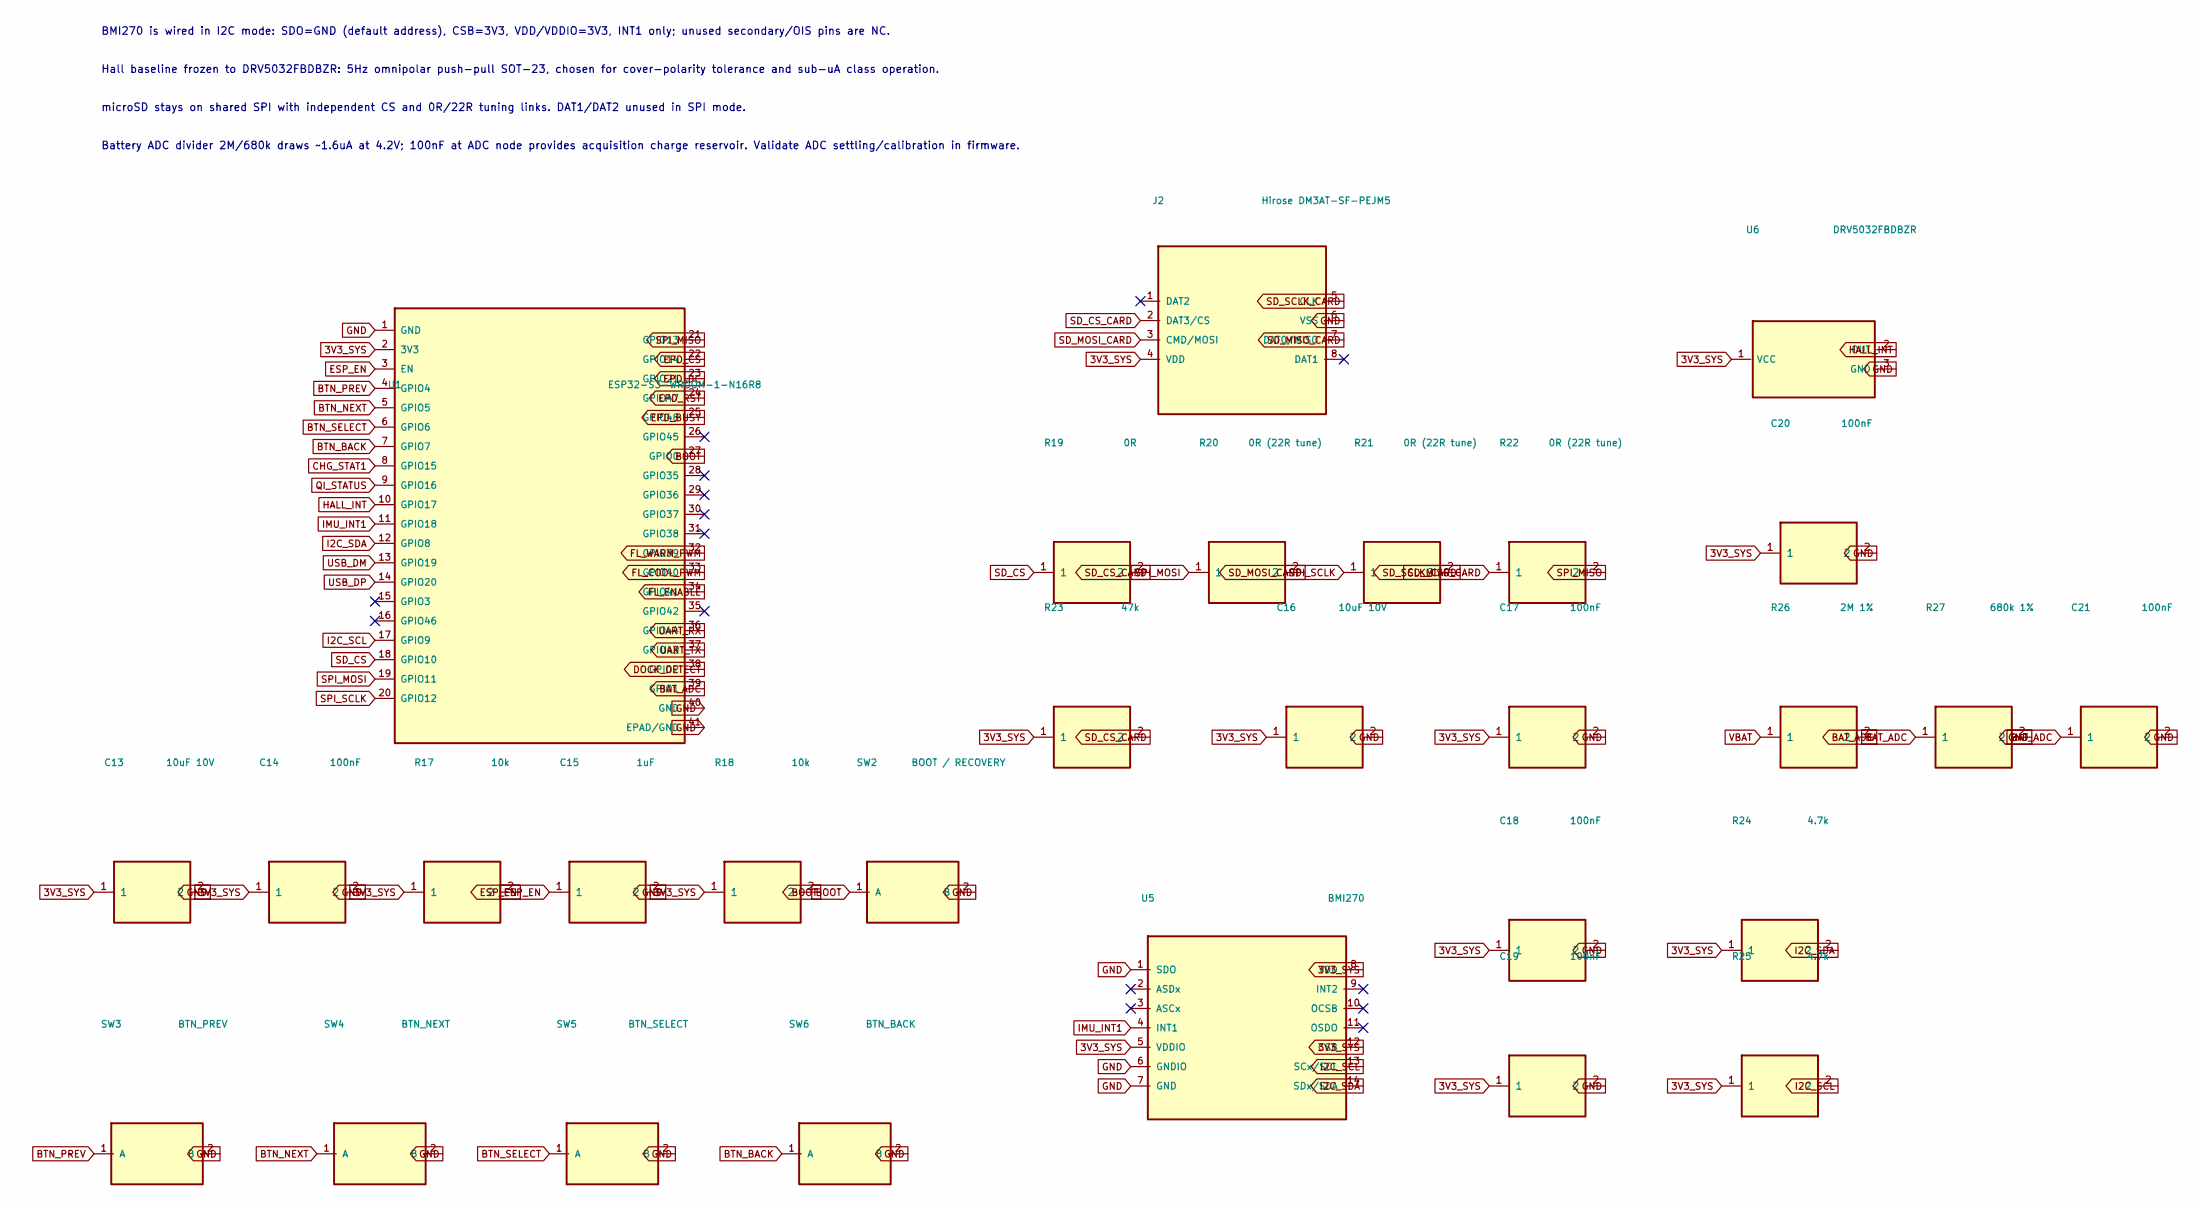
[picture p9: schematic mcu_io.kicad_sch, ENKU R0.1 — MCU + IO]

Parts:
C13, C16: 10uF 10V; C_0805_2012Metric
C14, C17, C18, C19, C20, C21: 100nF; C_0603_1608Metric
C15: 1uF; C_0603_1608Metric
J2: Hirose DM3AT-SF-PEJM5; MICROSD_DM3AT_ENKU
R17, R18: 10k; R_0603_1608Metric
R19: 0R; R_0603_1608Metric
R20, R21, R22: 0R (22R tune); R_0603_1608Metric
R23: 47k; R_0603_1608Metric
R24, R25: 4.7k; R_0603_1608Metric
R26: 2M 1%; R_0603_1608Metric
R27: 680k 1%; R_0603_1608Metric
SW2: BOOT / RECOVERY; SW_SPST_TL3342
SW3: BTN_PREV; READING_BUTTON_PLACEMENT
SW4: BTN_NEXT; READING_BUTTON_PLACEMENT
SW5: BTN_SELECT; READING_BUTTON_PLACEMENT
SW6: BTN_BACK; READING_BUTTON_PLACEMENT
U1: ESP32-S3-WROOM-1-N16R8; ESP32-S3-WROOM-1
U5: BMI270; BMI270_Bosch_LGA14
U6: DRV5032FBDBZR; SOT-23

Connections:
3V3_SYS: C13.1, C14.1, C16.1, C17.1, C18.1, C19.1, C20.1, J2.4 (VDD), R17.1, R18.1, R23.1, R24.1, R25.1, U1.2 (3V3), U5.5 (VDDIO), U5.8 (VDD), U5.12 (CSB), U6.1 (VCC); also elsewhere on the board
BAT_ADC: C21.1, R26.2, R27.1, U1.39 (GPIO1)
BOOT: R18.2, SW2.1 (A), U1.27 (GPIO0); also elsewhere on the board
BTN_BACK: SW6.1 (A), U1.7 (GPIO7)
BTN_NEXT: SW4.1 (A), U1.5 (GPIO5)
BTN_PREV: SW3.1 (A), U1.4 (GPIO4)
BTN_SELECT: SW5.1 (A), U1.6 (GPIO6)
CHG_STAT1: U1.8 (GPIO15); also elsewhere on the board
DOCK_DETECT: U1.38 (GPIO2); also elsewhere on the board
EPD_BUSY: U1.25 (GPIO48); also elsewhere on the board
EPD_CS: U1.22 (GPIO14); also elsewhere on the board
EPD_DC: U1.23 (GPIO21); also elsewhere on the board
EPD_RST: U1.24 (GPIO47); also elsewhere on the board
ESP_EN: C15.1, R17.2, U1.3 (EN); also elsewhere on the board
FL_COOL_PWM: U1.33 (GPIO40); also elsewhere on the board
FL_ENABLE: U1.34 (GPIO41); also elsewhere on the board
FL_WARM_PWM: U1.32 (GPIO39); also elsewhere on the board
GND: C13.2, C14.2, C15.2, C16.2, C17.2, C18.2, C19.2, C20.2, C21.2, J2.6 (VSS), R27.2, SW2.2 (B), SW3.2 (B), SW4.2 (B), SW5.2 (B), SW6.2 (B), U1.1 (GND), U1.40 (GND), U1.41 (EPAD/GND), U5.1 (SDO), U5.6 (GNDIO), U5.7 (GND), U6.3 (GND); also elsewhere on the board
HALL_INT: U1.10 (GPIO17), U6.2 (OUT)
I2C_SCL: R25.2, U1.17 (GPIO9), U5.13 (SCx/SCL)
I2C_SDA: R24.2, U1.12 (GPIO8), U5.14 (SDx/SDA)
IMU_INT1: U1.11 (GPIO18), U5.4 (INT1)
QI_STATUS: U1.9 (GPIO16); also elsewhere on the board
SD_CS: R19.1, U1.18 (GPIO10)
SD_CS_CARD: J2.2 (DAT3/CS), R19.2, R23.2
SD_MISO_CARD: J2.7 (DAT0/MISO), R22.1
SD_MOSI_CARD: J2.3 (CMD/MOSI), R20.2
SD_SCLK_CARD: J2.5 (CLK), R21.2
SPI_MISO: R22.2, U1.21 (GPIO13)
SPI_MOSI: R20.1, U1.19 (GPIO11); also elsewhere on the board
SPI_SCLK: R21.1, U1.20 (GPIO12); also elsewhere on the board
UART_RX: U1.36 (GPIO44); also elsewhere on the board
UART_TX: U1.37 (GPIO43); also elsewhere on the board
USB_DM: U1.13 (GPIO19); also elsewhere on the board
USB_DP: U1.14 (GPIO20); also elsewhere on the board
VBAT: R26.1; also elsewhere on the board

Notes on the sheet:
BMI270 is wired in I2C mode: SDO=GND (default address), CSB=3V3, VDD/VDDIO=3V3, INT1 only; unused secondary/OIS pins are NC.
Hall baseline frozen to DRV5032FBDBZR: 5Hz omnipolar push-pull SOT-23, chosen for cover-polarity tolerance and sub-uA class operation.
microSD stays on shared SPI with independent CS and 0R/22R tuning links. DAT1/DAT2 unused in SPI mode.
Battery ADC divider 2M/680k draws ~1.6uA at 4.2V; 100nF at ADC node provides acquisition charge reservoir. Validate ADC settling/calibration in firmware.

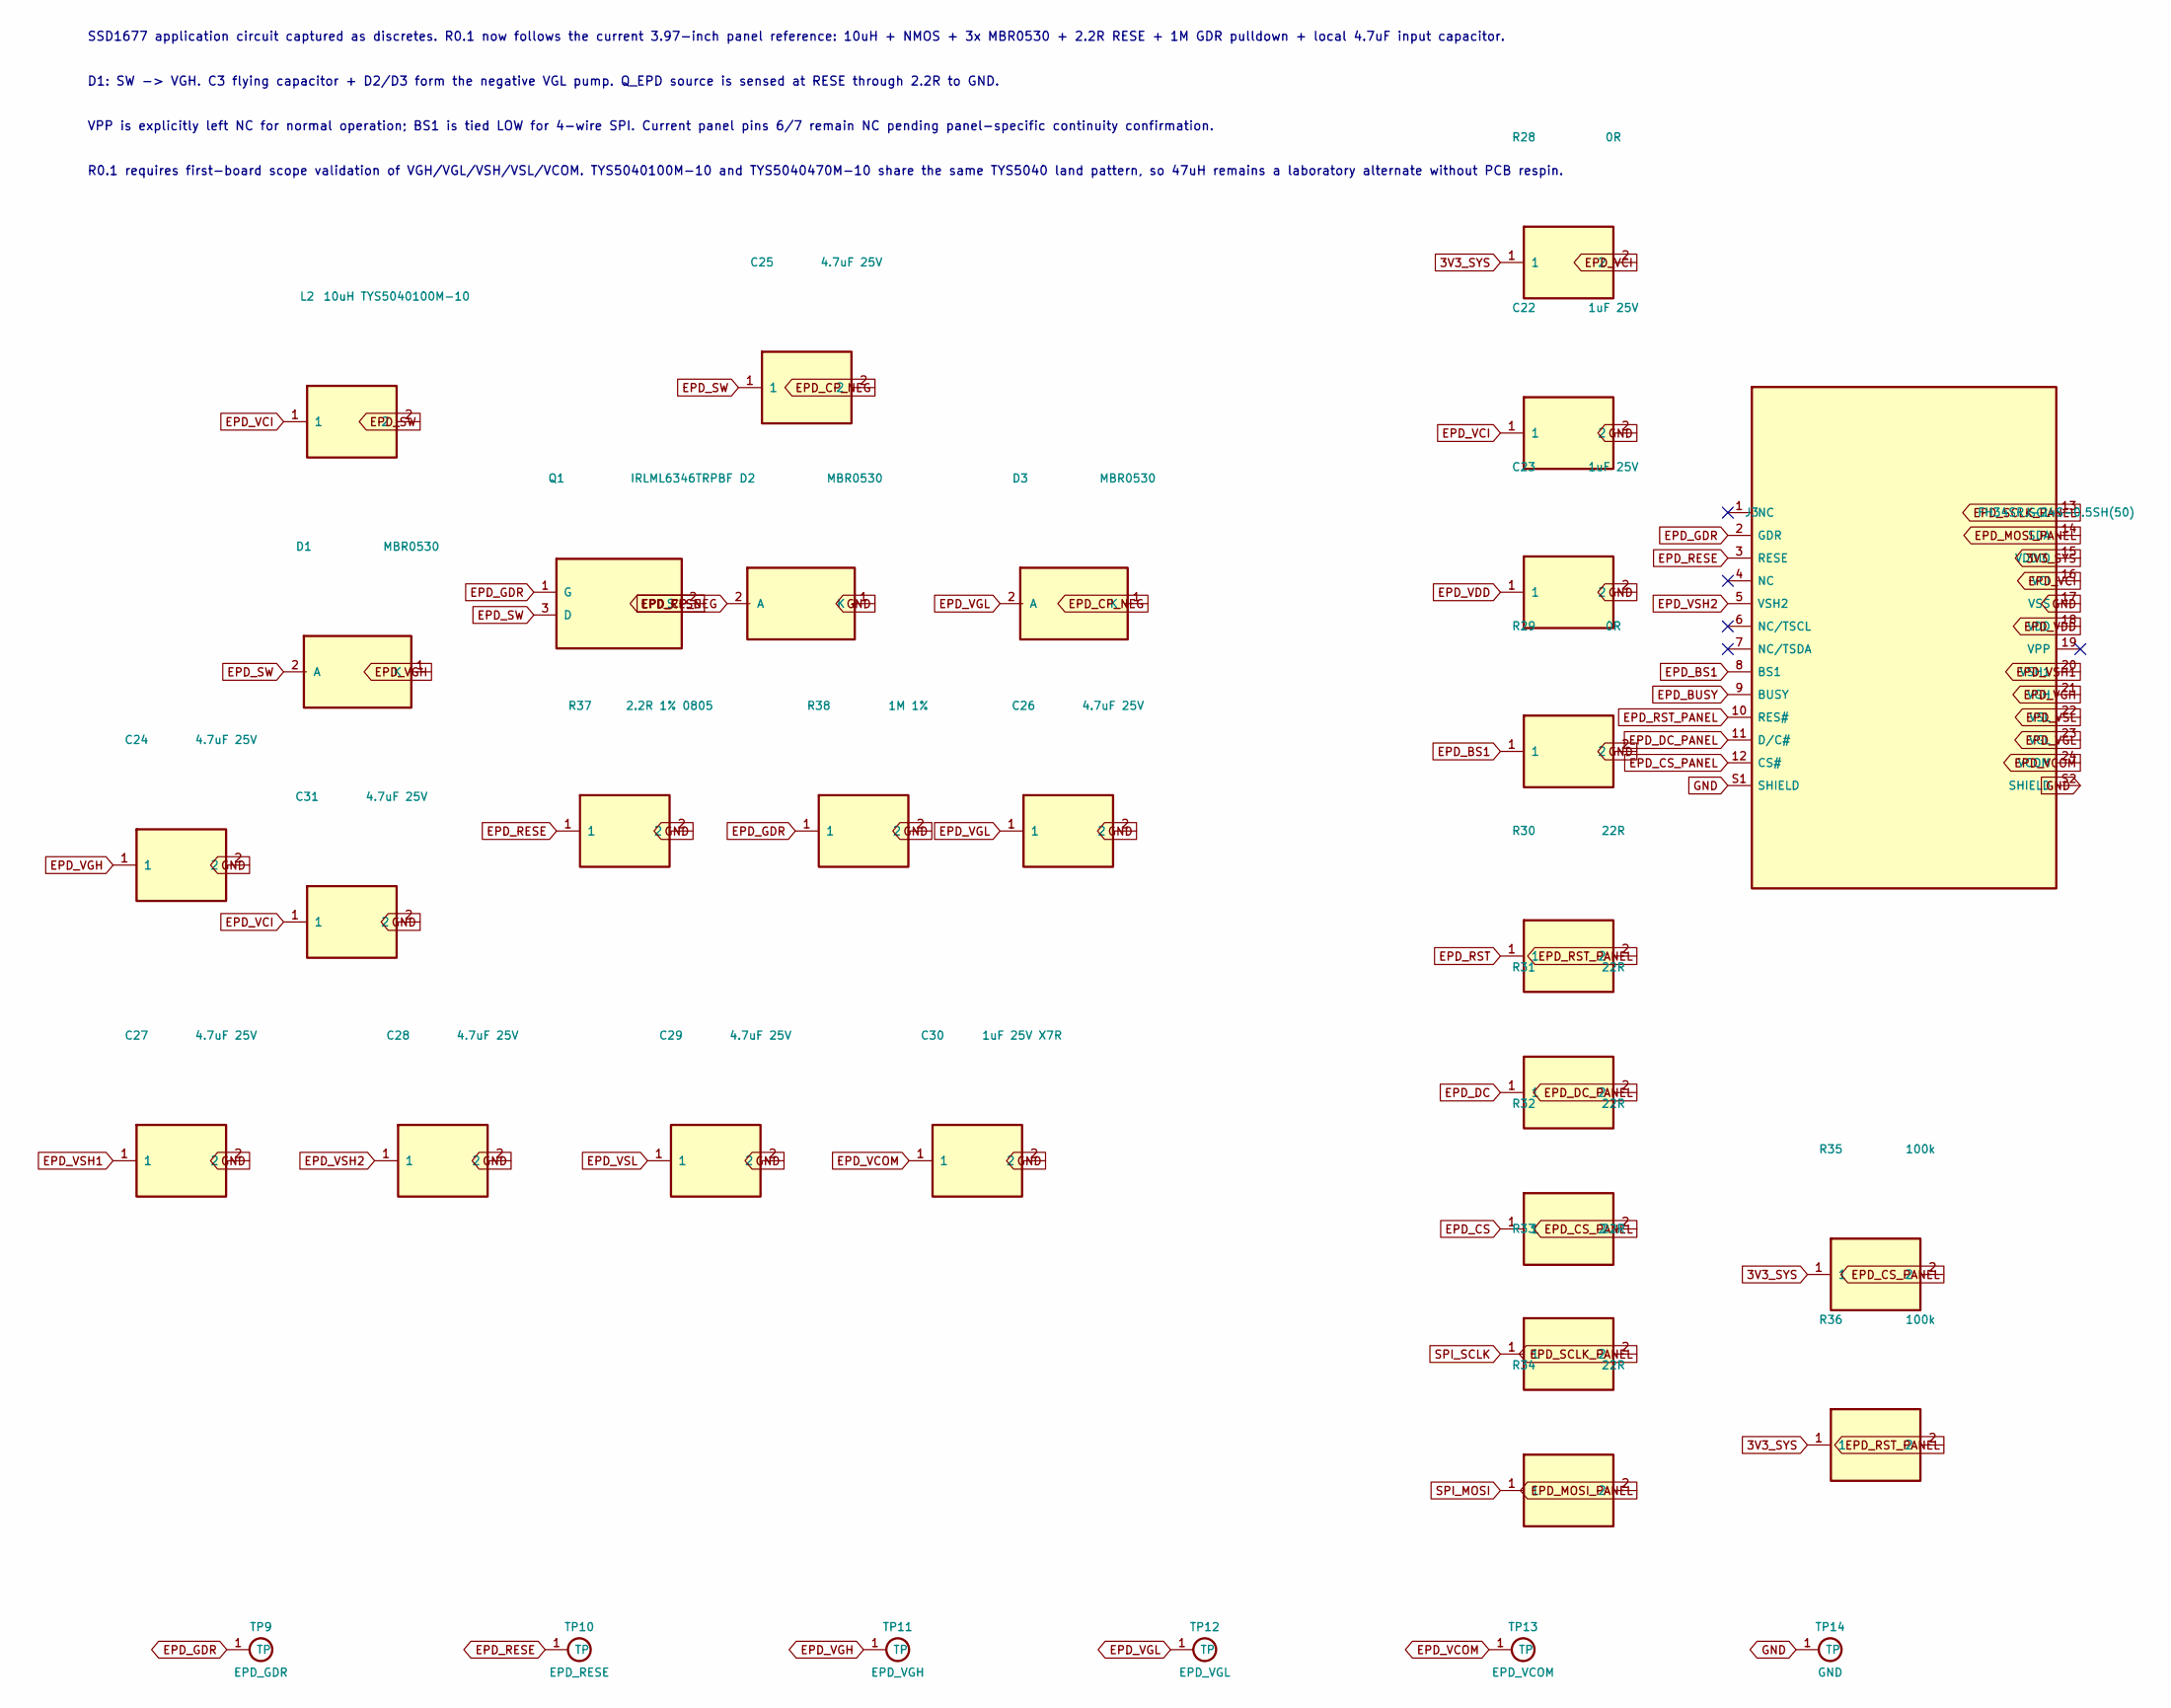
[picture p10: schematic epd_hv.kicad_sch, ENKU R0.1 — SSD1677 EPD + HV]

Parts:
C22, C23: 1uF 25V; C_0603_1608Metric
C24, C25, C26, C27, C28, C29, C31: 4.7uF 25V; C_0805_2012Metric
C30: 1uF 25V X7R; C_0805_2012Metric
D1, D2, D3: MBR0530; D_SOD-123
J3: FH34SRJ-24S-0.5SH(50); FH34SRJ-24S-0.5SH
L2: 10uH TYS5040100M-10; TYS5040_5x5
Q1: IRLML6346TRPBF; SOT-23
R28, R29: 0R; R_0603_1608Metric
R30, R31, R32, R33, R34: 22R; R_0603_1608Metric
R35, R36: 100k; R_0603_1608Metric
R37: 2.2R 1% 0805; R_0805_2012Metric
R38: 1M 1%; R_0603_1608Metric
TP9: EPD_GDR; TestPoint_Pad_D1.5mm
TP10: EPD_RESE; TestPoint_Pad_D1.5mm
TP11: EPD_VGH; TestPoint_Pad_D1.5mm
TP12: EPD_VGL; TestPoint_Pad_D1.5mm
TP13: EPD_VCOM; TestPoint_Pad_D1.5mm
TP14: GND; TestPoint_Pad_D1.5mm

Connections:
3V3_SYS: J3.15 (VDDIO), R28.1, R35.1, R36.1; also elsewhere on the board
EPD_BS1: J3.8 (BS1), R29.1
EPD_BUSY: J3.9 (BUSY); also elsewhere on the board
EPD_CP_NEG: C25.2, D2.2 (A), D3.1 (K)
EPD_CS: R32.1; also elsewhere on the board
EPD_CS_PANEL: J3.12 (CS#), R32.2, R35.2
EPD_DC: R31.1; also elsewhere on the board
EPD_DC_PANEL: J3.11 (D/C#), R31.2
EPD_GDR: J3.2 (GDR), Q1.1 (G), R38.1, TP9.1
EPD_MOSI_PANEL: J3.14 (SDA), R34.2
EPD_RESE: J3.3 (RESE), Q1.2 (S), R37.1, TP10.1
EPD_RST: R30.1; also elsewhere on the board
EPD_RST_PANEL: J3.10 (RES#), R30.2, R36.2
EPD_SCLK_PANEL: J3.13 (SCL), R33.2
EPD_SW: C25.1, D1.2 (A), L2.2, Q1.3 (D)
EPD_VCI: C22.1, C31.1, J3.16 (VCI), L2.1, R28.2
EPD_VCOM: C30.1, J3.24 (VCOM), TP13.1
EPD_VDD: C23.1, J3.18 (VDD)
EPD_VGH: C24.1, D1.1 (K), J3.21 (VGH), TP11.1
EPD_VGL: C26.1, D3.2 (A), J3.23 (VGL), TP12.1
EPD_VSH1: C27.1, J3.20 (VSH1)
EPD_VSH2: C28.1, J3.5 (VSH2)
EPD_VSL: C29.1, J3.22 (VSL)
GND: C22.2, C23.2, C24.2, C26.2, C27.2, C28.2, C29.2, C30.2, C31.2, D2.1 (K), J3.17 (VSS), J3.S1 (SHIELD), J3.S2 (SHIELD), R29.2, R37.2, R38.2, TP14.1; also elsewhere on the board
SPI_MOSI: R34.1; also elsewhere on the board
SPI_SCLK: R33.1; also elsewhere on the board

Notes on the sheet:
SSD1677 application circuit captured as discretes. R0.1 now follows the current 3.97-inch panel reference: 10uH + NMOS + 3x MBR0530 + 2.2R RESE + 1M GDR pulldown + local 4.7uF input capacitor.
D1: SW -> VGH. C3 flying capacitor + D2/D3 form the negative VGL pump. Q_EPD source is sensed at RESE through 2.2R to GND.
VPP is explicitly left NC for normal operation; BS1 is tied LOW for 4-wire SPI. Current panel pins 6/7 remain NC pending panel-specific continuity confirmation.
R0.1 requires first-board scope validation of VGH/VGL/VSH/VSL/VCOM. TYS5040100M-10 and TYS5040470M-10 share the same TYS5040 land pattern, so 47uH remains a laboratory alternate without PCB respin.

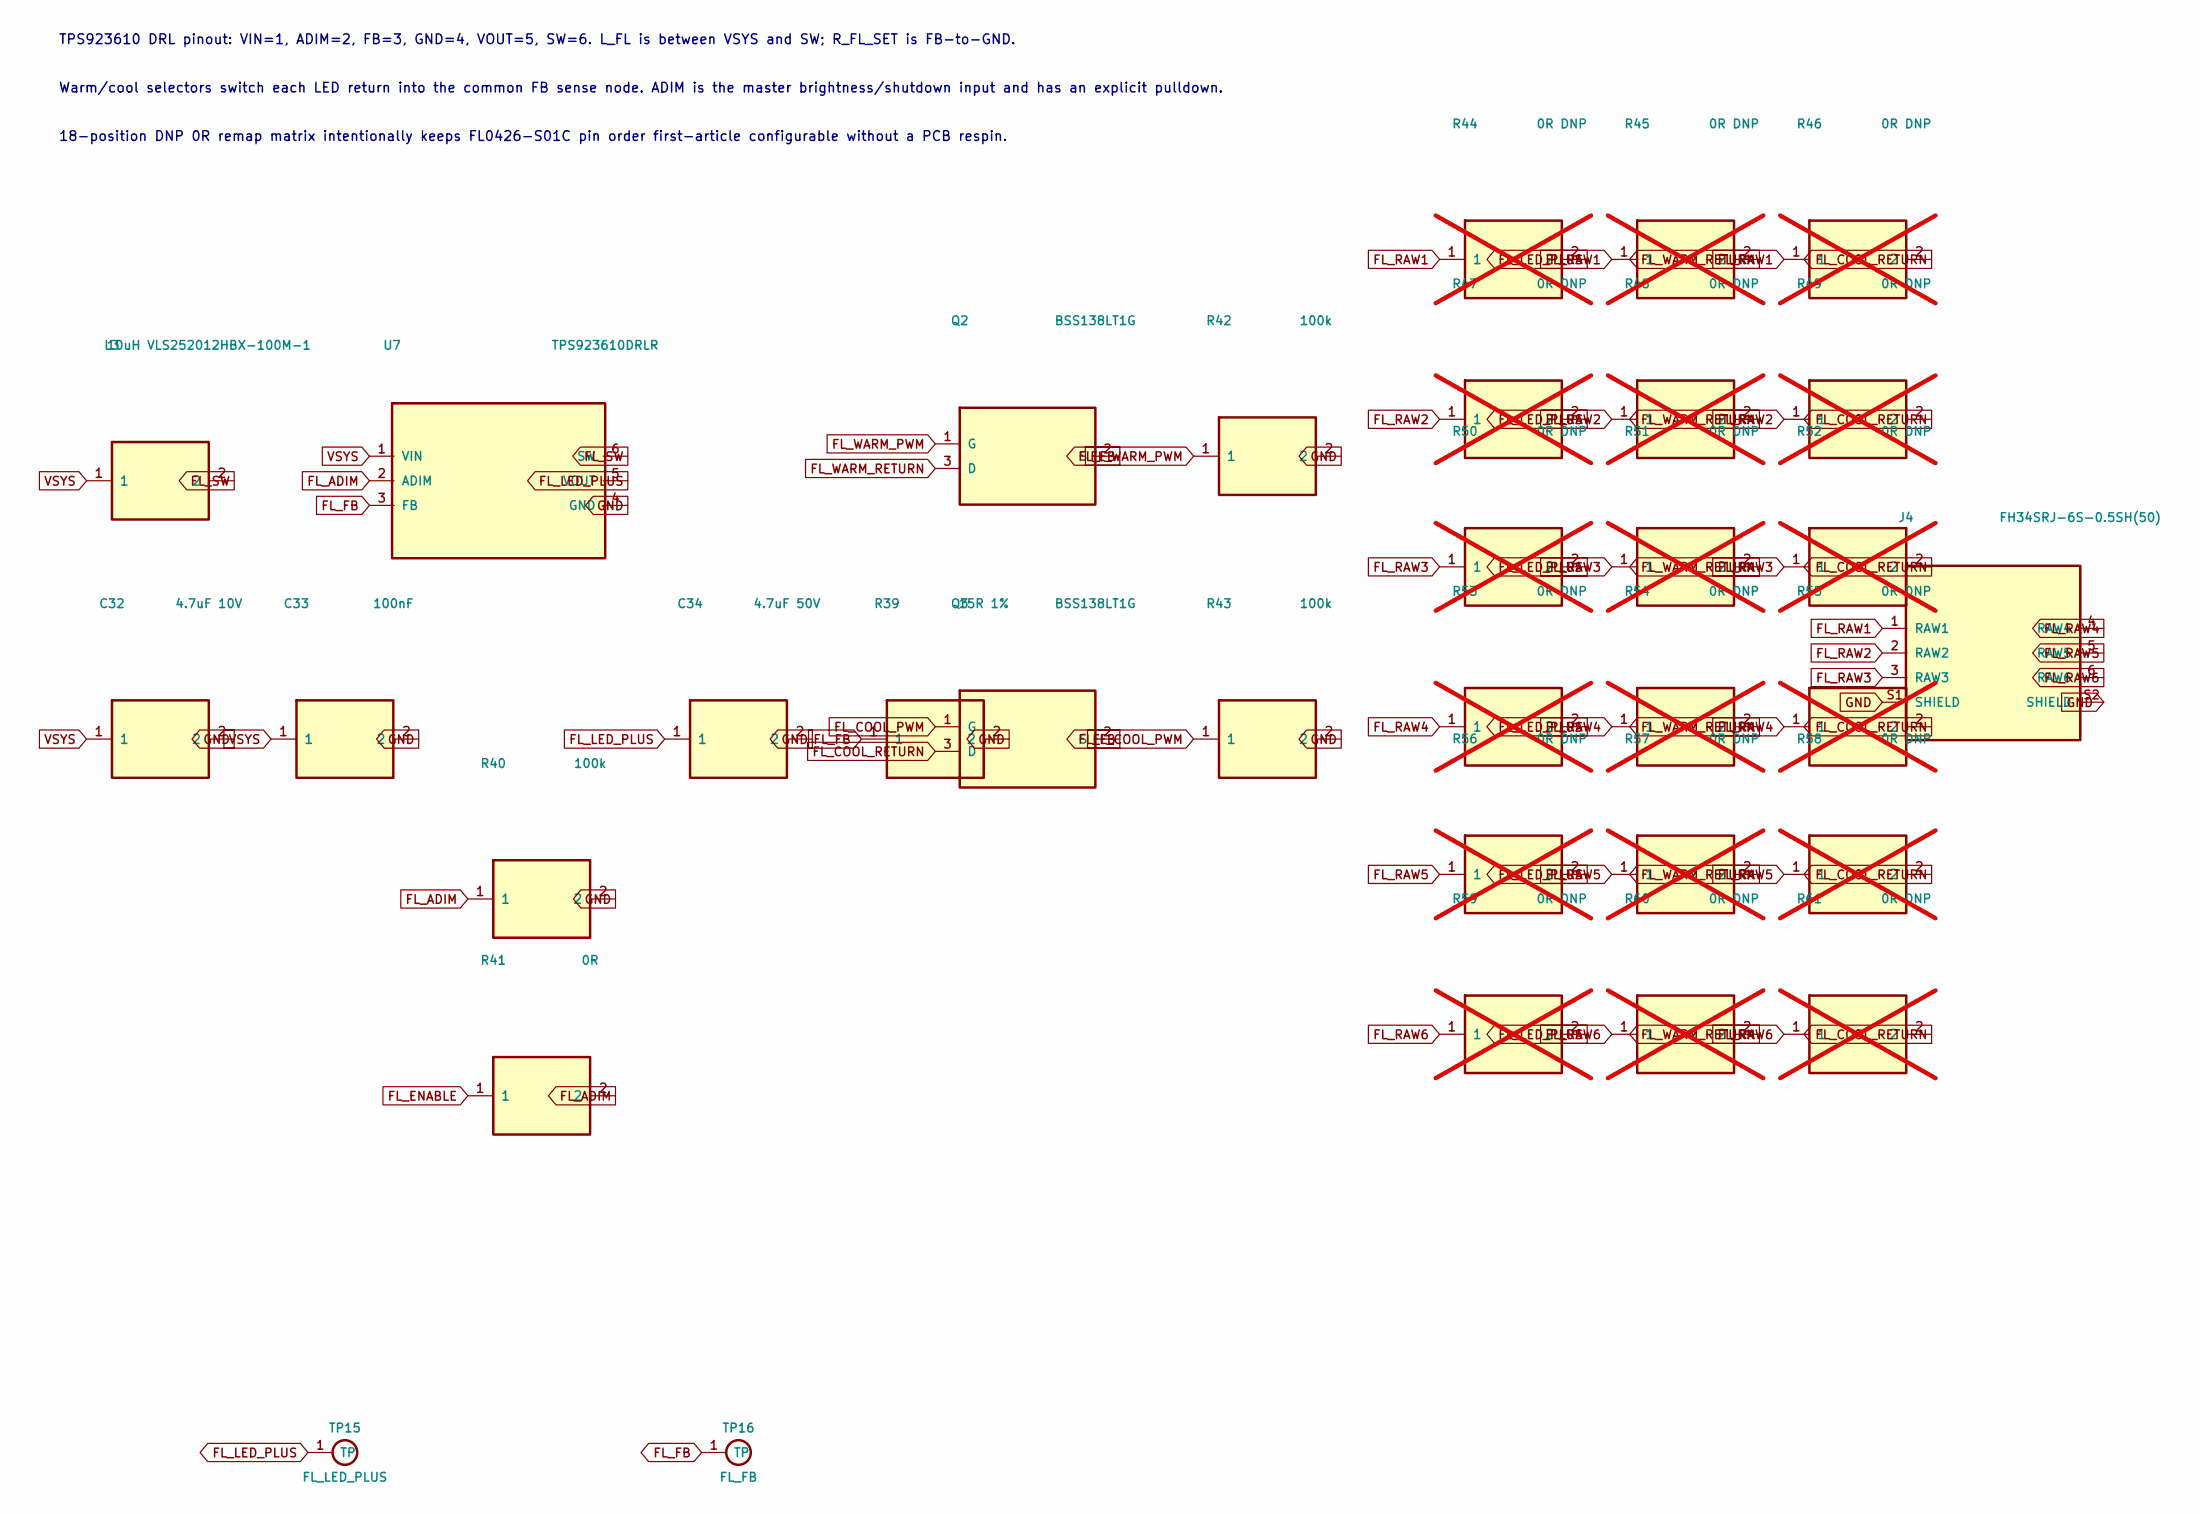
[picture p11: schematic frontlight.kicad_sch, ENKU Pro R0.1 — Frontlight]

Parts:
C32: 4.7uF 10V; C_0805_2012Metric
C33: 100nF; C_0603_1608Metric
C34: 4.7uF 50V; C_0805_2012Metric
J4: FH34SRJ-6S-0.5SH(50); FH34SRJ-6S-0.5SH
L3: 10uH VLS252012HBX-100M-1; TDK_VLS252012
Q2, Q3: BSS138LT1G; SOT-23
R39: 15R 1%; R_0603_1608Metric
R40, R42, R43: 100k; R_0603_1608Metric
R41: 0R; R_0603_1608Metric
R44, R45, R46, R47, R48, R49, R50, R51, R52, R53, R54, R55, R56, R57, R58, R59, R60, R61: 0R DNP; R_0402_1005Metric; not fitted
TP15: FL_LED_PLUS; TestPoint_Pad_D1.5mm
TP16: FL_FB; TestPoint_Pad_D1.5mm
U7: TPS923610DRLR; TPS923610_DRL0006A

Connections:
FL_ADIM: R40.1, R41.2, U7.2 (ADIM)
FL_COOL_PWM: Q3.1 (G), R43.1; also elsewhere on the board
FL_COOL_RETURN: Q3.3 (D), R46.2, R49.2, R52.2, R55.2, R58.2, R61.2
FL_ENABLE: R41.1; also elsewhere on the board
FL_FB: Q2.2 (S), Q3.2 (S), R39.1, TP16.1, U7.3 (FB)
FL_LED_PLUS: C34.1, R44.2, R47.2, R50.2, R53.2, R56.2, R59.2, TP15.1, U7.5 (VOUT)
FL_RAW1: J4.1 (RAW1), R44.1, R45.1, R46.1
FL_RAW2: J4.2 (RAW2), R47.1, R48.1, R49.1
FL_RAW3: J4.3 (RAW3), R50.1, R51.1, R52.1
FL_RAW4: J4.4 (RAW4), R53.1, R54.1, R55.1
FL_RAW5: J4.5 (RAW5), R56.1, R57.1, R58.1
FL_RAW6: J4.6 (RAW6), R59.1, R60.1, R61.1
FL_SW: L3.2, U7.6 (SW)
FL_WARM_PWM: Q2.1 (G), R42.1; also elsewhere on the board
FL_WARM_RETURN: Q2.3 (D), R45.2, R48.2, R51.2, R54.2, R57.2, R60.2
GND: C32.2, C33.2, C34.2, J4.S1 (SHIELD), J4.S2 (SHIELD), R39.2, R40.2, R42.2, R43.2, U7.4 (GND); also elsewhere on the board
VSYS: C32.1, C33.1, L3.1, U7.1 (VIN); also elsewhere on the board

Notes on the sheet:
TPS923610 DRL pinout: VIN=1, ADIM=2, FB=3, GND=4, VOUT=5, SW=6. L_FL is between VSYS and SW; R_FL_SET is FB-to-GND.
Warm/cool selectors switch each LED return into the common FB sense node. ADIM is the master brightness/shutdown input and has an explicit pulldown.
18-position DNP 0R remap matrix intentionally keeps FL0426-S01C pin order first-article configurable without a PCB respin.

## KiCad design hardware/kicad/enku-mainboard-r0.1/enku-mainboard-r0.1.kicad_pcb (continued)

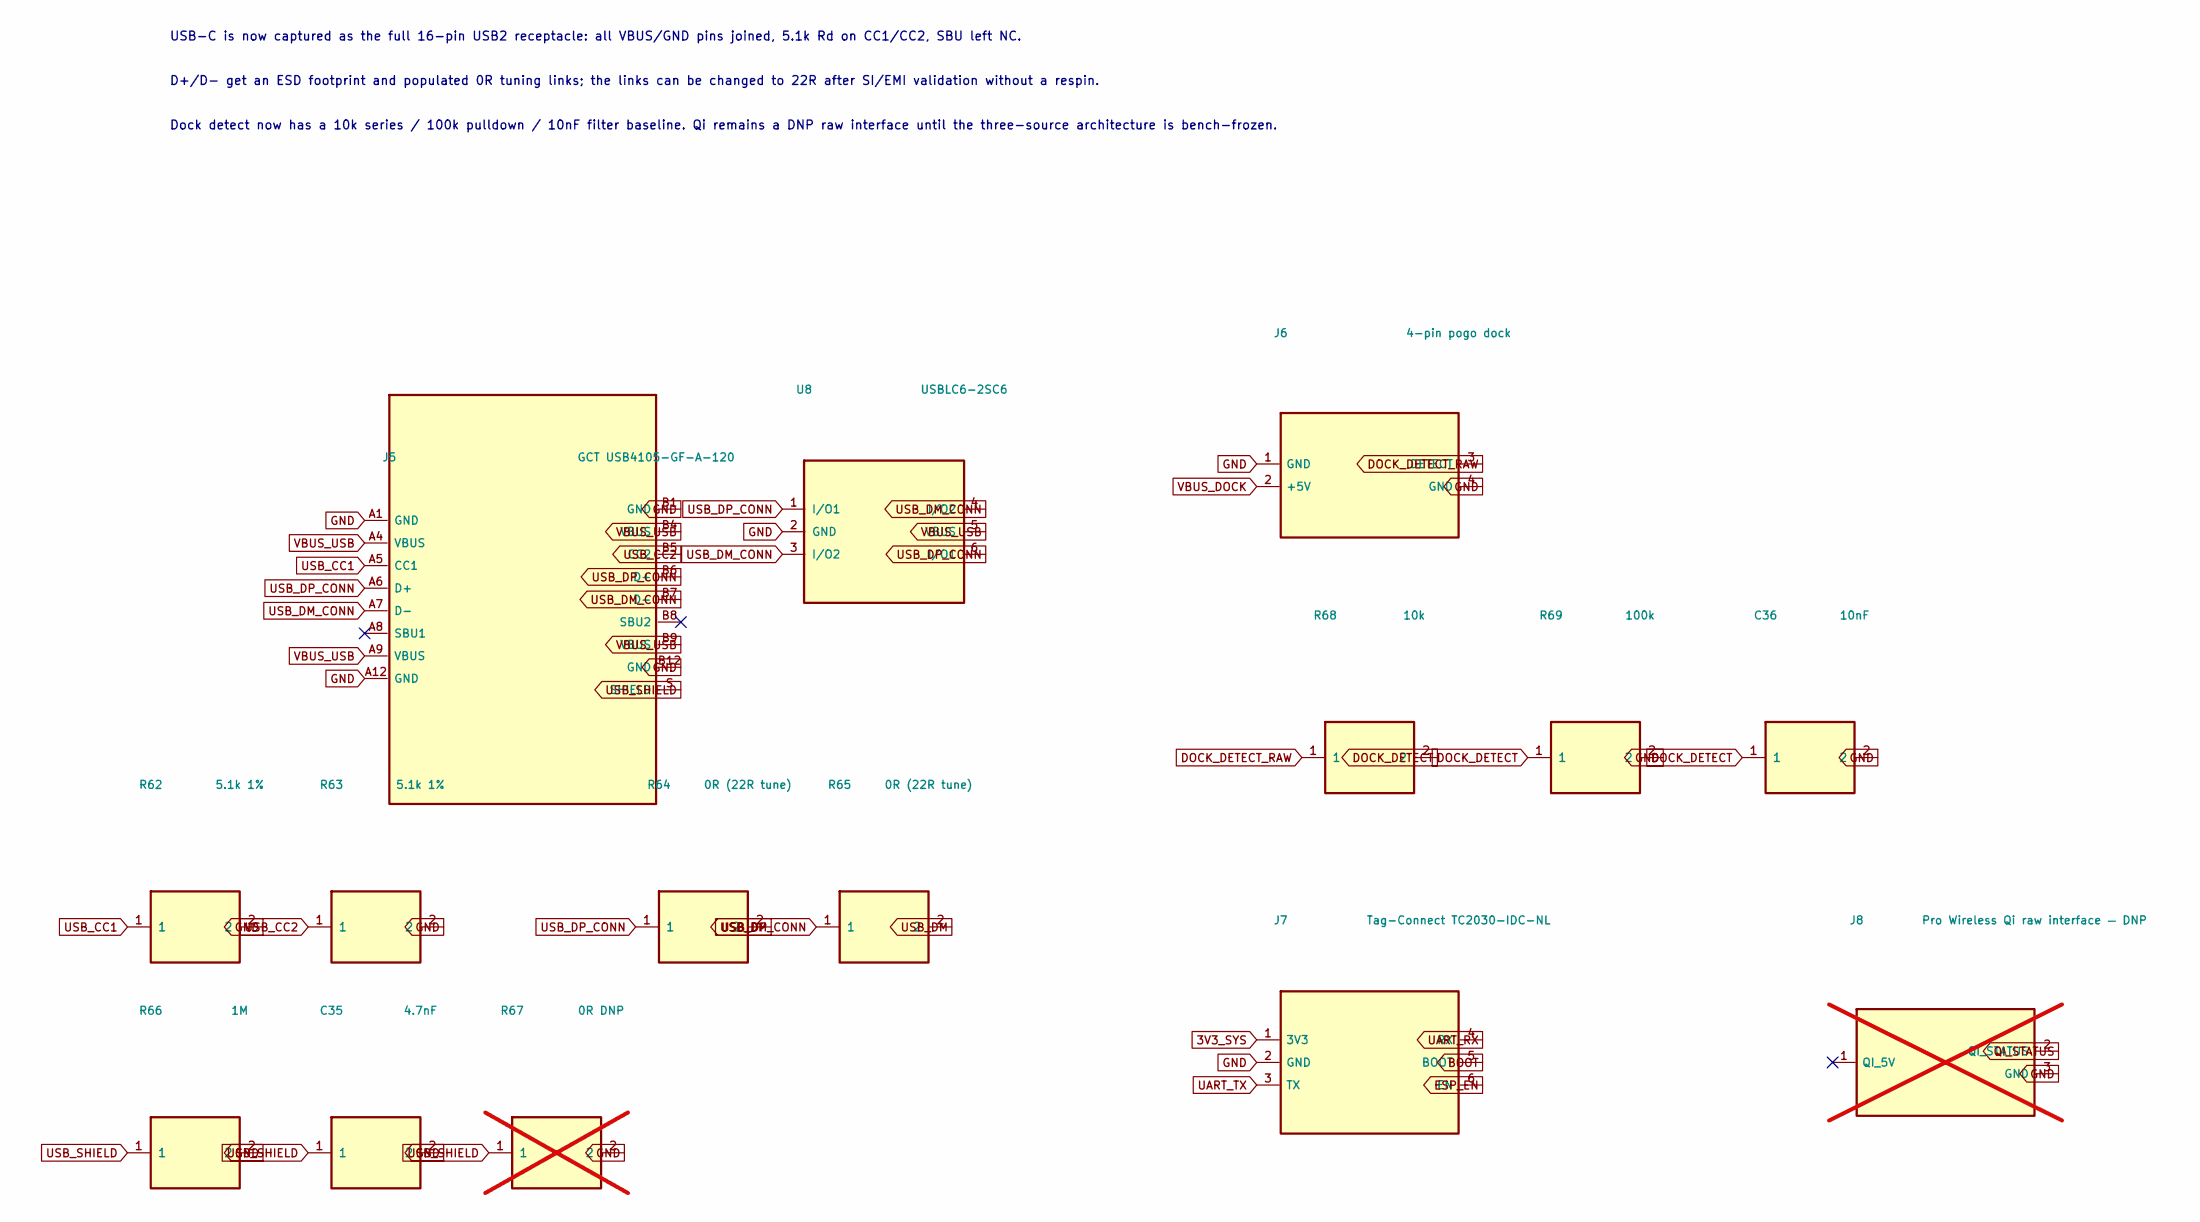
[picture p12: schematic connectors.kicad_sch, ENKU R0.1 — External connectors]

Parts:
C35: 4.7nF; C_0603_1608Metric
C36: 10nF; C_0603_1608Metric
J5: GCT USB4105-GF-A-120; USB_C_Receptacle_GCT_USB4105-xx-A_16P_TopMnt_Horizontal
J6: 4-pin pogo dock; DOCK_POGO_4
J7: Tag-Connect TC2030-IDC-NL; Tag-Connect_TC2030-IDC-NL_2x03_P1.27mm_Vertical
J8: Pro Wireless Qi raw interface — DNP; QI_RAW_3; not fitted
R62, R63: 5.1k 1%; R_0603_1608Metric
R64, R65: 0R (22R tune); R_0603_1608Metric
R66: 1M; R_0603_1608Metric
R67: 0R DNP; R_0603_1608Metric; not fitted
R68: 10k; R_0603_1608Metric
R69: 100k; R_0603_1608Metric
U8: USBLC6-2SC6; SOT-23-6

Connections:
3V3_SYS: J7.1 (3V3); also elsewhere on the board
BOOT: J7.5 (BOOT); also elsewhere on the board
DOCK_DETECT: C36.1, R68.2, R69.1; also elsewhere on the board
DOCK_DETECT_RAW: J6.3 (DETECT), R68.1
ESP_EN: J7.6 (EN); also elsewhere on the board
GND: C35.2, C36.2, J5.A1 (GND), J5.A12 (GND), J5.B1 (GND), J5.B12 (GND), J6.1 (GND), J6.4 (GND), J7.2 (GND), J8.3 (GND), R62.2, R63.2, R66.2, R67.2, R69.2, U8.2 (GND); also elsewhere on the board
QI_STATUS: J8.2 (QI_STATUS); also elsewhere on the board
UART_RX: J7.4 (RX); also elsewhere on the board
UART_TX: J7.3 (TX); also elsewhere on the board
USB_CC1: J5.A5 (CC1), R62.1
USB_CC2: J5.B5 (CC2), R63.1
USB_DM: R65.2; also elsewhere on the board
USB_DM_CONN: J5.A7 (D-), J5.B7 (D-), R65.1, U8.3 (I/O2), U8.4 (I/O2)
USB_DP: R64.2; also elsewhere on the board
USB_DP_CONN: J5.A6 (D+), J5.B6 (D+), R64.1, U8.1 (I/O1), U8.6 (I/O1)
USB_SHIELD: C35.1, J5.S (SHIELD), R66.1, R67.1
VBUS_DOCK: J6.2 (+5V); also elsewhere on the board
VBUS_USB: J5.A4 (VBUS), J5.A9 (VBUS), J5.B4 (VBUS), J5.B9 (VBUS), U8.5 (VBUS); also elsewhere on the board

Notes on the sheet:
USB-C is now captured as the full 16-pin USB2 receptacle: all VBUS/GND pins joined, 5.1k Rd on CC1/CC2, SBU left NC.
D+/D- get an ESD footprint and populated 0R tuning links; the links can be changed to 22R after SI/EMI validation without a respin.
Dock detect now has a 10k series / 100k pulldown / 10nF filter baseline. Qi remains a DNP raw interface until the three-source architecture is bench-frozen.

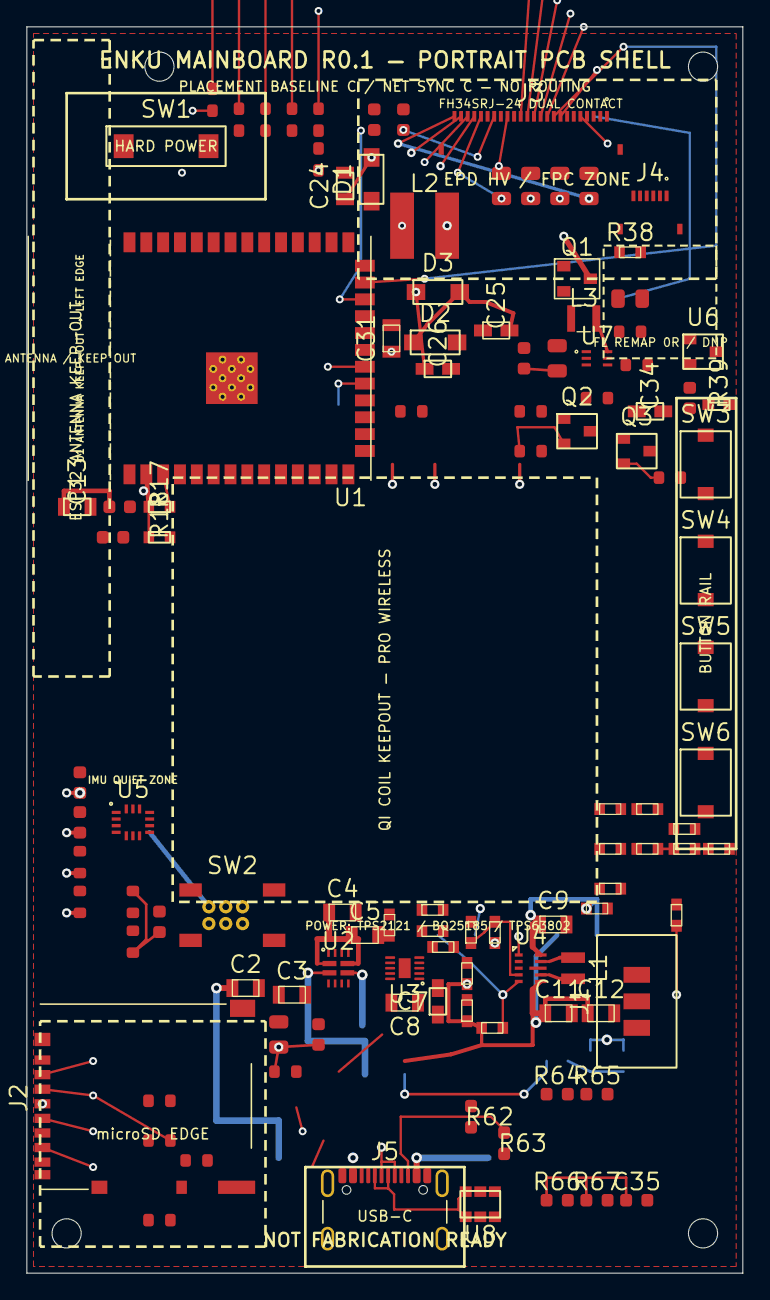
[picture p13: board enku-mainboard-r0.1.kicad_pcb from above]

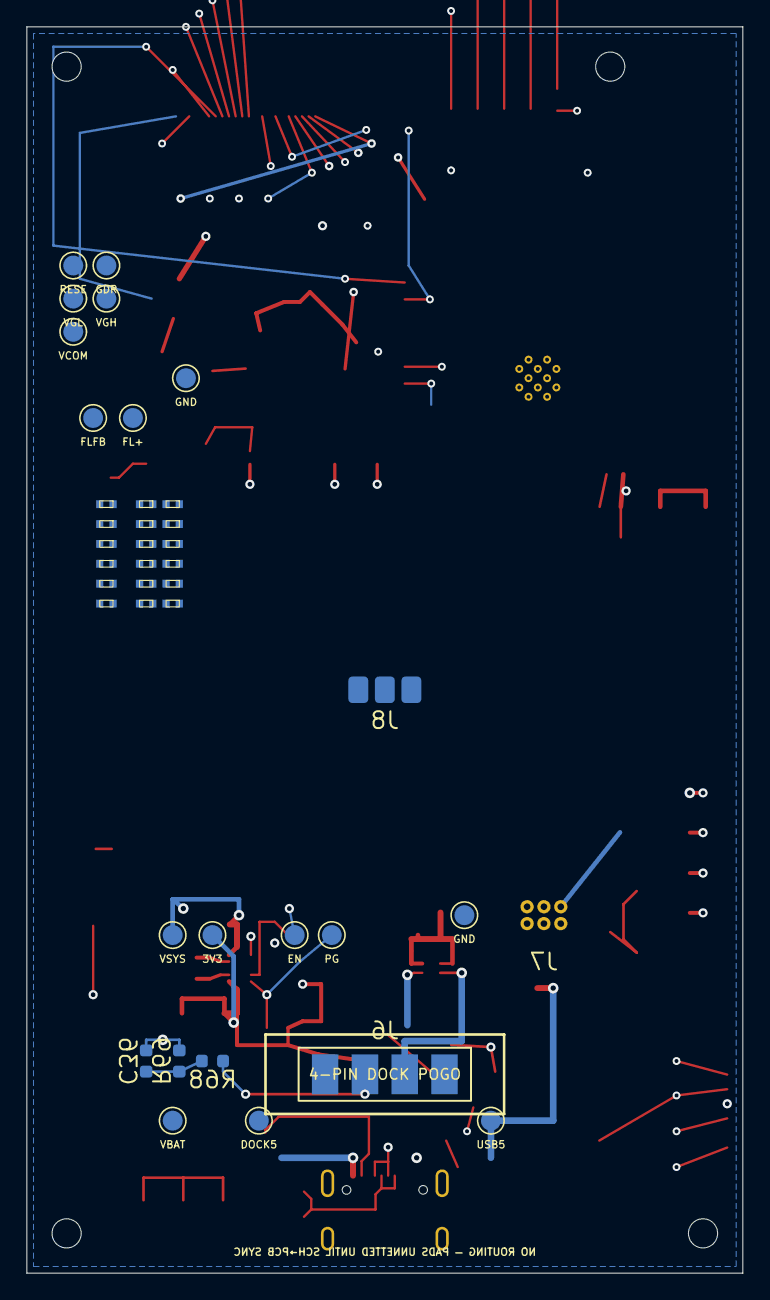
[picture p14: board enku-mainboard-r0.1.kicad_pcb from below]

Board: 4 copper layers, 54.0 x 94.0 mm, 156 parts (40 on the bottom side), 92 nets.

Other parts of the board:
H1, H2, H3, H4: MountingHole_2.2mm_M2

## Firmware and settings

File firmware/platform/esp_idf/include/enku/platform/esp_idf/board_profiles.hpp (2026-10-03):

#pragma once

#include "enku/core/board_profile.hpp"

namespace enku::platform::esp_idf::board_profiles {
namespace detail {

constexpr BoardCapabilities waveshareCapabilities() {
    BoardCapabilities value;
    value.has_psram = true;
    value.has_removable_storage = true;
    value.has_native_usb = true;
    value.has_battery_measurement = true;
    value.reading_controls = 4;
    value.storage_bus = StorageBus::SdMmc4Bit;
    value.display_controller =
        DisplayControllerFamily::Ssd1677;
    value.display_width = 800;
    value.display_height = 480;
    value.landscape = true;
    value.inverted_portrait = true;
    value.inverted_landscape = true;
    return value;
}

constexpr BoardCapabilities enkuBaseCapabilities() {
    BoardCapabilities value;
    value.has_psram = true;
    value.has_removable_storage = true;
    value.has_native_usb = true;
    value.has_hard_power_switch = true;
    value.has_battery_measurement = true;
    value.has_imu = true;
    value.has_hall_sensor = true;
    value.has_dock_detect = true;
    value.supports_rtc_wake_sources = true;
    value.reading_controls = 4;
    value.storage_bus = StorageBus::Spi;
    value.display_controller =
        DisplayControllerFamily::Ssd1677;
    value.display_width = 800;
    value.display_height = 480;
    value.landscape = true;
    value.inverted_portrait = true;
    value.inverted_landscape = true;
    return value;
}

constexpr BoardCapabilities enkuProCapabilities(
    bool wireless
) {
    auto value = enkuBaseCapabilities();
    value.has_frontlight = true;
    value.has_dual_channel_frontlight = true;
    value.has_wireless_charging = wireless;
    return value;
}

} // namespace detail

inline constexpr BoardProfile
    kWaveshareEsp32S3Epaper397{
        BoardProfileId::WaveshareEsp32S3Epaper397,
        BoardProfileMaturity::ReferenceHardware,
        "Waveshare ESP32-S3 ePaper 3.97",
        detail::waveshareCapabilities(),
    };

inline constexpr BoardProfile kEnkuR01Base{
    BoardProfileId::EnkuR01Base,
    BoardProfileMaturity::DesignTarget,
    "ENKU R0.1 Base",
    detail::enkuBaseCapabilities(),
};

inline constexpr BoardProfile kEnkuR01Pro{
    BoardProfileId::EnkuR01Pro,
    BoardProfileMaturity::DesignTarget,
    "ENKU R0.1 Pro",
    detail::enkuProCapabilities(false),
};

inline constexpr BoardProfile kEnkuR01ProWireless{
    BoardProfileId::EnkuR01ProWireless,
    BoardProfileMaturity::DesignTarget,
    "ENKU R0.1 Pro Wireless",
    detail::enkuProCapabilities(true),
};

} // namespace enku::platform::esp_idf::board_profiles

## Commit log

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2026-10-02 Fix open-source commercialization and power cost policy
2026-10-02 Add power quality and cost shortlist to BOM architecture
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2026-10-03 Fix dark theme surfaces tables buttons and callouts
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2026-10-03 Start real R0.1 display and frontlight placement on KiCad PCB
    [enku-mainboard-r0.1.kicad_pcb]
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2026-10-03 Add direct R0.1 navigation buttons to MCU sheet
    [mcu_io.kicad_sch]
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2026-10-03 Expand R0.1 power sheet to exact IC pins and passives
    [power.kicad_sch]
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2026-10-03 Expand SSD1677 EPD HV reference circuit to discretes
    [epd_hv.kicad_sch]
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2026-10-03 Expand MCU IO with exact BMI270 Hall microSD circuits
    [mcu_io.kicad_sch]
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2026-10-03 Add R0.1 placement baseline B for MCU power and IO
    [enku-mainboard-r0.1.kicad_pcb]
2026-10-03 Resolve R0.1 placement baseline B mechanical clashes
    [enku-mainboard-r0.1.kicad_pcb]
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2026-10-03 Start R0.1 PCB net sync for verified connector and display islands
    [enku-mainboard-r0.1.kicad_pcb]
2026-10-03 Fix ESP32-S3-WROOM-1 pins 40 and 41 ground
    [mcu_io.kicad_sch]
2026-10-03 Replace U1 with exact ESP32-S3-WROOM-1 land pattern and nets
    [enku-mainboard-r0.1.kicad_pcb]
2026-10-03 Align EPD boost baseline with current 3.97-inch application circuit
    [epd_hv.kicad_sch]
2026-10-03 Update EPD placement for 10uH reference and GDR bias
    [enku-mainboard-r0.1.kicad_pcb]
2026-10-03 Fix U1 orientation in PCB placement gate
2026-10-03 Strengthen R0.1 schematic reference checks
2026-10-03 Upgrade R0.1 3V3 rail to TPS63802 high-current buck-boost
    [power.kicad_sch]
2026-10-03 Upgrade PCB power island to TPS63802 and exact support network
    [enku-mainboard-r0.1.kicad_pcb]
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2026-10-03 Place R0.1 bring-up test pads on rear copper
    [enku-mainboard-r0.1.kicad_pcb]
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2026-10-03 Replace resolved PCB placeholders with exact land patterns
    [enku-mainboard-r0.1.kicad_pcb]
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2026-10-03 Gate exact first-spin footprints and ban resolved placeholders
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2026-10-03 Replace core placement placeholders with verified footprints and nets
    [enku-mainboard-r0.1.kicad_pcb]
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2026-10-03 Gate schematic bindings to verified local footprints
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2026-10-03 Synchronize PCB footprint links and manufacturer land patterns
    [enku-mainboard-r0.1.kicad_pcb]
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2026-10-03 Fix canonical TYS5040 footprint token in placement gate
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2026-10-03 Place EPD and frontlight schematic passives on PCB
    [enku-mainboard-r0.1.kicad_pcb]
2026-10-03 Place MCU storage IMU Hall and boot support on PCB
    [enku-mainboard-r0.1.kicad_pcb]
2026-10-03 Normalize rotated footprint pad angles and clear EPD VGL collision
    [enku-mainboard-r0.1.kicad_pcb]
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2026-10-03 Freeze USB ESD and use virtual factory debug footprint
    [connectors.kicad_sch]
2026-10-03 Orient ESP32 antenna keepout toward left board edge
    [enku-mainboard-r0.1.kicad_pcb]
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2026-10-03 Correct ESP32 antenna orientation in placement notes
2026-10-03 Correct ESP32 antenna orientation in first-spin review
2026-10-03 Clear core placement shorts and space frontlight remap
    [enku-mainboard-r0.1.kicad_pcb]
2026-10-03 Clear remaining first-pass PCB copper collisions
    [enku-mainboard-r0.1.kicad_pcb]
2026-10-03 Move MCU support and 3V3 HF cap clear of Qi keepout
    [enku-mainboard-r0.1.kicad_pcb]
2026-10-03 Fix MCU support pad net syntax
    [enku-mainboard-r0.1.kicad_pcb]
2026-10-03 Regress reader relayout position stability
2026-10-03 Eliminate remaining core copper shorts
    [enku-mainboard-r0.1.kicad_pcb]
2026-10-03 Eliminate residual EPD and frontlight placement shorts
    [enku-mainboard-r0.1.kicad_pcb]
2026-10-03 Clear final EPD placement shorts
    [enku-mainboard-r0.1.kicad_pcb]
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2026-10-03 Fix KiCad pin-label Y transform in power
    [power.kicad_sch]
2026-10-03 Fix KiCad pin-label Y transform in mcu_io
    [mcu_io.kicad_sch]
2026-10-03 Fix KiCad pin-label Y transform in epd_hv
    [epd_hv.kicad_sch]
2026-10-03 Fix KiCad pin-label Y transform in frontlight
    [frontlight.kicad_sch]
2026-10-03 Fix KiCad pin-label Y transform in connectors
    [connectors.kicad_sch]
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2026-10-03 Correct connector and duplicated power-pin ERC semantics
    [power.kicad_sch]
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2026-10-03 Mark intentionally unused pins NC and clean debug connector ERC
    [connectors.kicad_sch, enku-mainboard-r0.1.kicad_pcb, mcu_io.kicad_sch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]
2026-10-03 Treat dock ground contacts as passive connector pins
    [connectors.kicad_sch]
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2026-10-03 Treat EPD shield contacts as passive connector pins
    [epd_hv.kicad_sch]
2026-10-03 Normalize R0.1 schematic connectivity to KiCad 50mil grid
    [connectors.kicad_sch, epd_hv.kicad_sch, frontlight.kicad_sch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]
2026-10-03 Treat EPD FPC shield tabs as passive contacts
    [epd_hv.kicad_sch]
2026-10-03 Treat frontlight shield contacts as passive connector pins
    [frontlight.kicad_sch]
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2026-10-03 Fix embedded microSD VSS pin semantics
    [mcu_io.kicad_sch]
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2026-10-03 Fix BMI270 ground semantics at library source
2026-10-03 Sync corrected BMI270 ground semantics
    [mcu_io.kicad_sch]
2026-10-03 Fix TPS2121 ground semantics at library source
2026-10-03 Correct TPS2121 pin 12 ground semantics
2026-10-03 Resync corrected TPS2121 symbol definition
    [power.kicad_sch]
2026-10-03 Resync BMI270 from corrected library source
    [mcu_io.kicad_sch]
2026-10-03 Correct BMI270 ground pins at library source
2026-10-03 Resync corrected BMI270 symbol definition
    [mcu_io.kicad_sch]
2026-10-03 Correct USB ESD ground at library source
2026-10-03 Resync corrected USB ESD symbol definition
    [connectors.kicad_sch]
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2026-10-03 Resolve EPD HV island pad clearances
    [enku-mainboard-r0.1.kicad_pcb]
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2026-10-03 Tighten EPD VGH switching diode placement
    [enku-mainboard-r0.1.kicad_pcb]
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2026-10-03 Increase EPD SW clearance from Q control pin
    [enku-mainboard-r0.1.kicad_pcb]
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2026-10-03 Route EPD SW to corrected fly capacitor pad
    [enku-mainboard-r0.1.kicad_pcb]
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2026-10-03 Increase EPD SW clearance from RESE ground pad
    [enku-mainboard-r0.1.kicad_pcb]
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2026-10-03 Route compact EPD SW branch to fly capacitor
    [enku-mainboard-r0.1.kicad_pcb]
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2026-10-03 Route EPD fly capacitor left of CP_NEG diode
    [enku-mainboard-r0.1.kicad_pcb]
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2026-10-03 Shift EPD D2 clear of MCU and input capacitor
    [enku-mainboard-r0.1.kicad_pcb]
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2026-10-03 Shift lowered EPD D2 clear of VCI capacitor
    [enku-mainboard-r0.1.kicad_pcb]
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2026-10-03 Reroute EPD CP_NEG around switch and ground pads
    [enku-mainboard-r0.1.kicad_pcb]
2026-10-03 Fix valid board profile regression fixture
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2026-10-03 Route EPD switch node around charge pump diode
    [enku-mainboard-r0.1.kicad_pcb]
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2026-10-03 Shift EPD fly capacitor clear of D2 ground
    [enku-mainboard-r0.1.kicad_pcb]
2026-10-03 Give EPD fly capacitor routing clearance
    [enku-mainboard-r0.1.kicad_pcb]
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2026-10-03 Route EPD switch node to repacked fly capacitor
    [enku-mainboard-r0.1.kicad_pcb]
2026-10-03 Route EPD switch node under charge pump cluster
    [enku-mainboard-r0.1.kicad_pcb]
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2026-10-03 Route EPD switch diode branch below VCI inductor
    [enku-mainboard-r0.1.kicad_pcb]
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2026-10-03 Show recovery screen when SD mount fails
2026-10-03 Correct EPD VGH pad routing
    [enku-mainboard-r0.1.kicad_pcb]
2026-10-03 Route EPD VGH capacitor branch below ground pad
    [enku-mainboard-r0.1.kicad_pcb]
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2026-10-03 Repack EPD VGL capacitor for shorter routing
    [enku-mainboard-r0.1.kicad_pcb]
2026-10-03 Separate EPD VGL from SW and VGH vias
    [enku-mainboard-r0.1.kicad_pcb]
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2026-10-03 Nudge final EPD VGL via clear of capacitor ground
    [enku-mainboard-r0.1.kicad_pcb]
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2026-10-03 Revert unsafe EPD VCI corridor attempt
    [enku-mainboard-r0.1.kicad_pcb]
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2026-10-03 Fix PCB syntax after VCI reroute
    [enku-mainboard-r0.1.kicad_pcb]
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2026-10-03 Refine EPD VCI endpoint clearances
    [enku-mainboard-r0.1.kicad_pcb]
2026-10-03 Keep lower EPD VCI branch off ESP32 pads
    [enku-mainboard-r0.1.kicad_pcb]
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2026-10-03 Dogleg EPD VDD around VGL and VSH1 ground
    [enku-mainboard-r0.1.kicad_pcb]
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2026-10-03 Fan out remaining EPD bias rails beyond FPC pads
    [enku-mainboard-r0.1.kicad_pcb]
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2026-10-03 Reset bias rail routing to last DRC-green baseline
    [enku-mainboard-r0.1.kicad_pcb]
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2026-10-03 Spread EPD bias fanouts into outer routing corridors
    [enku-mainboard-r0.1.kicad_pcb]
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2026-10-03 Show bootstrap recovery for board and state failures
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2026-10-03 Move EPD VSL VCOM endpoints clear of frontlight controls
    [enku-mainboard-r0.1.kicad_pcb]
2026-10-03 Shorten EPD bias final fanouts around frontlight
    [enku-mainboard-r0.1.kicad_pcb]
2026-10-03 Lift EPD VSL above VGL corridor and VSH2 clear of C7
    [enku-mainboard-r0.1.kicad_pcb]
2026-10-03 Route VSL below HV core and shorten VSH2 approach
    [enku-mainboard-r0.1.kicad_pcb]
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2026-10-03 Keep VSL south of VCI clearance envelope
    [enku-mainboard-r0.1.kicad_pcb]
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2026-10-03 Reroute EPD VSH2 VSL VCOM outside frontlight cluster
    [enku-mainboard-r0.1.kicad_pcb]
2026-10-03 Keep EPD bias returns on inner layers to local fanout
    [enku-mainboard-r0.1.kicad_pcb]
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2026-10-03 Revert unsafe EPD GDR RESE route before signal bundle
    [enku-mainboard-r0.1.kicad_pcb]
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2026-10-03 Bring EPD VSL VCOM up beside bias capacitors
    [enku-mainboard-r0.1.kicad_pcb]
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2026-10-03 Move EPD VSH2 to dedicated left inner corridor
    [enku-mainboard-r0.1.kicad_pcb]
2026-10-03 Offset EPD VSH2 corridor from existing HV vias
    [enku-mainboard-r0.1.kicad_pcb]
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2026-10-03 Clear final EPD bias and frontlight critical DRC
    [enku-mainboard-r0.1.kicad_pcb]
2026-10-03 Move EPD VCOM fanout clear of frontlight remap
    [enku-mainboard-r0.1.kicad_pcb]
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2026-10-03 Fix shared fingerprint import refactor
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2026-10-03 Avoid duplicate size probe during import
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2026-10-03 Give availability fixtures real fingerprints
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2026-10-03 ci(hardware): strengthen native KiCad routing gate
2026-10-03 fix(ci): repair KiCad routing summary
2026-10-03 fix(pcb): clear first native DRC geometry errors
    [enku-mainboard-r0.1.kicad_pcb]
2026-10-03 fix(pcb): separate HV crossing and preserve power-row pitch
    [enku-mainboard-r0.1.kicad_pcb]
2026-10-03 fix(pcb): move power rows inward and clear EPD fanout
    [enku-mainboard-r0.1.kicad_pcb]
2026-10-03 fix(pcb): route VGH around VGL via keepout
    [enku-mainboard-r0.1.kicad_pcb]
2026-10-03 pcb: pull power resistors inside edge clearance
    [enku-mainboard-r0.1.kicad_pcb]
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2026-10-03 fix(pcb): clear VGH from VDD through-via corridor
    [enku-mainboard-r0.1.kicad_pcb]
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2026-10-03 fix(pcb): restore power pitch and open HV layer corridor
    [enku-mainboard-r0.1.kicad_pcb]
2026-10-03 pcb: document local 0.4mm CNC edge clearance
2026-10-03 revert(pcb): restore pre-DRC routing baseline
    [enku-mainboard-r0.1.kicad_pcb]
2026-10-03 fix(pcb): match either side of edge-clearance rule
2026-10-03 fix(pcb): move VGH crossing onto existing via layer
    [enku-mainboard-r0.1.kicad_pcb]
2026-10-03 fix(pcb): clear right-edge pads without disturbing row pitch
    [enku-mainboard-r0.1.kicad_pcb]
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2026-10-03 pcb: revert EPD VDD exploratory reroutes
    [enku-mainboard-r0.1.kicad_pcb]
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2026-10-04 ci(hardware): fail zero-component schematic netlist
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2026-10-04 ci(hardware): validate KiCad netlist export correctly
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2026-10-04 pcb: fix USB ESD, shield, and microSD mechanical pad mappings
    [enku-mainboard-r0.1.kicad_pcb]
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2026-10-04 pcb: drop colliding BMI270 route experiment
    [enku-mainboard-r0.1.kicad_pcb]
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2026-10-04 pcb: drop colliding regulator PG branch
    [enku-mainboard-r0.1.kicad_pcb]
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2026-10-04 pcb: restore charger resistor placement before island rework
    [enku-mainboard-r0.1.kicad_pcb]
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2026-10-04 pcb: keep clean regulator switch loop and drop tight rail stubs
    [enku-mainboard-r0.1.kicad_pcb]
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2026-10-04 pcb: close short TPS63802 feedback divider loop
    [enku-mainboard-r0.1.kicad_pcb]
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2026-10-04 pcb: revert charger escape stubs blocked by existing VBUS corridor
    [enku-mainboard-r0.1.kicad_pcb]
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2026-10-04 pcb: keep clean charger status routes and revert dense programming escape
    [enku-mainboard-r0.1.kicad_pcb]
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2026-10-04 pcb: revert charger reflow trial to verified power baseline
    [enku-mainboard-r0.1.kicad_pcb]
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2026-10-04 pcb: reset and rebuild U2-U3 power path from local loops outward
    [enku-mainboard-r0.1.kicad_pcb]
2026-10-04 pcb: correct charger power fanout from native DRC findings
    [enku-mainboard-r0.1.kicad_pcb]
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2026-10-04 pcb: resolve final critical charger island clearances
    [enku-mainboard-r0.1.kicad_pcb]
2026-10-04 pcb: separate charger controls from 3V3 and mux clearances
    [enku-mainboard-r0.1.kicad_pcb]
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2026-10-04 pcb: drop orphan VBUS lead from pre-reset charger route
    [enku-mainboard-r0.1.kicad_pcb]
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2026-10-04 pcb: tune BAT and ILIM stagger clearances
    [enku-mainboard-r0.1.kicad_pcb]
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2026-10-04 pcb: flip C6 polarity orientation away from ground copper
    [enku-mainboard-r0.1.kicad_pcb]
2026-10-04 pcb: add C6 clearance margin from C5 ground pad
    [enku-mainboard-r0.1.kicad_pcb]
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2026-10-04 pcb: tighten battery connector power path
    [enku-mainboard-r0.1.kicad_pcb]
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2026-10-04 pcb: keep CC2 unrouted pending USB-C escape redesign
    [enku-mainboard-r0.1.kicad_pcb]
2026-10-04 pcb: relocate USB-C Rd resistors for short CC escape
    [enku-mainboard-r0.1.kicad_pcb]
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2026-10-04 pcb: correct USB-C CC pad orientation and escape
    [enku-mainboard-r0.1.kicad_pcb]
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2026-10-04 pcb: remove failed USB data escape before ESD relocation
    [enku-mainboard-r0.1.kicad_pcb]
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2026-10-04 pcb: split Type-C D+ and D- escapes above and below pin row
    [enku-mainboard-r0.1.kicad_pcb]
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2026-10-04 pcb: isolate corrected CC routing before USB data pass
    [enku-mainboard-r0.1.kicad_pcb]
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2026-10-04 pcb: revert failed USB output route and keep closure baseline clean
    [enku-mainboard-r0.1.kicad_pcb]
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2026-10-04 pcb: correct 3V3 decoupling escape around ground pads
    [enku-mainboard-r0.1.kicad_pcb]
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2026-10-04 pcb: revert invalid frontlight matrix bus experiment
    [enku-mainboard-r0.1.kicad_pcb]
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2026-10-04 pcb: revert RAW1 row pending frontlight placement refactor
    [enku-mainboard-r0.1.kicad_pcb]
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2026-10-04 pcb: remove failed frontlight RAW escape geometry
    [enku-mainboard-r0.1.kicad_pcb]
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2026-10-04 pcb: revert unsafe J4 RAW perimeter fanout
    [enku-mainboard-r0.1.kicad_pcb]
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2026-10-04 pcb: revert crossing frontlight return bus experiment
    [enku-mainboard-r0.1.kicad_pcb]
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2026-10-04 pcb: revert front-copper common bus experiment
    [enku-mainboard-r0.1.kicad_pcb]
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2026-10-04 pcb: revert conflicting frontlight lower-corridor links
    [enku-mainboard-r0.1.kicad_pcb]
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2026-10-04 pcb: revert staggered frontlight corridor conflicts
    [enku-mainboard-r0.1.kicad_pcb]
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2026-10-04 pcb: revert dense driver-core inner routing experiment
    [enku-mainboard-r0.1.kicad_pcb]
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2026-10-04 pcb: correct frontlight driver orientation
    [enku-mainboard-r0.1.kicad_pcb]
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2026-10-04 pcb: revert frontlight regulator core crossing experiment
    [enku-mainboard-r0.1.kicad_pcb]
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2026-10-04 pcb: correct J4 copper width for 0.5mm FPC pitch
    [enku-mainboard-r0.1.kicad_pcb]
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2026-10-04 pcb: revert EPD signal fanout across HV field
    [enku-mainboard-r0.1.kicad_pcb]
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2026-10-04 pcb: revert backside EPD lane extension conflicts
    [enku-mainboard-r0.1.kicad_pcb]
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2026-10-04 pcb: revert crowded EPD row landing experiment
    [enku-mainboard-r0.1.kicad_pcb]
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2026-10-04 pcb: correct rotated EPD resistor pad landings
    [enku-mainboard-r0.1.kicad_pcb]
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2026-10-04 pcb: revert conflicting EPD MCU fan-in before corridor rebuild
    [enku-mainboard-r0.1.kicad_pcb]
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2026-10-04 pcb: revert unsafe EPD SPI source corridor
    [enku-mainboard-r0.1.kicad_pcb]
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2026-10-04 pcb: revert unsafe EPD busy MCU extension
    [enku-mainboard-r0.1.kicad_pcb]
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2026-10-04 pcb: revert disconnected inner-layer EPD SPI test
    [enku-mainboard-r0.1.kicad_pcb]
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2026-10-04 pcb: revert EPD row placement into frontlight escape
    [enku-mainboard-r0.1.kicad_pcb]
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2026-10-04 pcb: route EPD BS1 around relocated reset row
    [enku-mainboard-r0.1.kicad_pcb]
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2026-10-04 pcb: revert conflicting relocated EPD SPI escape
    [enku-mainboard-r0.1.kicad_pcb]
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2026-10-04 pcb: preserve zero-short four-lane EPD milestone
    [enku-mainboard-r0.1.kicad_pcb]
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2026-10-04 pcb: restore zero-short EPD four-lane baseline
    [enku-mainboard-r0.1.kicad_pcb]
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2026-10-04 pcb: revert unsafe pullup cluster shortcut
    [enku-mainboard-r0.1.kicad_pcb]
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2026-10-04 pcb: restore zero-short EPD routing after cleanup test
    [enku-mainboard-r0.1.kicad_pcb]
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2026-10-04 pcb: restore zero-short checkpoint before EPD source fanout redesign
    [enku-mainboard-r0.1.kicad_pcb]
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2026-10-04 pcb: revert crossing microSD card-side bundle
    [enku-mainboard-r0.1.kicad_pcb]
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2026-10-04 pcb: restore zero-short checkpoint before SD corridor redesign
    [enku-mainboard-r0.1.kicad_pcb]
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2026-10-04 pcb: clear final SD card bundle short
    [enku-mainboard-r0.1.kicad_pcb]
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2026-10-04 pcb: preserve zero-short SD card-side milestone
    [enku-mainboard-r0.1.kicad_pcb]
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2026-10-04 pcb: revert shield row crossing ground pads
    [enku-mainboard-r0.1.kicad_pcb]
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2026-10-04 pcb: preserve zero-short USB connector pair checkpoint
    [enku-mainboard-r0.1.kicad_pcb]
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2026-10-04 pcb: restore zero-short USB connector checkpoint
    [enku-mainboard-r0.1.kicad_pcb]
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2026-10-04 pcb: preserve clean routing before SD local fanout redesign
    [enku-mainboard-r0.1.kicad_pcb]
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2026-10-05 pcb: preserve clean relocated SD row before fanout redesign
    [enku-mainboard-r0.1.kicad_pcb]
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2026-10-05 pcb: finish critical clearance cleanup
    [enku-mainboard-r0.1.kicad_pcb]
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2026-10-05 pcb: move ADIM transition out of U7 clearance envelope
    [enku-mainboard-r0.1.kicad_pcb]
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2026-10-05 pcb: drop ADIM partial escape pending placement rework
    [enku-mainboard-r0.1.kicad_pcb]
2026-10-05 pcb: eliminate residual pad shorts and ESP enable clearance
    [enku-mainboard-r0.1.kicad_pcb]
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2026-10-05 pcb: revert LED+ trunk crossing button rail
    [enku-mainboard-r0.1.kicad_pcb]
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2026-10-05 pcb: revert return trunks conflicting with button rail
    [enku-mainboard-r0.1.kicad_pcb]
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2026-10-05 pcb: revert VSL VCOM inner-layer trial
    [enku-mainboard-r0.1.kicad_pcb]
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2026-10-05 pcb: revert EPD service testpoint trial
    [enku-mainboard-r0.1.kicad_pcb]
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2026-10-05 pcb: revert VCOM route crossing EPD VSL
    [enku-mainboard-r0.1.kicad_pcb]
2026-10-05 pcb: eliminate VSH and warm PWM shorts
    [enku-mainboard-r0.1.kicad_pcb]
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2026-10-05 pcb: correct panel resistor endpoints and separate DC layer
    [enku-mainboard-r0.1.kicad_pcb]
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2026-10-05 pcb: route EPD reset panel with validated pad2 topology
    [enku-mainboard-r0.1.kicad_pcb]
2026-10-05 pcb: move EPD reset source via clear of HV reservoir
    [enku-mainboard-r0.1.kicad_pcb]
2026-10-05 pcb: move EPD reset fanout above HV reservoir
    [enku-mainboard-r0.1.kicad_pcb]
2026-10-05 pcb: straighten reset escape out of fine-pitch FPC
    [enku-mainboard-r0.1.kicad_pcb]
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2026-10-05 pcb: shift EPD BUSY source left of reset corridor
    [enku-mainboard-r0.1.kicad_pcb]
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2026-10-05 pcb: reset unsafe EPD HV fanout and isolate panel logic
    [enku-mainboard-r0.1.kicad_pcb]
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2026-10-05 pcb: give EPD gate switch more pump clearance
    [enku-mainboard-r0.1.kicad_pcb]
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2026-10-05 pcb: reset EPD fanout to collision-free connector escapes
    [enku-mainboard-r0.1.kicad_pcb]
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2026-10-05 pcb: increase EPD switch clearance and isolate RESE return
    [enku-mainboard-r0.1.kicad_pcb]
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

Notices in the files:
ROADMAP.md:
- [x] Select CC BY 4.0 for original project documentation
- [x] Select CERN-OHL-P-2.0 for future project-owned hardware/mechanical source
